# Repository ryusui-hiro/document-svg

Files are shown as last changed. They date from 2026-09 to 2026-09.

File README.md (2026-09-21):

# document-svg

**See every page of a PDF, Word, Excel, PowerPoint, diagram or CAD file as an SVG image — on your own machine, without the app that made it.**

[日本語](README.ja.md) · [简体中文](README.zh-CN.md) ·
[Project site](https://ryusui-hiro.github.io/document-svg/) ·
[Samples](https://ryusui-hiro.github.io/document-svg/samples.html) ·
[Releases](https://github.com/ryusui-hiro/document-svg/releases)






document-svg turns documents, diagrams and technical drawings into ordinary
SVG images, one per page. Any browser can show them, they stay sharp when you
zoom in, and they drop into a web page like any other picture. Alongside the
pages you get a short report that says plainly which parts could not be
reproduced exactly.

It is a converter you build into something else — a website, an internal
tool, a review process or an AI assistant — and it comes as a Node.js
package, a Python package, a Rust library and a command-line tool (`docsvg`).

| PowerPoint | Excel | draw.io | CAD drawing (DXF) |
|---|---|---|---|
| A PowerPoint slide converted to SVG | An Excel sheet converted to SVG | A draw.io diagram converted to SVG | A DXF drawing converted to SVG |

Every image above is an unretouched conversion of a sample file in this repository.

## Why use it

- **Your files stay with you.** Conversion runs on your computer or your own
  server. Nothing is uploaded, there is no account, and nothing is tracked, so
  contracts and design drawings that must not leave the company can still get
  a preview.
- **Anyone can look.** The people reviewing the result don't need Office,
  AutoCAD or a viewer licence — a browser is enough.
- **It tells you what it missed.** No converter reproduces everything. Instead
  of quietly dropping a chart or a font, document-svg lists what it skipped or
  approximated, page by page, so you can decide whether the result is good
  enough to share.
- **Opening a file never runs it.** Macros, scripts, form actions and links to
  outside resources are shown or skipped, never executed. Size and page limits
  stop a huge or broken file from exhausting memory.
- **One tool instead of many.** Office documents, PDFs, diagrams, CAD and 3D
  models, and scientific and business data all go through the same call and
  come out the same way.
- **And the way back.** SVG pages can be packaged back into PowerPoint, Word,
  Excel, draw.io or CAD files.

## What people use it for

- **Seeing document changes in code review.** A GitHub Action converts the
  slides, spreadsheets and PDFs changed in a pull request, instead of leaving
  reviewers with "binary file changed".
- **Previewing uploads in their own app,** without installing Office on the
  server or paying for a viewer SDK.
- **Keeping diagrams in step with the code** by rendering draw.io, Mermaid,
  PlantUML, D2 or Graphviz files every time the documentation is built.
- **Checking drawings and 3D models without CAD** — floor plans, circuit
  boards, machining paths and models — from a web page.
- **Letting an AI assistant read documents** through one dependable step
  instead of screenshots.

Each example is explained in more detail on the [project site](https://ryusui-hiro.github.io/document-svg/use-cases.html).

## Install

Pick the one that matches where you will call it from. You only need one.

| You want to… | Install |
|---|---|
| Convert files from a Node.js or Electron app (Node.js 18 or newer) | `npm install document-svg` |
| Convert files from Python (Python 3.10 or newer) | `python -m pip install document-svg` |
| Use the `docsvg` command, or the Rust library | `cargo install document-svg --locked` / `cargo add document-svg` |

No Rust is needed for the npm and pip packages: they come ready-made for
Windows, macOS and Linux. If you want the command without installing Rust,
download the file for your system from
[Releases](https://github.com/ryusui-hiro/document-svg/releases) and put
`docsvg` on your `PATH`.

### Where to get it and where it goes

| Package | Page | Installed into |
|---|---|---|
| npm `document-svg` | [npmjs.com/package/document-svg](https://www.npmjs.com/package/document-svg) | Your project's `node_modules/document-svg`, plus one ready-made native package for your system, such as `node_modules/document-svg-darwin-arm64` |
| PyPI `document-svg` | [pypi.org/project/document-svg](https://pypi.org/project/document-svg/) | The active environment's `site-packages/document_svg` |
| crates.io `document-svg` | [crates.io/crates/document-svg](https://crates.io/crates/document-svg) | `cargo install` puts `docsvg` in `~/.cargo/bin` (`%USERPROFILE%\.cargo\bin` on Windows); `cargo add` adds the library to your project |
| GitHub Releases | [Releases](https://github.com/ryusui-hiro/document-svg/releases) | Wherever you unpack the archive; put `docsvg` on your `PATH` |

To check what is installed and where: `npm ls document-svg`,
`python -m pip show document-svg`, or `docsvg --version`.
The Rust API reference is on [docs.rs](https://docs.rs/document-svg). An
authenticated npm mirror on GitHub Packages is described in
[docs/PUBLISHING.md](docs/PUBLISHING.md#installing-the-github-packages-mirror).

## Try it

```sh
docsvg slides.pptx --output out/slides
```

The output folder must be new or empty. You get one SVG per page and one
report of the conversion:

```text
out/slides/
├── page-0001.svg
├── page-0002.svg
└── conversion.json
```

Open a page in any browser. The report lists **warnings** — things that were
approximated or left out, such as a substituted font or an unsupported fill.
Finishing without an error is not the same as perfect: if there are warnings,
have a person look at the pages before you share them.

A "page" means what you would expect for each kind of file: a PDF page, a
slide, a printed page of a Word document, a printed page of a worksheet, or one
page of a draw.io diagram.

### From Node.js / TypeScript

```js
const { convert, preview } = require('document-svg')

async function main() {
  // Write SVG files to a folder
  const report = await convert('slides.pptx', 'out/slides')
  console.log(report.pageCount, report.warnings)

  // Or keep the pages in memory, for example to send them to a browser
  const result = await preview('slides.pptx')
  const firstPageSvg = result.pages[0].svg
  console.log('needs review:', result.needsReview)
}

main().catch(console.error)
```

Conversion runs in Node.js (a server or Electron's main process), off the main
thread. In the browser, show each page as an image with the small
`document-svg/preview-ui` helper, which does not load any native code. See the
[Node.js guide](bindings/node/README.md).

### From Python

```python
from document_svg import convert, preview

report = convert("report.docx", "out/report")
print(report["page_count"], report["warnings"])

result = preview("report.docx")          # pages in memory, no files written
first_page_svg = result["pages"][0]["svg"]
```

See the [Python guide](bindings/python/README.md).

### From Rust

```rust
use document_svg::{convert_path, ConvertOptions};

fn main() -> Result<(), document_svg::Error> {
    let report = convert_path("report.pdf", "out/report", &ConvertOptions::default())?;
    println!("{} pages, {} warnings", report.page_count, report.warnings.len());
    Ok(())
}
```

API documentation is on [docs.rs](https://docs.rs/document-svg). Every function and option for all four interfaces, with defaults, is in the [developer reference](docs/API.md) ([on the site](https://ryusui-hiro.github.io/document-svg/reference.html)).

### Only in the browser

A separate WebAssembly build converts PDF, Word, Excel and PowerPoint files
entirely inside the browser, without a server and without uploading the
file. It is not published as a package; you build it yourself from
[`bindings/wasm`](bindings/wasm/README.md). [Try it in your browser](https://ryusui-hiro.github.io/document-svg/viewer/)
before you build it.

## Show the pages in your app

Display each page as an image (for example an `<img>` element). Don't paste
the SVG markup straight into your page's HTML: the included display helpers do
basic checks, but they are not a filter that makes any SVG harmless. Text in
an image cannot be selected or searched.

Text uses the fonts available where the SVG is viewed, so it can look slightly
different on another computer. For PDFs, you can turn embedded text into
outlines when exact appearance matters more than selectable text.

## Turn SVG back into Office or CAD files

```sh
docsvg reverse out/slides --output slides.pptx
docsvg reverse out/report --output report.docx
docsvg reverse out/drawing --output drawing.dxf
```

The file extension you choose decides the format: PowerPoint, Word, Excel,
PDF, draw.io, DXF, G-code, STL and more. What comes back is how the pages
look — paragraphs, cells, formulas and charts are not rebuilt.

draw.io diagrams are the exception: convert with `--embed-drawio-source`, and
`reverse` restores the original, editable diagram.

## Supported formats

| Field | Examples |
|---|---|
| Office and documents | PDF, Word, Excel, PowerPoint (current and older formats), OpenDocument, RTF, e-mail, calendars, e-books, Markdown, HTML |
| Diagrams | draw.io, Visio, Mermaid, PlantUML, D2, Graphviz, BPMN |
| CAD, CAM and 3D | DXF, Gerber, G-code, HP-GL, STL, OBJ, STEP, IGES, glTF, IFC |
| Simulation | Gmsh, VTK, OpenFOAM, Abaqus, Nastran and other meshes |
| Data and maps | CSV, JSON, YAML, charts, LaTeX formulas, GeoJSON, KML, GeoPackage |
| Images | PNG, JPEG, TIFF, WebP, DICOM, SVG |

Some formats are drawn in full; for others, such as DWG or Access databases,
you get a clear summary of what is inside rather than the drawing. Each format
is rated A (drawn from the file's own contents), B (traced from pixels) or C
(structure such as tables inferred from the drawing).

- [Searchable format list](https://ryusui-hiro.github.io/document-svg/formats.html) — look up your file type
- [Technical format matrix](docs/FORMATS.md) — every extension with its fidelity notes
- [Supported features and limitations](docs/SUPPORT.md)

## Use it from AI assistants and GitHub

| Where | How |
|---|---|
| Claude Code | `/plugin marketplace add ryusui-hiro/document-svg`, then `/plugin install document-svg@document-svg` |
| Codex | Run `./scripts/install-codex-plugin.sh` in a checkout, then start a new task |
| GitHub Copilot | Add the setup action below to your Copilot setup steps |
| GitHub CLI | Run `./scripts/install-gh-extension.sh`, then `gh docsvg convert report.pdf --output preview/report` |
| GitHub Actions | `uses: ryusui-hiro/document-svg/.github/actions/setup-docsvg@main` |

The installers use a checksum-verified release build when Rust is not
installed. To preview the documents a pull request changes, add this workflow
to your repository:

```yaml
name: Document preview
on:
  pull_request:
    paths: ['**.pdf', '**.pptx', '**.xlsx', '**.docx']
jobs:
  preview:
    uses: ryusui-hiro/document-svg/.github/workflows/document-preview.yml@main
    permissions:
      contents: read
      pull-requests: write
```

Each changed document is converted into pages you can download from the run,
and a comment lists how many pages and warnings each one has. More in the
[GitHub and agent integration guide](docs/GITHUB_INTEGRATION.md) and the
[guide for AI agents](docs/AI_USAGE_GUIDE.md).

## Safety and limits

- Files are never uploaded, and macros, scripts and external links are never
  run or fetched.
- A PDF that needs a password to open is refused, not cracked. A PDF whose only
  restriction is an owner password (such as "no printing") opens as it would in
  any viewer; those flags are not enforced.
- Input size, archive contents and page count have limits. Don't raise them
  just to push a difficult file through.
- Existing files are never overwritten.
- If strangers can upload files to your service, run conversion in a separate,
  restricted process with memory and time limits.
- Warnings are a signal to review, not a certificate of accuracy or safety.
  Medical images and reports are not anonymized.

Read [Safety and limits](https://ryusui-hiro.github.io/document-svg/safety.html)
and the [security policy](SECURITY.md) before using it on a public service.

### Platform support and troubleshooting

| Platform (x64 and ARM64) | npm package | Python package | Command |
|---|---|---|---|
| Windows | Ready-made | Ready-made | Ready-made |
| macOS | Ready-made | Ready-made | Ready-made |
| Linux (Ubuntu, Debian and other glibc systems) | Ready-made | Ready-made | Ready-made |
| Linux (Alpine and other musl systems) | Ready-made | Built from source | Ready-made |

- If pip starts building from source, there is no ready-made package for your
  Python and system; update pip first. Building needs Rust and a C linker.
- If the npm package installs but won't load, check that optional dependencies
  were installed and that Node.js matches your machine's CPU. Copying
  `node_modules` to another system does not work.
- The SVG pages display in current browsers, resvg, and librsvg 2.46 or newer.

## Drawing cloud architecture diagrams

Separately from conversion, the repository includes a tool that builds
architecture diagrams with the official Azure, AWS and Google Cloud icons. See
the [cloud architecture guide](docs/CLOUD_ARCHITECTURE.md) and the
[business diagram templates](docs/BUSINESS_ARCHITECTURE.md).

## Contributing

```sh
cargo test --workspace --locked
```

See [CONTRIBUTING.md](CONTRIBUTING.md) for the full checks, and
[docs/ARCHITECTURE.md](docs/ARCHITECTURE.md) for how the converter is put
together. Release steps are in [docs/PUBLISHING.md](docs/PUBLISHING.md) and
changes in the [changelog](CHANGELOG.md).

## License

**MIT OR Apache-2.0**, at your option. When you redistribute the software, keep
the copyright and license notices required by the license you choose. See
[LICENSE](LICENSE), [LICENSE-MIT](LICENSE-MIT), [LICENSE-APACHE](LICENSE-APACHE)
and the bundled [third-party notices](THIRD_PARTY_LICENSES.txt).

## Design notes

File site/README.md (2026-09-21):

# document-svg project site

A static, trilingual (English / 日本語 / 中文) site for GitHub Pages: what
document-svg is for, a use-case tour, a machine-readable format support map,
and a gallery of real SVGs converted from this repository's own sample files.
It is not documentation of last resort — it exists so someone (human or AI
agent) evaluating this project can see what it does without cloning it.

Pages are plain HTML generated from two data files, so search engines and
readers without JavaScript get the full content. After editing the data, run:

```bash
python3 scripts/build-site.py
```

`tests/test_site.py` fails when the generated pages are out of date, so CI
catches a forgotten run. Do not edit the generated `.html` files or
`sitemap.xml` by hand.

```text
site/
├── index.html … ai.html    English pages (generated)
├── ja/                     Japanese pages (generated)
├── zh/                     Chinese pages (generated)
├── sitemap.xml             every page with its language alternates (generated)
├── llms.txt                machine-readable project summary for LLMs/agents
├── README.md               this file
└── assets/
    ├── style.css
    ├── app.js               behaviour only: format search, code tabs, sidebar, old-link redirects
    ├── data/
    │   ├── content.json      all page copy, per language (en/ja/zh)
    │   └── formats.json      the format support map: one source of truth
    └── samples/<key>/page-0001.svg   one representative SVG per format
```

The eight pages are: home (why use it, use cases, highlighted samples), use
cases (who, problem, result, how to begin), formats (searchable list),
samples, get started, the developer reference, safety & limits, and AI
agents. The developer reference is also written to `docs/API.md`,
`docs/API.ja.md` and `docs/API.zh-CN.md` from the same data.

Each page carries a canonical URL, `hreflang` links to its other languages,
Open Graph tags with a social preview card (`assets/og.png`, rendered from
`assets/og.svg` with `rsvg-convert assets/og.svg -o assets/og.png` from
`site/`), breadcrumb data, and (on the home page) schema.org
`SoftwareApplication` data. Links to the old single-page anchors (`#formats`, `#install`, …) and
the short-lived `?lang=` URLs are redirected by `app.js`.

## Search engines

`robots.txt` is only read at the host root (`ryusui-hiro.github.io`), which a
project site does not control, so there is none here. To get the site indexed,
add `https://ryusui-hiro.github.io/document-svg/` as a URL-prefix property in
Google Search Console and submit `sitemap.xml`.

## Previewing locally

```bash
python3 -m http.server 4173 --directory site
```

Then open <http://localhost:4173>. The pages also open directly from disk,
but the sample images and relative links behave most like the live site
over HTTP.

## Editing content

- **Format support map**: edit `assets/data/formats.json`. Each entry has
  `ext`, `forward`/`reverse` fidelity tier (`"A"`, `"B"`, `"C"`, a compound
  like `"A / C"`, or `null`), an optional `sample` key (or array of keys) into
  `assets/samples/`, and a `note` object with `en`/`ja`/`zh` strings. This file
  is also fetched directly by anyone (or any agent) who wants the format list
  as data instead of scraping HTML — keep it in sync with the matrix in
  [`docs/FORMATS.md`](../docs/FORMATS.md); they describe the same set of
  formats and should not drift apart.
- **Page copy**: edit `assets/data/content.json`. `strings.<lang>.site` holds
  the navigation and footer; every other key under `strings.<lang>` is one
  page (`home`, `useCases`, `formats`, `samples`, `start`, `safety`, `ai`),
  including its search-result title and description under `meta`.
  `start`, `safety` and `ai` are lists of sections, each of which can carry
  paragraphs, bullets, cards, a code block and links; add a section and it
  appears in the sidebar automatically. All three languages must keep the same
  keys — `tests/test_site.py` checks this. Write for people deciding whether
  to use the project: plain words, no function names, no counts or versions
  that go stale, and no claim that the README, SECURITY.md or docs/ does not
  back up. Then run `python3 scripts/build-site.py`.
- **Sample gallery**: add a folder under `assets/samples/<key>/` containing
  `page-0001.svg`, then reference `<key>` from a `formats.json` entry's
  `sample` field. Samples shown here should be generated by this repository
  (either `scripts/make_samples.py`'s regression fixtures in
  `../samples/svg/`, or a hand-authored file converted directly with
  `docsvg`) — see [`../samples/README.md`](../samples/README.md) for how
  those are produced and regenerated. Do not add third-party files.
  The GeoPackage gallery entries show both the vector and tile pages from
  reproducible `sample.gpkg`, generated by `scripts/make_samples.py`; their
  SVGs are copied from `samples/svg/gpkg/`.
- **llms.txt**: keep this in sync by hand when the entry points, safety rules,
  or documented links change; it intentionally stays short and link-first
  rather than duplicating `docs/AI_USAGE_GUIDE.md`.

## The browser viewer demo

`/viewer/` on the live site is the WebAssembly viewer from
`examples/static-viewer/`. It is not committed: `scripts/stage-pages.sh`
builds `bindings/wasm` and copies the site and the viewer into `_site/`, which
is what the Pages workflow publishes. To try the whole site locally:

```bash
sh scripts/stage-pages.sh
python3 -m http.server 4174 --directory _site
```

## Deployment

`.github/workflows/pages.yml` publishes this directory to GitHub Pages on
every push to `main` that touches `site/**`, and can also be run manually
from the Actions tab (`workflow_dispatch`). It uses
`actions/upload-pages-artifact` and `actions/deploy-pages`. The pages are
pre-generated and committed; the workflow builds only the viewer demo, with
no Jekyll. GitHub Pages must be enabled for the repository once, with the source
set to "GitHub Actions" (Settings → Pages → Build and deployment → Source).

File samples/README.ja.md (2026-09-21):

# サンプル

実際の入力ファイルと、そこから `docsvg` が作ったSVGのページを並べています。インストールする前に、仕上がりを自分の目で確かめられます。
ここにあるファイルはすべてこのリポジトリのスクリプトで作ったもので、自由に使えます。

[English](README.md) · [ギャラリーで見る](https://ryusui-hiro.github.io/document-svg/ja/samples.html)

インストール後に自分で試すには、次のように実行します（出力先は新しいフォルダか空のフォルダにします）。

```bash
docsvg samples/source/sample.pptx --output out/slides
```

出力フォルダには `page-0001.svg`、`page-0002.svg`… と、近似や省略をした箇所を書いた `conversion.json` ができます。

| | 入力 | 出力 |
|---|---|---|
| PDF | [`source/sample.pdf`](source/sample.pdf) | [`svg/pdf/`](svg/pdf/) — 2ページ |
| PPTX | [`source/sample.pptx`](source/sample.pptx) | [`svg/pptx/`](svg/pptx/) — 2ページ |
| XLSX | [`source/sample.xlsx`](source/sample.xlsx) | [`svg/xlsx/`](svg/xlsx/) — 4ページ |
| DOCX | [`source/sample.docx`](source/sample.docx) | [`svg/docx/`](svg/docx/) — 2ページ |
| Microsoft Project XML | [`source/sample.project.xml`](source/sample.project.xml) | [`svg/xml/`](svg/xml/) — 1ページ |
| drawio | [`source/sample.drawio`](source/sample.drawio) | [`svg/drawio/`](svg/drawio/) — 3ページ |
| DXF | [`source/sample.dxf`](source/sample.dxf) | [`svg/dxf/`](svg/dxf/) — 1ページ |
| Gerber | [`source/sample.gbr`](source/sample.gbr) | [`svg/gbr/`](svg/gbr/) — 1ページ |
| HP-GL | [`source/sample.plt`](source/sample.plt) | [`svg/plt/`](svg/plt/) — 1ページ |
| G-code | [`source/sample.nc`](source/sample.nc) | [`svg/nc/`](svg/nc/) — 1ページ |
| Excellon | [`source/sample.drl`](source/sample.drl) | [`svg/drl/`](svg/drl/) — 1ページ |
| STL | [`source/sample.stl`](source/sample.stl) | [`svg/stl/`](svg/stl/) — 1ページ |
| OBJ | [`source/sample.obj`](source/sample.obj) | [`svg/obj/`](svg/obj/) — 1ページ |
| VTK | [`source/sample.vtk`](source/sample.vtk) | [`svg/vtk/`](svg/vtk/) — 1ページ |
| Gmsh MSH | [`source/sample.msh`](source/sample.msh) | [`svg/msh/`](svg/msh/) — 1ページ |
| SU2 CFD mesh | [`source/sample.su2`](source/sample.su2) | [`svg/su2/`](svg/su2/) — 1ページ |
| STEP | [`source/sample.step`](source/sample.step) | [`svg/step/`](svg/step/) — 1ページ |
| IFC4 | [`source/sample.ifc`](source/sample.ifc) | [`svg/ifc/`](svg/ifc/) — 1ページ |
| IFCZIP | [`source/sample.ifczip`](source/sample.ifczip) | [`svg/ifczip/`](svg/ifczip/) — 1ページ |
| Graphviz DOT | [`source/sample.dot`](source/sample.dot) | [`svg/dot/`](svg/dot/) — 1ページ |
| Mermaid | [`source/sample.mmd`](source/sample.mmd) | [`svg/mmd/`](svg/mmd/) — 1ページ |
| LaTeX Math | [`source/sample.tex`](source/sample.tex) | [`svg/tex/`](svg/tex/) — 1ページ |
| Chart JSON | [`source/sample.chart`](source/sample.chart) | [`svg/chart/`](svg/chart/) — 1ページ |
| Markdown Table | [`source/sample.md`](source/sample.md) | [`svg/md/`](svg/md/) — 1ページ |
| QR Code | [`source/sample.qr`](source/sample.qr) | [`svg/qr/`](svg/qr/) — 1ページ |
| Raster Vectorize | [`source/sample.png`](source/sample.png) | [`svg/png/`](svg/png/) — 1ページ |
| ESRI ASCII Grid | [`source/sample-elevation.asc`](source/sample-elevation.asc) | [`svg/asc/`](svg/asc/) — 1ページ |
| dBASE III/III+ table | [`source/sample-parcels.dbf`](source/sample-parcels.dbf) | [`svg/dbf/`](svg/dbf/) — 1ページ |
| TOML configuration | [`source/sample.toml`](source/sample.toml) | [`svg/toml/`](svg/toml/) — 1ページ |
| YAML 1.2 configuration | [`source/sample.yaml`](source/sample.yaml) | [`svg/yaml/`](svg/yaml/) — 2ページ |
| Generic XML configuration | [`source/sample-config.xml`](source/sample-config.xml) | [`svg/generic-xml/`](svg/generic-xml/) — 1ページ |
| Java Properties configuration | [`source/sample.properties`](source/sample.properties) | [`svg/properties/`](svg/properties/) — 1ページ |
| BPMN 2.0 process | [`source/sample.bpmn`](source/sample.bpmn) | [`svg/bpmn/`](svg/bpmn/) — 1ページ |
| DMN 1.5 decision table | [`source/sample.dmn`](source/sample.dmn) | [`svg/dmn/`](svg/dmn/) — 1ページ |
| CMMN 1.1 case plan | [`source/sample.cmmn`](source/sample.cmmn) | [`svg/cmmn/`](svg/cmmn/) — 1ページ |
| ReqIF 1.0.1 requirements | [`source/sample.reqif`](source/sample.reqif) | [`svg/reqif/`](svg/reqif/) — 1ページ |
| XMI 2.1 UML model | [`source/sample.xmi`](source/sample.xmi) | [`svg/xmi/`](svg/xmi/) — 1ページ |
| GeoPackage | [`source/sample.gpkg`](source/sample.gpkg) | [`svg/gpkg/`](svg/gpkg/) — 2ページ |
| GeoJSON Text Sequence | [`source/sample.geojsons`](source/sample.geojsons) | [`svg/geojsons/`](svg/geojsons/) — 1ページ |
| TopoJSON | [`source/sample.topojson`](source/sample.topojson) | [`svg/topojson/`](svg/topojson/) — 1ページ |
| JSON Text Sequence | [`source/sample.jsons`](source/sample.jsons) | [`svg/jsons/`](svg/jsons/) — 1ページ |

`svg/*/page-NNNN.svg` は対応するブラウザで開けます。画像は埋め込み済みなので、
1枚だけ取り出せます。文字の見た目は表示環境のフォントによって変わる場合があります。
同じフォルダの `conversion.json` には、ページ数・所要時間・警告が記録されています。

## それぞれのサンプルが確かめていること

- **PDF** — テキスト、ベジェ曲線の塗り、線のストローク、埋め込みRGB画像、そして
  複数ページ。フォントは Helvetica を `/Widths` なしで指定しており、標準14フォントの
  字幅が正しく適用されるかを見ています。
- **PPTX** — スライドマスター、テーマ色、図形の塗り、箇条書き、16:9のスライドサイズ。
- **XLSX** — 180行のデータ、書式付きの数値、結合セル、`<pageSetup>` による用紙設定。
  1枚の紙に収まらないので、**印刷したときと同じように4ページへ分割**されます。
- **DOCX** — 見出しスタイル、罫線付きの表、明示的な改ページ、ヘッダーとフッター
  （フッターの `PAGE` フィールドはページ番号に解決されます）。
- **Microsoft Project XML** — summary/task bar、progress overlay、milestone、predecessor arrowを表示し、日程は再計算せずStart/FinishをGantt timelineに配置します。
- **drawio** — 3ページ構成。1〜2ページ目は図形と塗り、影、直交・曲線のコネクタと矢尻、エッジのラベル、
  スイムレーンと入れ子の子要素。入力は読みやすいXMLのまま置いていますが、エディタが既定で
  書き出す圧縮された `<diagram>` も同じように変換できます。3ページ目は図形ライブラリから描いた図形の例です（後述）。
- **DXF** — 建築フロアプラン図面。WALLS, DOORS, FURNITURE, TEXT などのレイヤー構造、
  LINE、ARC、CIRCLE、TEXT エンティティ、AutoCAD カラーインデックス (ACI) パレットの描画。
  `docsvg reverse <svg> --output <new.dxf>` による DXF R12 への逆変換往復もサポート。
- **Gerber (RS-274X)** — プリント基板 (PCB) パターンのベクター化。アパーチャ定義 (円形・矩形・楕円)、
  銅箔配線トレース、SMD パッド、スルーホールビア、G36/G37 ポリゴン銅箔ベタ塗り、基板基材プレビュー。
- **HP-GL / HP-GL/2** — プロッター制御言語による設計図面。ペン選択 (SP)、絶対座標プロット (PA, PD, PU)、
  円弧 (AA)、円 (CI)、ペン幅 (PW) と 8 色ペンパレットのベクター描画。
- **G-code** — CNC 加工パス。`docsvg reverse <svg> --output <restored.nc>` で G0/G1/G2 加工パスへ逆変換。
- **Excellon** — PCB ドリル穴データ。`docsvg reverse <svg> --output <restored.drl>` でドリル座標を抽出。
- **STL / OBJ** — ディフューズシェーディング付きの3Dメッシュ・アイソメトリック投影。
  `docsvg reverse <svg> --output <restored.stl>` で2.5D押し出し形状へ逆変換。
- **VTK** — VTK Legacy ASCII のスカラー場。`docsvg reverse <svg> --output <restored.vtk>` で3D PolyData メッシュへ逆変換。
- **Gmsh MSH** — 体積セルのワイヤーフレームと NodeData/ElementData フィールド。
- **SU2 CFD mesh** — zero-based connectivityと4つのnamed boundary markerを持つ2D三角meshです。境界edgeはpreviewでorangeに強調し、marker名は表示しません。
  `docsvg reverse <svg> --output <restored.msh>` で1D境界ワイヤーフレームメッシュへ逆変換。
- **STEP** — CAD Part 21 ASCII 幾何モデル。`docsvg reverse <svg> --output <restored.step>` で曲線集合・多様体サーフェスへ逆変換。
- **IFC4** — 1つのtessellated bodyを共有する2つのbuilding proxyを別々のlocal placementに配置したBIMモデルです。
- **IFCZIP** — 同じIFC4モデルをZIP archive内のroot直下に格納し、展開せずにbounded packageとして読み込みます。
- **Graphviz DOT** — マイクロサービス / クラウドインフラ構成図。DAGトポロジカルソート、階層レイアウト、角丸ノード、ベジェ曲線コネクタ、矢印。
  `docsvg reverse <svg> --output <restored.dot>` で埋め込みDOTの完全復元、未埋め込みSVGからは幾何推定復元。
- **Mermaid** — シーケンス図（OAuth2認証フロー）およびフローチャート。参加者ライフライン、同期・非同期メッセージ矢印、自動ステップ番号。
  `docsvg reverse <svg> --output <restored.mmd>` でMermaid DSLへ逆変換。
- **LaTeX Math** — 確率密度関数・数式表現。分数 (`\frac`)、平方根 (`\sqrt`)、上下添字、ギリシャ文字、総和記号 (`\sum`) の数式ボックスモデル配置。
  `docsvg reverse <svg> --output <restored.tex>` でLaTeX数式コードへ逆変換。
- **Chart (JSON)** — 棒グラフ、折れ線グラフ、円グラフ。軸目盛り、グリッド線、データ系列色分け、凡例。
  `docsvg reverse <svg> --output <restored.csv>` で数値・ラベルをCSV表データへ逆抽出、`--output <chart.png>` でresvg直接ラスタライズ。
- **Markdown Table** — GFM 仕様の表組み（インスタンス仕様・価格表）。ヘッダーセル、アライメント、背景互い違い色、境界線。
  `docsvg reverse <svg> --output <restored.md>` でMarkdown表テキストへ完全復元。
- **QR Code** — ベクター QR マトリックス生成。クリーンな単一パス (`M ... h 12 v 12 ... Z`)。
  `docsvg reverse <svg> --output <QRCode.tsx>` (React TSX)、`--output <QRCode.vue>` (Vue 3 SFC)、`--output <qrcode.datauri>` (Base64 Data URI) へのコード生成。
- **Raster Vectorize** — 手書き風署名・ビットマップ画像 (PNG/JPEG) のエッジ・輝度二値化とランレングス (RLE) ベクターパス化。
- **ESRI ASCII Grid** — NoDataを透明にしたelevation rasterを収録。continuous color ramp、min/max legend、origin/cell-size metadataを確認でき、sample生成scriptから再現できます。
- **dBASE III/III+** — numeric/text/logical/date fieldを含むparcel属性table。Windows-1252 decodeとdeleted rowのskipを確認でき、inputとSVGはsample生成scriptから再現できます。
- **TOML** — nested table、array、array-of-tables、boolean、number、timestampを含むdeployment config。設定値は不活性なdataとして表示し、実行しません。
- **YAML 1.2** — nested mapping/sequence、複数document、alias、custom tagを含むdeployment configuration。aliasはplaceholderのまま、tagは不活性に扱い、includeや設定は実行しません。
- **Generic XML** — namespace、attribute、escaped text、empty elementを含むapplication configuration。DTD/外部resourceを読み込まず、不活性な行として表示します。
- **Java Properties** — ISO-8859-1、Unicode escape、continuation、評価しない`${HOME}` placeholder、duplicate keyのlast valueを確認できます。
- **BPMN 2.0** — start/end event、user/service task、exclusive gateway、分岐ラベル、sequence flowをBPMN DIの座標から描画するorder fulfillment workflow。
- **DMN 1.5** — 2 input、3 rule、hit policy、local requirementを持つloan approval decision table。FEEL式は評価せずtext表示します。
- **CMMN 1.1** — case boundary、plan-item task、CMMNDI waypoint connector、評価しないsentry/lifecycle semanticsを含むclaims case plan。
- **ReqIF 1.0.1** — typed value、階層、XHTMLのtext平坦化、local derive relationを含むvehicle braking requirements exchange。
- **XMI 2.1** — nested package/class、attribute、operation、associationを含むUML model。model ID/typeとreferenceは不活性なtextとして表示します。
- **GeoPackage** — 内側ringを持つ2つのpolygon featureとraster tile layerを含むread-only SQLite database。GeoPackageBinary/WKB、tile-matrix extent、geometry列のみのquery、bounded PNG再エンコード、even-oddによる穴の描画を確認できます。
- **GeoJSON Text Sequence** — RFC 8142のRS delimiterで分割したFeature、LineString、FeatureCollectionを含みます。混在recordと属性省略を処理し、上限付きのmap pageを1枚生成します。
- **TopoJSON** — quantized coordinate、district間で共有して逆向きに参照する境界arc、transform付きPoint、feature property省略を確認できます。
- **JSON Text Sequence** — RFC 7464 Record Separatorで区切ったobject・array・top-level scalarを順序付きの不活性な内容として組版します。
- **SVG Transform** — `docsvg transform <svg> --output <out.svg> --minify --monochrome "#1e293b" --responsive --precision 1` による用途別再仕立て。

往復も試せます。`--embed-drawio-source` を付けて変換したSVGは、
`docsvg reverse <出力ディレクトリ> --output <新しい.drawio>` で元の図面に戻ります
（画像ではなく、編集できる図形として戻ります）。

drawioサンプルの3ページ目はシェイプライブラリの実例です。左の2つは
[`source/sample-stencils.xml`](source/sample-stencils.xml)（このリポジトリで書いた
mxStencil形式のライブラリ）から描いています。3つ目は図面自身が `shape=stencil(...)` で
持っているので、ライブラリの指定は要りません。

```bash
docsvg samples/source/sample.drawio --output out/ --stencils samples/source/sample-stencils.xml
```

drawio公式のライブラリ（AWS・Azure・GCPなど）は同梱しませんが、同じ形式なので
`--stencils` にdrawioの `stencils` ディレクトリを渡せばそのまま描けます。

## 作り直す

サンプルの入力ファイルは、外部から持ち込まずにこのリポジトリのスクリプトで生成しています。
そのためライセンスはリポジトリ本体と同じで、誰でも自由に使えます。

```bash
cargo build --release
python3 scripts/make_samples.py
```

`scripts/make_samples.py` が `source/` の各ファイルを書き直し、`docsvg` に通して
`svg/` を作り直します。レンダラーを変更したあとに実行すると、出力の変化がそのまま
差分として見えます。

> `conversion.json` の `elapsed_ms` は実行ごとに変わります。差分に出ても問題ありません。

`provenance.json`に各入力ファイルのSHA-256を記録しています。公開検査は一致するサンプルだけを許可し、テストでは生成スクリプトから再現できることも確認します。

## Webサイト向けのショーケースサンプル

[GitHub Pages サイト](../site/) では、`source/` 配下にもう一つ別のサンプル群を
手作業で用意して掲載しています。生成スクリプトが作る最小限の回帰テスト用サンプルとは違い、
より実務に近いテーマ性のあるサンプルです。上の生成スクリプトがまだ対応していない形式
（`.adoc`、`.csv`、`.d2`、`.html`、`.puml`、`.ply`）と、既存形式のよりリッチな例
（`sample-architecture.dot`、`sample-math.tex`、`sample-metrics.chart.json`、
`sample-qr.qr`、`sample-sequence.mmd`、`sample-signature.png`、`sample-table.md`）
を含みます。これらは `provenance.json` や `make_samples.py` の対象ではなく、
`docsvg` で直接変換し、その出力を `site/assets/samples/` へコピーしてギャラリーに
使っています。サンプルキーと元ファイルの対応表は
[`../site/assets/data/formats.json`](../site/assets/data/formats.json) を参照してください。

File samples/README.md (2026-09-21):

# Samples

Real input files next to the SVG pages `docsvg` made from them, so you can
judge the results before installing anything. Every file here is generated by
this repository's own scripts and may be reused freely.

[日本語](README.ja.md) · [Browse them as a gallery](https://ryusui-hiro.github.io/document-svg/samples.html)

To try one yourself after installing (the output folder must be new or empty):

```bash
docsvg samples/source/sample.pptx --output out/slides
```

Each output folder holds `page-0001.svg`, `page-0002.svg`, … and a
`conversion.json` report listing anything that was approximated.

| | Input | Output |
|---|---|---|
| PDF | [`source/sample.pdf`](source/sample.pdf) | [`svg/pdf/`](svg/pdf/) — 2 pages |
| PPTX | [`source/sample.pptx`](source/sample.pptx) | [`svg/pptx/`](svg/pptx/) — 2 pages |
| XLSX | [`source/sample.xlsx`](source/sample.xlsx) | [`svg/xlsx/`](svg/xlsx/) — 4 pages |
| DOCX | [`source/sample.docx`](source/sample.docx) | [`svg/docx/`](svg/docx/) — 2 pages |
| Microsoft Project XML | [`source/sample.project.xml`](source/sample.project.xml) | [`svg/xml/`](svg/xml/) — 1 page |
| draw.io | [`source/sample.drawio`](source/sample.drawio) | [`svg/drawio/`](svg/drawio/) — 3 pages |
| DXF | [`source/sample.dxf`](source/sample.dxf) | [`svg/dxf/`](svg/dxf/) — 1 page |
| Gerber | [`source/sample.gbr`](source/sample.gbr) | [`svg/gbr/`](svg/gbr/) — 1 page |
| HP-GL | [`source/sample.plt`](source/sample.plt) | [`svg/plt/`](svg/plt/) — 1 page |
| G-code | [`source/sample.nc`](source/sample.nc) | [`svg/nc/`](svg/nc/) — 1 page |
| Excellon | [`source/sample.drl`](source/sample.drl) | [`svg/drl/`](svg/drl/) — 1 page |
| STL | [`source/sample.stl`](source/sample.stl) | [`svg/stl/`](svg/stl/) — 1 page |
| OBJ | [`source/sample.obj`](source/sample.obj) | [`svg/obj/`](svg/obj/) — 1 page |
| VTK | [`source/sample.vtk`](source/sample.vtk) | [`svg/vtk/`](svg/vtk/) — 1 page |
| Gmsh MSH | [`source/sample.msh`](source/sample.msh) | [`svg/msh/`](svg/msh/) — 1 page |
| SU2 CFD mesh | [`source/sample.su2`](source/sample.su2) | [`svg/su2/`](svg/su2/) — 1 page |
| STEP | [`source/sample.step`](source/sample.step) | [`svg/step/`](svg/step/) — 1 page |
| IFC4 | [`source/sample.ifc`](source/sample.ifc) | [`svg/ifc/`](svg/ifc/) — 1 page |
| IFCZIP | [`source/sample.ifczip`](source/sample.ifczip) | [`svg/ifczip/`](svg/ifczip/) — 1 page |
| Graphviz DOT | [`source/sample.dot`](source/sample.dot) | [`svg/dot/`](svg/dot/) — 1 page |
| Mermaid | [`source/sample.mmd`](source/sample.mmd) | [`svg/mmd/`](svg/mmd/) — 1 page |
| LaTeX math | [`source/sample.tex`](source/sample.tex) | [`svg/tex/`](svg/tex/) — 1 page |
| Chart JSON | [`source/sample.chart`](source/sample.chart) | [`svg/chart/`](svg/chart/) — 1 page |
| Markdown table | [`source/sample.md`](source/sample.md) | [`svg/md/`](svg/md/) — 1 page |
| QR code | [`source/sample.qr`](source/sample.qr) | [`svg/qr/`](svg/qr/) — 1 page |
| Raster vectorize | [`source/sample.png`](source/sample.png) | [`svg/png/`](svg/png/) — 1 page |
| ESRI ASCII Grid | [`source/sample-elevation.asc`](source/sample-elevation.asc) | [`svg/asc/`](svg/asc/) — 1 page |
| dBASE III/III+ table | [`source/sample-parcels.dbf`](source/sample-parcels.dbf) | [`svg/dbf/`](svg/dbf/) — 1 page |
| TOML configuration | [`source/sample.toml`](source/sample.toml) | [`svg/toml/`](svg/toml/) — 1 page |
| YAML 1.2 configuration | [`source/sample.yaml`](source/sample.yaml) | [`svg/yaml/`](svg/yaml/) — 2 pages |
| Generic XML configuration | [`source/sample-config.xml`](source/sample-config.xml) | [`svg/generic-xml/`](svg/generic-xml/) — 1 page |
| Java Properties configuration | [`source/sample.properties`](source/sample.properties) | [`svg/properties/`](svg/properties/) — 1 page |
| BPMN 2.0 process | [`source/sample.bpmn`](source/sample.bpmn) | [`svg/bpmn/`](svg/bpmn/) — 1 page |
| DMN 1.5 decision table | [`source/sample.dmn`](source/sample.dmn) | [`svg/dmn/`](svg/dmn/) — 1 page |
| CMMN 1.1 case plan | [`source/sample.cmmn`](source/sample.cmmn) | [`svg/cmmn/`](svg/cmmn/) — 1 page |
| ReqIF 1.0.1 requirements | [`source/sample.reqif`](source/sample.reqif) | [`svg/reqif/`](svg/reqif/) — 1 page |
| XMI 2.1 UML model | [`source/sample.xmi`](source/sample.xmi) | [`svg/xmi/`](svg/xmi/) — 1 page |
| GeoPackage | [`source/sample.gpkg`](source/sample.gpkg) | [`svg/gpkg/`](svg/gpkg/) — 2 pages |
| GeoJSON Text Sequence | [`source/sample.geojsons`](source/sample.geojsons) | [`svg/geojsons/`](svg/geojsons/) — 1 page |
| TopoJSON | [`source/sample.topojson`](source/sample.topojson) | [`svg/topojson/`](svg/topojson/) — 1 page |
| JSON Text Sequence | [`source/sample.jsons`](source/sample.jsons) | [`svg/jsons/`](svg/jsons/) — 1 page |

Open `svg/*/page-NNNN.svg` in a compatible browser. Images are embedded, so a
single file is enough to view a page on its own. Text rendering depends on the
fonts available in your viewer. `conversion.json` in the same folder records
page count, elapsed time, and warnings for that sample.

## What each sample exercises

- **PDF** — text, filled Bézier curves, stroked lines, an embedded RGB raster
  image, and multiple pages. The font is Helvetica declared without `/Widths`,
  which checks that standard-14 font metrics are applied correctly.
- **PPTX** — slide master, theme colors, shape fills, bullet lists, and a 16:9
  slide size.
- **XLSX** — 180 rows of data, formatted numbers, merged cells, and
  `<pageSetup>` paper settings. It does not fit on one sheet of paper, so it
  **splits into 4 pages, the same way printing it would**.
- **DOCX** — heading styles, a bordered table, an explicit page break, and a
  header/footer (the footer's `PAGE` field resolves to the page number).
- **Microsoft Project XML** — a bounded Gantt preview with summary/task bars,
  progress overlays, milestones, predecessor arrows, and an unscheduled row.
- **draw.io** — 3 pages. The first two: shapes and fills, shadows, orthogonal and curved
  connectors with arrowheads, edge labels, and swimlanes with nested children.
  The third shows shapes drawn from a shape library (see below).
  The input is kept as readable XML, but the same converter equally handles
  the compressed `<diagram>` payload the editor writes by default.
- **DXF** — an architectural floor plan. Layer structure (WALLS, DOORS,
  FURNITURE, TEXT, ...), LINE/ARC/CIRCLE/TEXT entities, and the AutoCAD Color
  Index (ACI) palette. Also demonstrates the DXF R12 reverse round trip via
  `docsvg reverse <svg> --output <new.dxf>`.
- **IFC4** — two building proxies share a tessellated body and use separate local placements, under a minimal project/site/building/storey hierarchy.
- **IFCZIP** — the same IFC4 model in a root-level STEP file inside a ZIP archive, exercising bounded package inspection without extraction.
- **SU2 CFD mesh** — a triangular 2D mesh with zero-based connectivity and four named boundary markers, highlighted as orange edges in the preview.
- **Gerber (RS-274X)** — a printed circuit board (PCB) pattern: aperture
  definitions (circular, rectangular, oval), copper trace routing, SMD pads,
  through-hole vias, G36/G37 polygon copper fill, and a substrate preview.
- **HP-GL / HP-GL/2** — a plotter-language drawing: pen select (SP), absolute
  coordinate plotting (PA/PD/PU), arcs (AA), circles (CI), pen width (PW), and
  an 8-color pen palette.
- **Graphviz DOT** — a microservices / cloud-infrastructure diagram: DAG
  topological sort, hierarchical layout, rounded nodes, Bézier connectors, and
  arrowheads. `docsvg reverse <svg> --output <restored.dot>` fully restores an
  embedded DOT source, or falls back to geometric reconstruction from an SVG
  that has none.
- **Mermaid** — a sequence diagram (an OAuth2 login flow) and a flowchart:
  participant lifelines, sync/async message arrows, and automatic step
  numbering. `docsvg reverse <svg> --output <restored.mmd>` converts back to
  Mermaid DSL.
- **LaTeX math** — a probability-density formula: fractions (`\frac`), square
  roots (`\sqrt`), sub/superscripts, Greek letters, and a summation box model
  (`\sum`). `docsvg reverse <svg> --output <restored.tex>` converts back to
  LaTeX source.
- **Chart (JSON)** — bar, line, and pie charts: axis ticks, gridlines,
  per-series coloring, and a legend. `docsvg reverse <svg> --output
  <restored.csv>` extracts the underlying numbers and labels as CSV;
  `--output <chart.png>` rasterizes directly via `resvg`.
- **Markdown table** — a GFM-style table (an instance specification / pricing
  sheet): header cells, alignment, alternating row backgrounds, and borders.
  `docsvg reverse <svg> --output <restored.md>` fully restores the Markdown
  table text.
- **QR code** — a vector QR matrix as one clean path
  (`M ... h 12 v 12 ... Z`). `docsvg reverse` can also emit
  `<QRCode.tsx>` (React), `<QRCode.vue>` (Vue 3 SFC), or `<qrcode.datauri>`
  (Base64 data URI).
- **Raster vectorize** — a handwriting-style signature / bitmap image
  (PNG/JPEG): edge and luminance thresholding with run-length (RLE) vector
  path tracing.
- **ESRI ASCII Grid** — a small elevation raster with a transparent NoData
  coastline, continuous color ramp, min/max legend, and origin/cell-size
  metadata. It is generated by the reproducible sample script.
- **dBASE III/III+** — a parcel attribute table with numeric, text, logical, and
  date fields. It exercises Windows-1252 decoding and deleted-record filtering;
  the input and SVG are reproducibly generated by the sample script.
- **TOML** — a deployment configuration with nested tables, arrays, an array of
  target tables, booleans, numeric values, and a timestamp. Values are previewed
  as inert data; no setting or string is evaluated.
- **YAML 1.2** — a multi-document deployment configuration with nested mappings, sequences, an alias, and a custom tag. Aliases remain placeholders and tags are inert; no include or configuration is executed.
- **Generic XML** — an application configuration with namespaces, attributes, escaped text, and empty elements. It is rendered as inert rows; DTDs and external resources are not loaded.
- **Java Properties** — ISO-8859-1 text with escaped Unicode, a continued value, an inert `${HOME}` placeholder, and a duplicate key whose final value wins.
- **BPMN 2.0** — an order-fulfillment workflow with a start/end event, user/service tasks, an exclusive gateway, labeled branches, sequence flows, and explicit Diagram Interchange coordinates.
- **DMN 1.5** — a loan-approval decision table with two inputs, three rules, a hit policy, local input requirements, and FEEL expressions shown without evaluation.
- **CMMN 1.1** — a claims case plan with a case boundary, plan-item tasks, CMMNDI waypoint connectors, and inert sentry/lifecycle semantics.
- **ReqIF 1.0.1** — a vehicle-braking requirements exchange with typed values, hierarchy, an XHTML value flattened to text, and a local derive relation.
- **XMI 2.1** — a UML model with nested package/classes, attributes, an operation, and an association. Model IDs/types and references remain inert text.
- **GeoPackage** — a read-only SQLite database with a vector layer containing
  two polygons (one with an interior ring) and a raster tile layer, exercising
  GeoPackageBinary/WKB parsing, tile-matrix extents, geometry-only queries,
  bounded PNG re-encoding, and even-odd hole rendering.
- **GeoJSON Text Sequence** — RFC 8142 RS-delimited Feature, LineString, and
  FeatureCollection records, exercising heterogeneous records and property
  omission while assembling one bounded map page.
- **TopoJSON** — quantized coordinates, a shared district boundary referenced
  in reverse, a transformed Point and omitted feature properties.
- **JSON Text Sequence** — RFC 7464 Record Separator framing around objects,
  an array, and a top-level scalar; records are laid out in order without
  execution.
- **SVG transform** — reshaping an SVG for a specific destination with
  `docsvg transform <svg> --output <out.svg> --minify --monochrome "#1e293b"
  --responsive --precision 1`.

The round trip is testable too: convert with `--embed-drawio-source` and the
resulting SVG restores to the original drawing (editable shapes, not an
image) via `docsvg reverse <output-dir> --output <new>.drawio`.

Page 3 of the draw.io sample is a shape-library example. The first two shapes
come from [`source/sample-stencils.xml`](source/sample-stencils.xml) (an
mxStencil library written for this repository); the third carries its own
`shape=stencil(...)`, so no external library is needed for it.

```bash
docsvg samples/source/sample.drawio --output out/ --stencils samples/source/sample-stencils.xml
```

draw.io's own shape libraries (AWS, Azure, GCP, ...) are not bundled here, but
they use the same format — point `--stencils` at draw.io's `stencils`
directory and they render as-is.

## Regenerating

Sample inputs are not brought in from anywhere else — this repository's own
scripts generate them, so they carry the same license as the repository and
anyone can reuse them freely.

```bash
cargo build --release
python3 scripts/make_samples.py
```

`scripts/make_samples.py` rewrites the files in `source/` and runs them
through `docsvg` to rebuild `svg/`. Run it after changing the renderer to see
the output difference as a plain diff.

> `elapsed_ms` inside `conversion.json` changes on every run. That showing up
> in the diff is expected and not a problem.

`provenance.json` records the SHA-256 of each generated input file. The
publication check only allows samples that match it, and the test suite
confirms every sample is reproducible from the generation script.

## Showcase samples for the website

The [GitHub Pages site](../site/) additionally shows a second, hand-written
set of source files under `source/` — realistic, topical examples rather than
the generator's minimal regression fixtures, covering formats the generator
above does not yet build (`.adoc`, `.csv`, `.d2`, `.html`, `.puml`, `.ply`) and
richer variants of formats it does (`sample-architecture.dot`,
`sample-math.tex`, `sample-metrics.chart.json`, `sample-qr.qr`,
`sample-sequence.mmd`, `sample-signature.png`, `sample-table.md`). These are
not part of `provenance.json` or `make_samples.py` — they are converted
directly with `docsvg` and their SVG output is copied into
`site/assets/samples/` for the gallery. See
[`../site/assets/data/formats.json`](../site/assets/data/formats.json) for the
full mapping from sample key to source file.

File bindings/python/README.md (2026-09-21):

# document-svg for Python

**Turn PDF, Word, Excel, PowerPoint, diagram and CAD files into SVG pages from Python — locally, without Office.**

[Project site](https://ryusui-hiro.github.io/document-svg/) ·
[Formats](https://ryusui-hiro.github.io/document-svg/formats.html) ·
[Samples](https://ryusui-hiro.github.io/document-svg/samples.html) ·
[日本語](https://github.com/ryusui-hiro/document-svg/blob/main/README.ja.md) ·
[简体中文](https://github.com/ryusui-hiro/document-svg/blob/main/README.zh-CN.md)

`document-svg` turns a document, diagram or drawing into ordinary SVG images,
one per page, that any browser can show. It also tells you, page by page, what
it could not reproduce exactly, so you can decide whether the result is good
enough to use.

- **Files stay on your machine.** Nothing is uploaded and there is no account.
- **Nothing inside a file is run.** Macros, scripts and external links are shown or skipped, never executed.
- **No Office, no viewer, no headless browser.** One package handles Office files, PDFs, diagrams, CAD and 3D models, and many data formats.

The same converter is also available [for Node.js on npm](https://www.npmjs.com/package/document-svg)
and [for Rust, with the `docsvg` command, on crates.io](https://crates.io/crates/document-svg).

## Install

Requires Python 3.10 or newer.

```sh
python -m pip install document-svg
```

Install `document-svg`, import `document_svg`. Ready-made packages cover
Windows, macOS and Linux (Ubuntu, Debian and other glibc systems) on x64 and
ARM64, so you don't need Rust. On Alpine and other musl systems, pip builds
from source, which needs Rust and a C linker. This package gives you a Python
API; for the `docsvg` command, see crates.io.

The package goes into your environment's `site-packages/document_svg`.
`python -m pip show document-svg` shows the installed version and location.

## Save SVG pages to a folder

```python
from document_svg import convert

report = convert("report.pdf", "out/report")
print(report["page_count"], report["warnings"])
```

The output folder must be new or empty. It receives `page-0001.svg`,
`page-0002.svg`, … and a `conversion.json` report. Conversion runs without
holding Python's GIL, so other threads keep working.

Useful options:

- `max_pages` — stop after this many pages.
- `jobs` — convert several pages at once.
- `outline_embedded_pdf_text=True` — for PDFs, draw text as shapes so it looks
  exactly like the original on any computer (the text can no longer be
  selected).
- `embed_drawio_source=True` — for draw.io files, keep the diagram inside each
  SVG so it can later be turned back into an editable diagram.

## Get SVG pages in memory

`preview()` returns every page as SVG text without writing files — handy for
a web API or a notebook.

```python
from document_svg import preview

result = preview("slides.pptx", max_pages=20)
first_page_svg = result["pages"][0]["svg"]

if result["needs_review"]:
    print("Some parts were approximated:", result["warnings"])
```

When you show pages in a web page, show them as images (for example an
`<img>` element) rather than inserting the SVG markup into your HTML.

## Read the result before you share it

Every result has `warnings`: things that were approximated or left out, such
as a substituted font or an unsupported fill. Finishing without an error is not
the same as perfect. When there are warnings, have a person look at the pages.

Text uses the fonts available where the SVG is shown, so it can look slightly
different on another computer.

## Turn SVG pages back into files

```python
from document_svg import reverse

reverse("out/slides", "slides.pptx")   # a folder of pages
reverse("drawing.svg", "drawing.dxf")  # or a single SVG
```

The extension decides the format: PowerPoint, Word, Excel, draw.io, DXF,
G-code, Gerber, HP-GL and more. What comes back is how the pages look;
paragraphs, cells and formulas are not rebuilt. A draw.io diagram converted
with `embed_drawio_source=True` comes back editable.

## Tidy up an SVG

```python
from document_svg import transform

smaller = transform(svg, minify=True, remove_metadata=True)
```

`transform()` can also recolour to one colour, make the SVG scale to its
container, and clean up paths and empty groups. It returns `str` for `str`
input and `bytes` for `bytes` input.

## Which files work?

PDF, Word, Excel and PowerPoint (current and older formats), OpenDocument,
e-mail, e-books, draw.io, Visio, Mermaid, PlantUML, DXF, Gerber, G-code, STL,
STEP, IFC, simulation meshes, CSV, JSON, maps, images, DICOM and more. Some
formats are drawn in full; others show a summary of their contents. Look up
your file type in the [searchable format list](https://ryusui-hiro.github.io/document-svg/formats.html).

## Safety

- Treat uploaded files as untrusted. On a public service, run conversion in a
  separate process with memory and time limits.
- Input size, archive contents and page count are limited by default. Don't
  raise the limits just to push a difficult file through.
- A PDF that needs a password to open is refused.
- Medical images and reports are not anonymized: personal information in the
  file can appear in the output.

More in [Safety and limits](https://ryusui-hiro.github.io/document-svg/safety.html)
and the [security policy](https://github.com/ryusui-hiro/document-svg/blob/main/SECURITY.md).

## Reference

Every function, option, default and exception is listed in the [developer reference](https://ryusui-hiro.github.io/document-svg/reference.html#python).

## Building from source

For contributors, from `bindings/python` (Rust required):

```sh
python -m pip wheel --no-deps --wheel-dir dist .
```

## License

MIT OR Apache-2.0. See the
[repository](https://github.com/ryusui-hiro/document-svg#license) for the
license texts and third-party notices.

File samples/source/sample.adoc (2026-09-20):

= Sample System Documentation
Author: Core Engineering
v2.0, 2026-09-12

== Overview

NOTE: This system architecture is verified for memory bounded vectorization.

TIP: Compile with release flags for SIMD-accelerated raster processing.

== System Components

|===
| Component | Type | Status

| Document Core | Rust Engine | Active
| Diagram Renderer | Vector Layout | Active
| CAD Pipeline | Wireframe / Slicer | Active
| Reverse Packager | OOXML / DXF | Active
|===

[source,rust]
----
pub fn process_document(input: &Path) -> Result<Page> {
    let doc = load_file(input)?;
    doc.render_svg()
}
----

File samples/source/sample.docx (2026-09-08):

# document-svg sample

This document is written by scripts/make_samples.py so that the repository can ship a sample without borrowing someone else's file.

# What the converter reads here

Paper size and margins, style inheritance, word-aware paragraph wrapping, tables with borders, and the header and footer below.

# Supported inputs

Format | Entry point | Output
PDF | convert_path | page-NNNN.svg
PPTX | convert_path | one page per slide
XLSX | convert_path | one page per print page
DOCX | convert_path | one page per laid-out page

A page break follows, so the sample spans two pages.

# Second page

Each page of a DOCX becomes one SVG file. The footer carries a PAGE field, which the converter resolves to the page it is drawn on.

document-svg / sample document

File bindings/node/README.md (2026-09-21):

# document-svg for Node.js

**Preview PDF, Word, Excel, PowerPoint, draw.io and CAD files as SVG pages in your Node.js or Electron app — locally, without Office.**

[Project site](https://ryusui-hiro.github.io/document-svg/) ·
[Formats](https://ryusui-hiro.github.io/document-svg/formats.html) ·
[Samples](https://ryusui-hiro.github.io/document-svg/samples.html) ·
Preview guides: [English](https://github.com/ryusui-hiro/document-svg/blob/main/bindings/node/docs/preview.en.md) ·
[日本語](https://github.com/ryusui-hiro/document-svg/blob/main/bindings/node/docs/preview.ja.md) ·
[简体中文](https://github.com/ryusui-hiro/document-svg/blob/main/bindings/node/docs/preview.zh-CN.md)

`document-svg` turns a document, diagram or drawing into ordinary SVG images,
one per page, that you can show in any browser. It also tells you, page by
page, what it could not reproduce exactly, so you can decide whether a preview
is good enough to show.

- **Files stay on your server.** Nothing is uploaded and there is no account.
- **Nothing inside a file is run.** Macros, scripts and external links are shown or skipped, never executed.
- **No Office, no viewer SDK, no headless browser.** One package handles Office files, PDFs, diagrams, CAD and 3D models, and many data formats.

The same converter is also available [for Python on PyPI](https://pypi.org/project/document-svg/)
and [for Rust, with the `docsvg` command, on crates.io](https://crates.io/crates/document-svg).

## Install

Requires Node.js 18 or newer.

```sh
npm install document-svg
```

Type definitions are included. Ready-made native code is installed for
Windows, macOS and Linux on x64 and ARM64, so you don't need Rust. Keep npm's
optional dependencies enabled: that is how the right one for your machine is
chosen.

The package goes into your project's `node_modules/document-svg`, and npm adds
one native package for your system next to it (for example
`node_modules/document-svg-darwin-arm64`). `npm ls document-svg` shows the
installed version.

Conversion runs in Node.js — on a server or in Electron's main process — and
does not block the event loop. Only the small `document-svg/preview-ui` helper
is meant for the browser.

## Get SVG pages for an in-app preview

`preview()` converts a file and gives you every page as SVG text. No output
folder is needed, and temporary files are removed before it returns.

```ts
import { preview } from "document-svg"

const result = await preview("slides.pptx", { maxPages: 100 })

const firstPageSvg = result.pages[0].svg
if (result.needsReview) {
  console.log("Some parts were approximated:", result.warnings)
}
```

Send the SVG to your frontend and show it as an image with
`document-svg/preview-ui`. This helper does not load native code, so it works
in a browser bundle:

```ts
import {
  createSvgPreviewUrl,
  revokeSvgPreviewUrl,
  copySvgToClipboard,
} from "document-svg/preview-ui"

const url = createSvgPreviewUrl(firstPageSvg)
image.src = url                     // an <img> element

// When the image is replaced or the view is closed:
revokeSvgPreviewUrl(url)

// From a button click: copies the image where supported, otherwise its source
await copySvgToClipboard(firstPageSvg)
```

Show pages as images rather than inserting SVG markup into the page. The
helpers do basic checks, but they are not a filter that makes any SVG
harmless. `createSvgPreviewDataUrl()` gives a `data:` URL when a Blob URL cannot
cross a boundary, and `copySvgSourceToClipboard()` always copies the source
text. Copying needs a secure page (HTTPS or localhost) and a user action.

A complete React component with cleanup and a copy button is in
[`examples/SvgPreview.tsx`](https://github.com/ryusui-hiro/document-svg/blob/main/bindings/node/examples/SvgPreview.tsx).

## Save SVG pages to a folder

```js
const { convert } = require("document-svg")

async function main() {
  const report = await convert("report.pdf", "out/report")
  console.log(report.pageCount, report.warnings)
}

main().catch(console.error)
```

The output folder must be new or empty. It receives `page-0001.svg`,
`page-0002.svg`, … and a `conversion.json` report.

Useful options:

- `maxPages` — stop after this many pages.
- `jobs` — convert several pages at once.
- `outlineEmbeddedPdfText` — for PDFs, draw text as shapes so it looks exactly
  like the original on any computer (the text can no longer be selected).
- `embedDrawioSource` — for draw.io files, keep the diagram inside each SVG so
  it can later be turned back into an editable diagram.

## Read the result before you share it

Every result has `warnings`: things that were approximated or left out, such
as a substituted font or an unsupported fill. Finishing without an error is not
the same as perfect. When there are warnings (`needsReview` is true for
`preview()`), have a person look at the pages.

Text uses the fonts available where the SVG is shown, so it can look slightly
different on another computer.

## Turn SVG pages back into files

```js
const { reverse } = require("document-svg")

async function main() {
  await reverse("out/slides", "slides.pptx")   // a folder of pages
  await reverse("drawing.svg", "drawing.dxf")  // or a single SVG
}

main().catch(console.error)
```

The extension decides the format: PowerPoint, Word, Excel, draw.io, DXF,
G-code, Gerber, HP-GL and more. What comes back is how the pages look;
paragraphs, cells and formulas are not rebuilt. A draw.io diagram converted
with `embedDrawioSource` comes back editable.

## Tidy up an SVG

```js
const { transform } = require("document-svg")

const smaller = transform(svg, { minify: true, removeMetadata: true })
```

`transform()` can also recolour to one colour, make the SVG scale to its
container, and clean up paths and empty groups.

## Which files work?

PDF, Word, Excel and PowerPoint (current and older formats), OpenDocument,
e-mail, e-books, draw.io, Visio, Mermaid, PlantUML, DXF, Gerber, G-code, STL,
STEP, IFC, simulation meshes, CSV, JSON, maps, images and more. Some formats
are drawn in full; others show a summary of their contents. Look up your file
type in the [searchable format list](https://ryusui-hiro.github.io/document-svg/formats.html).

## Safety

- Treat uploaded files as untrusted. On a public service, run conversion in a
  separate process with memory and time limits.
- Input size, archive contents and page count are limited by default. Don't
  raise the limits just to push a difficult file through.
- A PDF that needs a password to open is refused.

More in [Safety and limits](https://ryusui-hiro.github.io/document-svg/safety.html)
and the [security policy](https://github.com/ryusui-hiro/document-svg/blob/main/SECURITY.md).

## Troubleshooting

- **The package installs but won't load.** Check that optional dependencies
  were installed and that Node.js matches your machine's CPU. Copying
  `node_modules` to another system does not work.
- **I want to convert in the browser only.** This package needs Node.js. For
  PDF, Word, Excel and PowerPoint there is a separate
  [WebAssembly build](https://github.com/ryusui-hiro/document-svg/tree/main/bindings/wasm)
  you build yourself.

## Reference

Every function, option and default is listed in the [developer reference](https://ryusui-hiro.github.io/document-svg/reference.html).

## Building from source

For contributors: `npm install && npm run build` in `bindings/node` builds the
native code for the current machine (Rust required). Maintainers publish with
the [release procedure](https://github.com/ryusui-hiro/document-svg/blob/main/docs/PUBLISHING.md).

## License

MIT OR Apache-2.0. See the
[repository](https://github.com/ryusui-hiro/document-svg#license) for the
license texts and third-party notices.

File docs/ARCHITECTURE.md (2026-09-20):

# アーキテクチャ

## 変換フロー

```text
PDF ───────────────┐
PPTX ZIP/XML ──────┤
XLSX ZIP/XML ──────┼─> Page IR ─> streaming SVG writer ─> page-NNNN.svg
DOCX ZIP/XML ──────┤                         └────────────> conversion.json
drawio mxGraphModel┤
XPS/OpenXPS ───────┤
TIFF/BigTIFF ──────┤
CBZ page images ───┤
CAD/CAE ───────────┘

SVGファイル／ディレクトリ ─> bounded SVG reader ─> package / format writer
                             ├─> Office (PPTX, DOCX, XLSX)
                             ├─> drawio（1 SVG / diagram、sourceを持つSVGは元の`<diagram>`を復元）
                             ├─> CAD / CAM (IFC, DXF, G-code, Gerber, HP-GL, Excellon, STEP, IGES)
                             ├─> 3D / CAE (STL, OBJ, PLY, 3MF, SU2, Tecplot, EnSight, PLOT3D, VRML, Gmsh, VTK, OpenDRIVE, OpenSCENARIO)
                             ├─> Data / Math (CSV, Markdown, LaTeX)
                             ├─> Web / UI (HTML viewer, React JSX/TSX, Vue 3, Svelte, SVG path)
                             └─> Raster (PNG, WebP)
```

drawioは`mxfile`の`<diagram>`ごとに1ページを生成します。本文は生XMLか、`encodeURIComponent`＋raw deflate＋base64のいずれかで、後者は`max_zip_entry_bytes`を上限に展開します。モデル座標はCSSピクセルなので、page rootの1 groupがピクセル→ポイント変換とcropのoffsetをまとめて持ち、図形geometry、線幅、font sizeを同じ倍率で保ちます。

全入力形式は`Page`、`Node::{Path,Text,Image,Group}`、`Paint`、`Stroke`、`ClipPath`、`MaskDefinition`からなる共通IRへ正規化します。座標はポイント、変換はSVGと同じ6要素アフィン行列です。`TextRun`はrun全体の期待advanceに加え、PDF由来の証明可能なglyph x originも保持できます。SVGライターは入力順と固定精度で直列化し、属性順も決定的です。

## 言語バインディング

```text
Python ─> PyO3 / GIL detach ─┐
                              ├─> convert ─> SVGページ + report
                              ├─> preview ─> メモリ上SVG文字列 + report
                              ├─> transform ─> 最適化/メタデータ削除済みSVG
Node.js ─> napi AsyncTask ───┼─> convert / preview / transform
                              └─> reverse ─> Office / CAD / Web / ラスター形式

Browser Worker ─> wasm-bindgen ─> convert_bytes ─> page callback ─> SVG + text geometry
```

`bindings/python`と`bindings/node`はパーサーやIRを再実装せず、パス、
`ConvertOptions`、`ConversionReport`、言語固有エラーの変換だけを担当します。
PythonはJSON経由で`dict`へ変換し、Node.jsは型付きNode-API objectへ直接変換します。
Node.jsの`preview`は同じ`convert_path`を専用一時ディレクトリに対して実行し、生成SVGを
1ページ64 MiB・全ページ256 MiBの既定上限内でUTF-8文字列として読み込みます。一時
ディレクトリは成功・失敗のどちらでもRAIIで削除されます。
`document-svg/preview-ui`はネイティブbindingから独立したbrowser-safeなJavaScript
subpathです。Blob URLの生成・破棄とClipboard APIのSVG MIME／text fallbackだけを担当し、
文書parserやファイルシステム処理をrendererへ持ち込みません。
`bindings/wasm`はファイル名と`&[u8]`を受け取るin-memory変換経路を使います。対象は
PDF/DOCX/XLSX/PPTXで、PDFはページ単位、OOXMLは必要partだけをseek可能なmemory cursorから
読み、`PageConsumer`がSVGとテキスト位置をWorkerへ逐次返します。静的デモはWorker内で
同期WASMを実行し、document bytesはWebサーバーへ送りません。検索・選択用のテキスト幾何も
boundedな別レイヤーとして送り、元のページSVGは`<img>` Blob URLとして表示します。
ブラウザ版はSQLite/DICOM/legacy Officeをビルド対象から外し、JPEG 2000は安全な警告付き
SVGフォールバックにします。既定で入力64 MiB、拡張part 32 MiB、全SVG 128 MiB、テキスト位置
50,000 span/8 MiBに制限します。上限を超えたテキスト位置はwarningとして返し、ページ画像自体は
継続して表示します。
ネイティブホストに組み込まれるためrelease profileは`panic = "unwind"`とし、
バインディング境界がエラーへ変換できる設定にします。

PDF効果は、要素自身のtransformと混同しないようidentity座標の外側groupへ適用します。soft mask、blend、isolationは外側group、geometry transformは内側nodeです。複数clipは定義同士を参照せず、親clipから順に外側groupを重ねるため、librsvgやブラウザ間で安定して交差します。

## メモリ設計

- 入力全体: `max_input_bytes`で事前制限します。
- OOXML: ZIP中央ディレクトリだけを開き、必要なpartを1件ずつ読みます。展開後の各partは`max_zip_entry_bytes`で制限します。
- TIFF/BigTIFF: 画像directoryごとにdecodeし、decoder buffer、ページ/全体pixel数、PNG data URI、`max_pages`を制限します。planar imageは全planeの出力長を検査します。
- Standalone JPEG 2000: the native-only converter reuses the codestream/JP2 SIZ preflight already used by PDF and DICOM, validates component precision/dimensions/signedness before OpenJPEG allocation, then emits an 8-bit PNG-backed page for grayscale, gray-alpha, RGB or RGBA images.
- CBZ: archive pathを抽出せず、PNG/JPEG memberだけをnatural filename orderで1ページずつ処理します。`max_zip_entry_bytes`と固定上限でentry数、画像名の合計、画像サイズ、ページ/全体pixel数、総data URI bytesを制限します。
- Abaqus INP: flat meshとpart/instance meshをparseし、各instanceのtranslation後にaxis-angle rotationを適用して共通simulation rendererへ渡します。外部include、非Cartesian node system、analysis fields/materialsは読み込まず、対応外要素等はwarning/errorにします。
- Nastran Bulk Data: bounded UTF-8/ASCII parserでGRIDとfree/small/large-field structural cardsを読み、external INCLUDEやsolver dataを解釈せず共通simulation rendererへ渡します。nonzero GRID CPは拒否し、高次要素をcorner meshへ簡略化、3D meshはXY投影します。
- SU2 native mesh: bounded ASCII parserで`NDIME`/`NELEM`/`NPOIN`/`NMARK`のgeometryだけを読み、2D cellまたは3D volume-edge outlineを共通simulation rendererへ渡します。zero-based connectivityを検査し、3DはXY投影、solver boundary conditionsは評価しません。
- Tecplot ASCII: `TITLE`/`VARIABLES`/`ZONE`を上限付きで読み、POINT/BLOCKの線形有限要素zoneとordered I/J gridを共通simulation rendererへ渡します。X/Yと1-based connectivityを検査し、追加の数値変数を不活性scalarとして使います。zone metadataやsolver/macroは評価しません。
- EnSight Gold ASCII: case manifestのgeometry modelをcase root内へcanonicalizeし、`part`/`coordinates`/linear element blockを検証して共通simulation rendererへ渡します。variable file、binary case、外部path、`nsided`/`nfaced`は評価しません。
- PLOT3D formatted ASCII: single/multi-blockの`ni`/`nj`/`nk`とX/Y/Z配列を上限付きで検証し、I-fastestのstructured cellを共有simulation rendererへ渡します。3Dはboundary surfaceだけを描画し、unformatted Fortran、IBLANK、solution `.q`は評価しません。
- VRML97: `Coordinate`のXYZと`IndexedFaceSet`/`IndexedLineSet`の`coordIndex`だけをboundedに抽出し、生成したvalidated meshを陰影付きOBJ rendererへ渡します。TextureCoordinate、transform、appearance、script、route、外部URLは評価しません。
- SYLK/DIF: cell/tuple coordinates and cached values are parsed into the shared paginated table renderer. Formula strings, advisory dimensions, formatting metadata and external content remain inert.
- FASTA/FASTQ: sequence and quality records are bounded before table rendering; FASTQ sequence/quality length is checked, while identifiers are treated as text and no alignment or Phred conversion is performed.
- GFF3/GTF: 9列feature recordsを座標・strand・phase・attributesの検証後に不活性tableへ渡します。directiveと埋め込みFASTAは読み込まず、sequence解析や外部link解決はしません。
- BED/bedGraph: 0-based half-open genomic intervalsを12列まで検証し、block listとfinite signal値を不活性表へ渡します。track/browserやremote genome/trackは解決しません。
- VCF: `#CHROM`の8固定列とFORMAT/sample列を上限付き表へ渡し、POS/QUAL/field長を検証します。reference URL、genotype/phasing、埋め込みFASTAは不活性です。`.vcf`はvCardと内容署名で区別します。
- SAM: 11 mandatory alignment fieldsとoptional TAG:TYPE:VALUEをbounded tableへ渡し、CIGAR/SEQ/QUALとtag重複を検証します。reference genome、projection、genotype/phasing、外部resourceは評価しません。
- WIG/Wiggle: `fixedStep`/`variableStep`を1-based fully-closed interval rowsへboundedに展開し、step/spanとfinite signalを検証します。track/browserと外部trackは評価しません。
- MAF: `a`/`s` alignment blockを座標・strand・size・sequence長検証後に不活性表へ渡し、`i/e/q`とコメントは診断に留めます。reference lookupとcoordinate liftは実行しません。
- Newick: 最初の`;`までの括弧/カンマtopologyをbounded recursive descentで共有`DiagramGraph`へ変換し、quoted/unquoted label、finite branch length、nested bracket commentを検証します。追加tree、taxonomy、sequence lookup、rooting/distance計算は扱いません。
- Stockholm: `# STOCKHOLM 1.x`と`//`区切りのalignment blockを読み、分割sequence rowを連結して共有table rendererへ渡します。`#=GF/GS/GC/GR` annotationは不活性metadataとして扱い、sequence長一致・入力/行/byte上限を検証します。
- CLUSTAL: header後のblockごとのsequence fragmentをname別に連結し、任意のresidue countと`* : . +` consensus lineを不活性として共有table rendererへ渡します。aligned length一致、行長/name/sequence byte上限を検証します。
- NEXUS: `#NEXUS`の`BEGIN TREES`から最初の`TREE/UTREE`文を安全に切り出し、Newick parserと共通`DiagramGraph` rendererを再利用します。TAXA/TRANSLATE/他blockは外部解決せず診断に留めます。
- GenBank: `LOCUS`から`//`までをbounded recordとして読み、固定幅FEATURESを件数化し、ORIGINの配列文字を検証して共通table rendererへ渡します。accession、feature location、外部sequenceは解決しません。
- EMBL-Bank: 2文字tagのID/AC/DE/FT/SQを`//`単位にbounded parseし、FT固定幅featureを件数化、SQ行の累積countと配列文字を検証して共通table rendererへ渡します。DB cross-referenceと外部sequenceは解決しません。
- UniProtKB: `Reviewed;`/`Unreviewed;`を含むID signatureで`.dat`をTecplot/generic textと分離し、ID/AC/DE/GN/OS/FT/SQを`//`単位にbounded parseします。protein metadataとfeature件数を共通tableへ渡し、REST/APIやcross-referenceは呼びません。
- RIS: `TY  -`をrecord開始、`ER  -`を終了とするcanonical tag行を検証し、繰り返し著者/keywordと6-space continuationを共通table rendererへ渡します。DOI/URLや外部citation resourceは解決しません。
- SPICE: title以後のelement cardと`+` continuationを論理行へboundedに結合し、device prefixごとの最小node数、node/value byte上限を検証して不活性tableへ渡します。dot command、include/lib path、model、control sectionは実行・openしません。
- KiCad legacy Eeschema: `$Comp`/`Wire Wire Line`/`Text Label`/`Connection ~`をmilsからpage-fitしたIRへ変換し、symbol libraryやcache.libに依存しない簡略component/wire描画を行います。modern `.kicad_sch`、gEDA、Eagleは別形式として扱います。
- KiCad modern schematic: PCB S-expression arenaを共用し、`lib_id`付きsymbol instance、property、`wire`/`bus`の`xy`、label/text/junctionを抽出してmm座標の簡略IRへ変換します。`lib_symbols`定義、pin connectivity、hierarchy、image/model、ERC/DRCは解析しません。
- LTspice: `Version`/`SHEET`から始まる行指向`.asc`をUTF-8/UTF-16でbounded decodeし、WIRE/FLAG/SYMBOL/SYMATTR/TEXTと基本graphicを簡略IRへ渡します。`.asc`のESRI Grid署名を先に判定し、`.asy`/model/includeとsimulatorは呼びません。
- EAGLE XML: `<eagle>` root署名の`.sch`だけをquick-xmlで解析し、parts/instancesとplain/netのwire・label・textを座標検証後に簡略IRへ渡します。KiCad/gEDA/Eagle以外の`.sch`は誤認せず、外部library/スクリプト/DRCは評価しません。
- LS-DYNA Keyword: bounded UTF-8 parserで`*NODE`とshell/solid/beam element cardsを読み、standard/comma-free rowsを共通simulation rendererへ渡します。long-format、structured decks、外部INCLUDE、solver properties/resultsは解釈せず、high-order geometryをcorner meshへ簡略化します。
- Jupyter `.ipynb`: bounded nbformat-4 JSONをMarkdown/HTML block rendererへ変換します。cell順とhidden metadata、text/HTML/JSON/error/PNG/JPEG outputを扱い、codeは実行しません。interactive/SVG outputsとattachment、外部参照は表示しません。
- Jupyter image output: PNG/JPEG signature/decode validation happens before data-URI embedding, with per-image/aggregate encoded-byte and pixel limits; SVG MIME and remote/attachment images remain unembedded.
- Quarto/R Markdown: bounded Markdown sourceとsimple YAML metadataをHTML block rendererへ渡し、code chunksやinline codeはsource表示のみとします。YAMLのその他設定、filters、cross-references、includes、code executionは行いません。
- Microsoft Project XML: DTDを拒否するbounded `quick-xml` parserでtask date/progress/dependency fieldsだけを抽出し、limits適用後に25-task Gantt pagesをPageConsumerへstreamingします。外部resourceは読まず、calendar/schedule engineは起動しません。
- KiCad PCB: a bounded UTF-8 S-expression arena shares source slices, caps nesting/tokens/text/geometry, and emits common tracks/pads/outlines plus cached zone polygons. External libraries, images and 3D models are never opened.
- OFF: ASCII COFF/NOFF polygon records are validated, converted to bounded OBJ text, and rendered through the existing shaded 3D mesh path. Binary/4D data and optional colors/normals are not imported.
- IFC-SPF/IFCXML/IFCZIP: a bounded ZIP reader selects one root-level `.ifc` model without extracting the package. The Part 21 and bounded buildingSMART IFCXML readers resolve IFC4 tessellated faces and common `IfcExtrudedAreaSolid` profiles (rectangle, 64-segment circle, closed 2D polyline) through product shape representations and local placements. IFCXML internal IDs are indexed in-memory; DTDs and external URI references are never processed. Both readers expand nested `IfcMappedItem`/`IfcRepresentationMap` references with mapping-origin inversion and bounded 3D Cartesian transforms, checking cycles and total expanded mesh size. Convex polygons use fan triangulation; simple concave polygons up to 256 vertices use bounded ear clipping. IFCZIP sidecar resources are ignored.
- dBASE III/III+ `.dbf`: the reader validates bounded fixed-width headers/records, decodes common `.cpg` encodings, skips deleted rows, and renders 100-row/32-column batches. Memo files and unsupported binary field types are not opened.
- TOML: a bounded TOML 1.1 parser renders nested tables, arrays and scalar values as inert key paths. It enforces line, recursion, value, string, path and rendered-text limits; configuration is never evaluated.
- YAML: a bounded event-driven YAML 1.2 parser renders multiple documents and nested values as inert key paths. Aliases are not expanded, custom tags are not applied, complex keys are rejected, and event, depth, document, scalar, path and rendered-text limits are enforced.
- Generic XML: unrecognized XML falls back to a bounded namespace-aware element/attribute/text preview. DTDs are rejected, so external entities are never loaded; recognized Project, draw.io, SVG, HTML and other XML formats keep their specialized converters.
- Java Properties: a bounded ISO-8859-1 line parser decodes Java escapes and continuations, then renders inert key/value rows. Duplicate keys use the last value as `Properties.load` does; variable expansion is not performed.
- BPMN 2.0: the bounded XML tree resolves BPMN model IDs against BPMN Diagram Interchange shapes/edges and their explicit coordinates. It draws common events, activities, gateways and sequence flows without executing process semantics; diagrams without DI geometry are rejected.
- DMN 1.1–1.5: decision tables become bounded inert SVG tables; local requirement references are resolved, but FEEL and hit-policy evaluation never run. External references, DMNDI diagram layout and unsupported decision logic are omitted or warned.
- CMMN 1.1: the bounded XML tree resolves case-plan model IDs to CMMNDI Bounds and waypoints, drawing plan items and connectors while leaving sentries and lifecycle semantics inert.
- ReqIF: the bounded XML tree indexes specification objects, typed values, hierarchy references and local relations into requirement tables. XHTML is flattened, and no external or tool-specific content is processed.
- XMI: model elements are traversed as a bounded containment tree, with qualified xmi:id/xmi:type and attribute references retained as text. External links and model semantics are never resolved or executed.
- CSV/TSV: the parser enforces quote placement, doubled-quote escaping, row/field/cell limits and bounded page count before emitting 100-row/32-column batches. It embeds exact input only for a one-page source of at most 8 MiB; other files keep visual pages without duplicating the source payload.
- ARFF: the bounded Weka dataset parser validates flat `@relation`/`@attribute` headers, dense CSV-like records, and sparse zero-default records before reusing the paginated table renderer. Relation-valued attributes and value evaluation stay inert; line, attribute, record, cell, and value limits are enforced.
- JSON-LD: a bounded JSON tree walker turns `@id`/`@type` nodes, compact predicates, literals, lists, included nodes, and named graphs into inert RDF-style rows. Contexts stay compact and remote `@context`/`@import` references are never resolved; depth, value, statement, term, and rendered-text limits apply.
- OpenAPI/Swagger: JSON uses a bounded tree walk while YAML is validated through the event parser before a conservative indentation scan extracts specification metadata and HTTP operations. `$ref`, externalDocs, servers, callbacks, links, examples, and security schemes remain inert; no reference resolution, network access, or API execution occurs.
- WSDL: a bounded XML tree indexes services, ports, bindings, interfaces/portTypes, operations, messages, imports/includes and embedded schemas into inert rows. Endpoint addresses and external schema/import locations remain unvisited.
- OPML: a bounded XML tree walks the required head/body outline hierarchy and emits inert title, type, depth and feed-outline metadata. Feed URLs, owner addresses and extension values remain unvisited.
- RSS/Atom feeds: a bounded XML tree summarizes channel/feed and item/entry title/date plus link, author, content and enclosure counts. Link targets and payload text remain unvisited.
- Apple Property Lists: XML dictionaries/arrays are flattened into bounded key paths and typed rows; binary `bplist00` trailers, offset tables and object markers are preflighted without dereferencing arbitrary payloads.
- TEI P5: a bounded XML tree extracts `teiHeader` metadata and walks common `text/body` division, heading, paragraph, note, list, figure and table structures. Targets and facsimile resources remain inert.
- ALTO: a bounded XML tree indexes `Layout/Page/TextLine/String` OCR structure and validated `WC` confidence values; source image references and processing metadata remain inert.
- METS: a bounded XML tree summarizes `fileSec`/`fileGrp` files and nested `structMap` divisions, while `fptr`/`mptr`/location references are counted but never dereferenced.
- MARCXML: a bounded XML tree walks record/leader/controlfield/datafield/subfield structure, redacting URL field values and leaving catalog references inert.
- MODS: a bounded XML tree extracts title/name/origin/genre/subject/identifier/location structure; authority and location URIs remain unvisited.
- MARC21 ISO 2709: a bounded binary reader validates leader/directory/field boundaries and emits control/data/subfield rows; `.mrc` stays assigned to microscopy volumes.
- PREMIS: a bounded XML walk counts and summarizes Object, Event, Agent and Rights entities while redacting checksums, URIs and preservation payloads.
- IIIF Presentation: a bounded JSON walk summarizes Manifest/Collection labels, Canvases, painting annotations, ranges and dimensions without dereferencing image services or annotation IDs.
- EAD: a bounded XML walk extracts finding-aid repository/title metadata and nested component levels/titles/dates while leaving digital-object references inert.
- EAC-CPF: a bounded XML walk extracts authority identity names and entity/relation counts while leaving authority URIs, biographies and targets inert.
- Dublin Core XML: a bounded XML walk keeps descriptive DCMI elements as safe value rows while suppressing identifier/relation/rights/description payloads and URLs.
- ISO 19115/19139: a bounded XML walk summarizes identification, dates/topics, hierarchy/language, CRS codes, geographic bounding boxes and quality/distribution counts while suppressing abstract/lineage, contact, identifier and online-resource payloads.
- DICOM Structured Reports: the existing bounded Part 10 parser validates SR SOP classes and walks Content Sequence items recursively, exposing safe value types/concepts/units while keeping referenced objects, UIDs and patient/study attributes inert.
- UBL: a bounded XML walk recognizes namespaced Invoice/Order and related document roots, emits dates/currency and structural counts, and suppresses party, amount, identifier, attachment and URL payloads.
- XBRL: a bounded XML walk indexes instance contexts and units, then emits deterministic top-level fact rows with period/unit/precision metadata while suppressing entity identifiers, taxonomy/linkbase references and URLs.
- FDF: the PDF object parser is fed a normalized bounded FDF signature, then walks `/FDF/Fields` dictionaries recursively with password/value/action limits; form submission, JavaScript and embedded resources remain inert.
- XFDF: a bounded XML walk emits fully-qualified field/value rows, sensitive-field masks and annotation/target counts while keeping PDF references, rich text, actions and URLs inert.
- LandXML: a bounded XML walk summarizes namespaced civil roots, TIN surface counts, alignment segment counts, survey points, parcels and pipe networks while suppressing coordinate and external-reference payloads.
- MathML: a bounded XML walk converts presentation tokens and common layout schemata into deterministic formula text while suppressing annotation-xml, images, scripts and URLs.
- XMP: a bounded RDF/XML walk emits common descriptive properties and packet counts while suppressing identifiers, thumbnails, URLs, private schemas and embedded binary payloads.
- XDP: a bounded XML walk inventories XFA packet and field structure while leaving field values, embedded packets, scripts, events, submit actions and external references inert.
- SpreadsheetML: a bounded XML walk emits Office 2003 XML Spreadsheet worksheet/cell values and formula presence while leaving styles, macros, links and recalculation inert.
- CML: a bounded XML walk summarizes molecule/reaction/spectrum structure and element distributions while suppressing coordinates, dictionaries, URLs and chemistry calculations.
- RDF/XML: a bounded XML walk emits predicate/literal rows and node/IRI counts while suppressing resource URLs, nested XML literals, vocabulary resolution and inference.
- BCFZIP: a bounded ZIP reader validates `bcf.version` and `markup.bcf`, then summarizes project/topic metadata and markup counts. Snapshots, IFC/model payloads, document URLs and collaboration actions are never opened or executed.
- Flat OPC: a bounded XML reader validates the Office XML package namespace and part names, reconstructs XML/base64 parts into an in-memory ZIP, and delegates to the existing DOCX/XLSX/PPTX renderers. The temporary package never touches disk and active/external content remains inert.
- AASX: a bounded OPC relationship walk locates the AAS origin and specification parts, parses only XML/JSON shell metadata, and records supplementary-file/thumbnail counts. CAD, manuals, URLs, signatures and encryption payloads are not opened.
- OpenSCAD: a bounded line scanner strips comments and counts source constructs without invoking the OpenSCAD interpreter. import/use/include paths and surface/file references remain inert.
- AMF: a bounded XML walk converts object-local vertices and volume triangles to an in-memory OBJ stream, then reuses the shaded mesh renderer. Material, texture, lattice, slice and external reference data remain inert.
- PLMXML: a bounded XML walk summarizes product definitions, assembly structures, representations and external-reference counts without resolving IDs, URLs or referenced CAD geometry.
- STEP-XML: a bounded XML walk recognizes ISO 10303-28 roots and summarizes EXPRESS-mapped product, assembly, representation and geometry element counts without schema resolution or external CAD access.
- QIF: a bounded XML walk summarizes product, inspection-plan/result, feature, characteristic, datum and traceability structure while keeping measured values and external inspection files inert.
- B2MML: a bounded XML walk summarizes ISA-95 manufacturing schedules, performance, resources and process segments while keeping operations, values, credentials and external resources inert.
- JDF/JMF: a bounded XML walk summarizes CIP4 job nodes, resources, processes and print-production references while never sending commands or following links.
- S1000D: a bounded XML walk extracts DMC code attributes and common data-module content while leaving DM/ICN references, graphics and publication assembly inert.
- AsyncAPI: JSON uses the same bounded tree walk pattern and YAML is validated before a conservative indentation scan extracts channels, publish/subscribe actions, and operation metadata. AsyncAPI 3.x top-level send/receive operations are supported; references, server URLs, protocol bindings, examples, and security schemes remain inert.
- JSON Schema: a bounded JSON tree walk emits root metadata and nested property/definition paths with type and constraint summaries. YAML is validated by the existing event parser before conservative property extraction; `$ref`, URI values, patterns, examples, and format annotations are never resolved or evaluated.
- ANSYS CDB: the CAE simulation layer reads only fixed-width ASCII `NBLOCK` and `EBLOCK` mesh sections (with basic `N`/`EN` fallback), validates IDs/connectivity and passes `MeshNode`/`MeshCell` data to the shared renderer. APDL commands and include paths stay inert; Z is projected onto XY with a warning.
- HAR: a bounded JSON tree walk extracts request/response metadata and timings while masking secret-like query values and dropping headers, cookies, and bodies. URLs remain inert and no network replay or resource lookup occurs.
- WARC: a bounded record-frame reader validates header delimiters and `Content-Length`, skips payload bytes, and summarizes embedded HTTP status/MIME. Plain and gzip streams share the same size limits; target URIs remain inert and secret-like query values are masked.
- WACZ: the ZIP package layer validates entry counts and reads only `datapackage.json` plus `pages/pages.jsonl`; archive WARC payloads and CDXJ indexes are intentionally not opened. Page metadata uses the same inert URL masking boundary as WARC/HAR.
- Postman Collection: a bounded JSON tree walk recursively flattens folder/request items into an inert request inventory. URL query secrets are masked while auth credentials, variables, scripts, headers, cookies, and bodies are omitted; no collection runner or network client is invoked.
- GraphQL SDL: a bounded line parser tracks definition braces and argument lists, then emits type/interface/input/enum/scalar/union fields and signatures. Descriptions, directives, default values and URLs remain inert text; no GraphQL execution or introspection transport is used.
- Protocol Buffers: a bounded line parser tracks message/enum/service/oneof braces and emits field numbers, types, options and RPC signatures. Imports, options, annotations and defaults remain inert; no `protoc`, external file or RPC call is invoked.
- Kubernetes manifests: JSON uses a bounded object walk for resource identities and `List.items`, while YAML is validated through the event parser before extracting multiple `apiVersion`/`kind`/`metadata` documents. Secret values and spec payloads remain omitted; no kubectl, Helm, cluster request, or external reference is used.
- Docker Compose: JSON uses a bounded object walk for the required `services` map; YAML is validated through the event parser before a conservative indentation scan extracts service image/build and resource-reference counts. Commands, healthchecks, environment/config/secret values, interpolation, include/merge semantics and all Docker runtime operations remain inert.
- GitHub Actions workflows: YAML is validated through the event parser before a bounded indentation scan extracts the workflow name, triggers, job runners, `needs`, steps, action/run counts and strategy presence. Shell commands, expressions, secrets, environments, permissions, reusable workflows and runner/network operations remain inert.
- JUnit-compatible reports: the shared bounded XML tree validates `testsuite`/`testsuites` roots, then suite children are summarized from testcase outcome elements and safe attributes. Failure/error logs, stdout/stderr, properties, attachments and external resources are never rendered or executed.
- SARIF 2.1.0: a bounded JSON walk validates the version and `runs` array, resolves only safe tool/rule identifiers and default levels, and aggregates result severities by tool/rule. Messages, locations, URIs, snippets, fingerprints, fixes and invocation data remain omitted; no upload or code-scanning API is called.
- Terraform JSON plans: a bounded JSON walk validates major format version 1 and extracts only `resource_changes` addresses, types, action sets and action reasons, plus aggregate drift/output/variable counts. `before`/`after`/`sensitive_values`, state, configuration and provider data stay omitted; no Terraform command or provider/network operation is invoked.
- CycloneDX BOMs: bounded JSON validation checks `bomFormat`/`specVersion`, while the shared XML tree checks the CycloneDX BOM namespace. Component type/name/version/scope rows are emitted with aggregate dependency/vulnerability/service counts; serials, refs, hashes, licenses, PURLs, properties, vulnerability details and external references remain inert.
- SPDX 2.x JSON/tag:value: bounded JSON validation checks the `spdxVersion`/`SPDXID` signature; the tag:value scanner bounds lines and extracts only package/file identity fields. Both paths emit relationship, annotation, snippet and external-document counts while checksums, licenses, suppliers, PURLs, download locations, comments and URIs remain omitted.
- JaCoCo/Cobertura coverage XML: the shared bounded XML tree accepts `report` or `coverage` roots, extracts package-level class counts and safe `counter` or rate attributes, and emits covered/missed summaries. Source files, session data, logs, attachments and quality gates remain inert.
- LCOV: a bounded line parser handles tracefile sections and counter records, reduces `SF` paths to basenames, and emits file-level line/function/branch summaries. `DA`/`BRDA` execution records and function names remain omitted; no source or runtime data is opened.
- ASAM OpenDRIVE: a bounded XML tree reads local road `planView` geometry, tessellates line/constant-curvature arc reference lines, normalizes metre coordinates into a planar map, and leaves lanes, profiles, signals, objects, links and simulation behavior inert.
- ASAM OpenCRG: a bounded line scanner reads only clear-text section headers and line counts; road-surface ASCII/binary payloads and file references are not decoded or followed.
- ASAM OpenSCENARIO: a bounded XML tree indexes FileHeader, ScenarioObject entities, Storyboard hierarchy, parameter declarations, catalog references and RoadNetwork presence into inert tables. Catalog paths, controllers, expressions, triggers and simulator semantics are never resolved or executed.
- ASAM OpenLABEL: a bounded JSON walk validates the `openlabel` envelope, counts annotation collection maps and nested object/frame data, and emits collection rows. Sensor payloads, coordinates, values, ontology URLs and resources remain inert.
- CityGML: a bounded XML tree counts thematic city objects, LoD tags, Envelope/CRS and XLinks into inert tables; geometry, textures, attributes and external resources stay omitted.
- CityJSON: a bounded JSON walk validates CityObjects, shared vertices, transform arrays and geometry boundary indices, then emits type/geometry/LoD counts without expanding coordinates or semantic payloads.
- STIX JSON: a bounded JSON walk validates bundle/object envelopes, counts object types, labels and reference arrays, and emits inert type/id/timestamp rows. Indicator patterns, descriptions, hashes, URLs, marking content and custom properties stay omitted; no TAXII/API/network operation runs.
- TAXII JSON: a bounded envelope/resource walk distinguishes object envelopes, manifests, collections, discovery, status and error resources and emits counts. STIX payloads, URLs, authorization metadata and endpoints remain inert; no HTTP/TAXII client is invoked.
- OpenFOAM fields: a standalone bounded lexer validates the ASCII `FoamFile` header, reads scalar/vector uniform or nonuniform internal fields into streaming min/max statistics, and counts boundary patch dictionaries. It does not traverse cases, evaluate dimensions or boundary conditions, or launch a solver.
- JSON Patch: a bounded JSON walk validates RFC 6902 operation requirements, emits ordered op/path/from/value-type rows, and aggregates operation kinds. Values, target documents and pointer evaluation stay inert; no patch mutation occurs.
- JSON Merge Patch: an explicitly routed bounded JSON walk traverses object members into escaped paths and emits set/delete/merge actions with value types and depth. Values and RFC 7396 application semantics remain inert; arrays and scalar roots are summarized as replacement values.
- CloudEvents JSON: a bounded JSON walk accepts one event object or a batch array, validates the four required 1.0 string attributes, and emits type/id/source-host/time/subject/data-size rows. Source query values are masked; payloads, dataschema and extension values are omitted, with no URI resolution, broker handling or network access.
- FHIR JSON: a bounded JSON walk validates a `resourceType` root, treats `Bundle.entry[].resource` objects as a bounded resource inventory, and emits resource type/id/status/profile and structural counts. Narrative, clinical values, identifiers, coded displays, extension values and references are omitted, with no terminology, URL or clinical-operation resolution.
- Avro JSON: a bounded schema walk accepts record/protocol/union roots, emits field paths and type shapes for named, collection and primitive schemas, and summarizes protocol messages. Defaults, documentation, aliases, logical values, imports, field data and RPC/code-generation behavior remain inert.
- OTLP JSON: a bounded signal walk accepts protobuf-JSON `resourceSpans`, `resourceMetrics`, `resourceLogs` and `resourceProfiles` arrays, then emits resource/scope counts and service names. Attribute values, bodies, IDs, exemplars, links and endpoints remain inert; telemetry is never exported or interpreted.
- OCEL 2.0 JSON: a bounded object-centric log walk validates the `eventTypes`, `events`, `objectTypes` and `objects` collections, counts typed attributes and event/object relationships, and emits inert event/object rows. Attribute values and qualifiers stay omitted; process discovery and external resolution never run.
- JSON:API: a bounded document walk validates primary `data` and optional `included` resource objects, counts attribute and relationship members, and rejects the mutually exclusive `data`/`errors` combination. Link URLs, attribute values, meta/error payloads and API operations remain inert.
- GraphML: a bounded quick-xml reader validates the GraphML root, node/edge IDs, `edgedefault`, labels, and basic yFiles shape hints before passing a `DiagramGraph` to the shared layered renderer. DTDs and external resources are rejected; compound nodes, hyperedges, custom keys, and source coordinates are not reconstructed.
- XGMML: a bounded quick-xml reader validates Cytoscape graph/node/edge IDs and labels, reads the graph `directed` flag, and records `att`/graphics presence as explicit warnings before using the shared layered renderer. Attribute columns, coordinates, nested subgraphs, and external resources remain inert.
- Graph Modeling Language: a bounded bracket tokenizer parses `graph [ ... ]` containers, comments, quoted labels, node/edge records, and the optional `directed` flag. The `.gml` route is selected only for the text grammar, so geographic GML XML remains on its map converter; unknown attributes and graphics coordinates are reported but not interpreted.
- ESRI ASCII Grid: the reader streams bounded row-major cell tokens twice (range scan, then PNG encode), caps input/line/dimension/cell/encoded-image sizes, and emits a continuous PNG-backed raster with transparent NoData cells and a legend. CRS reprojection and thematic color-table breaks are not applied.
- E57: the reader bounds physical input, E57 1.0 header/offsets, XML bytes/events/nodes/depth, cloud count, attributes, decoded points and rendered points. CRC-protected pages are checked as XML and point vectors are read. Each cloud's pose is applied and spherical points are converted to Cartesian coordinates; scan images, CRS reprojection and non-coordinate attributes are omitted.
- NetCDF CDF-1/CDF-2: the big-endian classic parser validates dimensions, attribute lists, variable types, offsets, vsize padding, fixed arrays, and interleaved unlimited-record slabs before emitting variable/value tables. CDF-5 and NetCDF-4/HDF5 are rejected rather than misread; fill values are labelled and no scientific transforms are applied.
- XYZ ASCII: a bounded header parser maps common X/Y/Z, intensity, RGB and normal aliases; otherwise homogeneous row field counts select the supported profile. Unknown header columns are skipped, malformed partial color/normal groups are rejected, and quoted CSV fields are unsupported. The reader caps total file bytes, line bytes, line/point count, numeric fields and generated PLY bytes; coordinates are used as stored because the format supplies no guaranteed unit, CRS or pose metadata.
- PPTXのchart/table/SmartArt/OLE補助parserは、namespace prefixに依存しないbyte-level local-element preflightを先に行い、該当要素がない大多数のslideではXML parserを起動しません。
- PDF: `lopdf`がPDFオブジェクト表を保持しますが、ページcontentの展開はページ単位かつ同じ上限で行います。
- 埋め込みfont program: `Arc<[u8]>`でpage/Form/soft-maskのdecoder scope間に共有し、font bytesを複製しません。
- Page IR: `jobs=1`ではrender直後にSVGへconsumeして破棄します。並列PDFも入力順を保つ`jobs`件単位batchだけを保持し、文書全ページのIRは保持しません。
- 出力: `BufWriter`へ直接書き、巨大なSVG文字列を二重保持しません。
- drawio: 図面本文の展開は`max_zip_entry_bytes`で制限します。shape libraryは1ファイル64 MiB、1 shape 200,000命令を上限とし、そのページが実際に使うshapeだけをXMLから抽出して保持します。必要なshapeが全て揃った時点で残りのlibrary fileは読みません（AWS図1枚＋42 MBの全library指定で常駐15 MiB以下）。座標と長さは原点から±1,000,000 pxに収め、ページもその範囲でcropします。
- SVG逆変換: SVG合計を`max_input_bytes`、ページ数を`max_pages`で制限し、OOXMLを一時ZIPへ書いてからrenameします。
- 並列化: `jobs=1`が省メモリ既定です。PDFだけ指定worker数でページを並列化し、同時常駐Page IR上限も`jobs`件です。速度と常駐IR数は明示的なトレードオフです。

`conversion.json`の`largest_page_ir_bytes`は、ページIRをJSON化したときのサイズを用いる比較可能な近似値です。OS RSSの最大値ではありません。

## 安全性

- drawioのstencilは呼び出し元が指定したファイル／ディレクトリだけを読み、図面やstencilの中身からパスを組み立てることはありません。埋め込みSVG画像はSVG逆変換と同じ検査（script、foreignObject、外部参照、ENTITY宣言の拒否）を通してからでなければ出力に入れません。URL参照の画像は取得しません。
- コアとPythonバインディングは`unsafe_code = "forbid"`、Node.jsバインディングはnapi-rsマクロが生成するFFI glueだけを許可する`unsafe_code = "deny"`です。手書きプロジェクトコードに`unsafe`はありません。
- ユーザーパスワードを要求するPDFは処理しません。ユーザーパスワードが空の暗号化PDFは読み込み時に復号され、通常どおり変換します。lopdfはオブジェクト単位の復号失敗を握りつぶすため、内容を消費しながら1 nodeも描かなかったページは警告として報告します。
- ZIP entry展開量、PDF content展開量、XMLイベント、ページ、描画セルに上限があります。
- PDF画像は宣言dimensionの`width × height × 4`を展開上限と照合してからbufferを確保し、圧縮されたdimension bombを拒否します。
- JPEG soft maskはJPEG metadataのdimension/pixel formatを先に検査し、既存entry上限内でgrayscale alphaへdecodeします。external CCITTはinline画像と共通のbounded hayro decoderを使用します。
- 外部relationshipの画像は取得しません。
- PPTXのvideo/audio本体とOLE payloadは実行・decodeせず、既存poster/previewだけを静的SVGへ保持します。preview欠落時は軽量placeholderと警告を出します。
- 一時出力からのatomic renameで、壊れた完成ページを残しません。
- SVG逆変換は既存OOXMLを上書きせず、active content・外部参照を拒否し、SVG本体とbounded PNG fallbackを同時に格納します。元文書の意味構造を復元したと誤認しないよう常にfidelity警告を返します。
- 未対応PDF演算子、ブレンド、soft mask、shadingなどは`warnings`へ残します。
- knockoutや複雑なpaint serverなど、SVGとPDFの合成モデルが異なる場合は同値性を証明できる条件だけ警告を外します。non-isolated groupはSVGの非isolated group、noncontained radialはbounded field tessellationで表現します。
- mesh shadingはshadingごと最大3,000 micro-triangleへ適応分割し、pattern、soft mask、Type3等のnested interpreterも共有するpage全体50,000 triangle budgetを適用します。`Decode`が座標4値＋1 component pairだけなら、そのrangeを不足color componentへ反復します。component pair自体が欠落・奇数の場合は従来どおり警告してskipします。
- inline imageのBI/IDはPDF literal string、hex string、commentを読み飛ばすsyntax-aware scanで検出し、画像data内のEIだけはdecode検証付きdelimiter scanを使います。
- XLSXの過大な使用範囲は、空セルを無制限に描かず明示エラーにします。
- XLSX formula fallbackは式長1MiB、依存深さ64、演算100,000、range 100,000セルを上限にします。条件集計rangeは数値・文字列・空白の位置対応を維持し、失敗時は警告してcached値契約へ戻します。
- cross-sheet／defined-name式は、未cached式に`!`または実際のdefinedNameが現れるsheetだけresolverを起動します。外部sheet全体を保持せず、必要座標をgroup化してZIP partから選択抽出します。conditional expressionはruleごとに一度評価し、全cell/tileで結果を共有します。
- XLSXのdirect string/inline text/formula captureは所有権をCellへmoveし、capture buffer・raw value・display valueの重複保持を避けます。raw valueは数値・booleanなど評価に必要な型だけ保持します。

### drawioモジュールの構成

`src/drawio/`は仕事ごとに分かれています。`mod.rs`が`mxfile`の展開・モデル解析・Scene（親子座標）・
ページ組み立てを持ち、`geometry.rs`が矩形とpath文字列と変換、`shapes.rs`がshape名の解決と幾何、
`edge.rs`が経路・矢尻・エッジラベル、`label.rs`がHTMLラベルと折り返し、`bpmn.rs`がBPMNの3層、
`stencil.rs`がshape libraryの読み込みと解釈を担当します。

### drawioのshape解決

1. `shape=stencil(...)`（図面が自前で持つmxStencil）
2. 呼び出し元が渡したstencil library（`stencil_paths`／`--stencils`）の完全一致
3. 本modのnative shape（基本図形、フローチャート、BPMN、UML、floorplan、AWS 3Dの箱など）
4. label付きplaceholder矩形＋shape名を含む警告

2が3より優先します。libraryはエディタが実際に描く定義そのものなので、同名のnative近似より忠実だからです。mxStencilは`path`（move/line/quad/curve/arc/close）、`rect`／`roundrect`／`ellipse`、`fill`／`stroke`／`fillstroke`、`save`／`restore`、色・線幅・破線・alpha・cap/join/miterを解釈し、`aspect="fixed"`は等倍センタリング、`strokewidth="inherit"`はcell側の線幅を継承します。ベンダーアイコンは同梱せず、利用者が用意したファイルだけを読み、ネットワークは使いません。

drawioがJavaScriptで実装するshapeは、幾何が確定しているものをnative実装として移植しています（BPMNのoutline/background/symbol、floorplanのwall系、UMLのcomponent/folder、AWS 3Dの箱と地上コネクタなど）。AWS 3Dのサービス図形は箱と陰影だけを描き、上に載るグリフが無いことを専用の警告で明示します。

## 精度方針

1. 画像化より、編集可能なSVG primitiveを優先します。
2. 意味を黙って失うより、警告または明示エラーを優先します。
3. PDF文字はToUnicodeとフォント幅を使い、文字列と配置の両方を維持します。
4. Office入力はテーマ、style、relationshipを解決し、名前空間prefixには依存しません。
5. SVGへ`data-source-id`、`data-content-kind`、`data-semantic-role`を付与します。

Visio VSDXはOPC packageとして読み、internal relationshipからdocument、ページ順、各page XMLを解決します。旧VDXは単一XML内のPageを順に抽出し、同じShapeSheet rendererへ渡します。ShapeSheetのlocal Cartesian座標はshapeのLocPinを引き、FlipX/FlipY、反時計回り回転、Pin位置の順に変換し、pageからSVGへ渡す境界でY軸を一度だけ反転します。1次元shapeの端点、直接のMoveTo/LineTo geometry、基本的な名前付きfallback形状、直接style、textに対応します。master継承、nested group、connector曲線routing、foreign dataは明示的に省略し、external relationshipを取得したりmacroを実行したりしません。

`.eml`はRFC 5322/MIME parserでboundedに読み、headerとdecoded text bodyを共有HTML typesetterへ渡します。HTML alternativeもテキストとして扱い、attachment/inline imageは省略します。HTML bodyをブラウザとして実行したり、外部画像・linkを取得したりしません。

`.mbox`はRFC 4155のfull `From_` separatorを検査してメッセージ範囲を分割し、各messageを同じMIME text rendererへstreamします。separator判定を限定して曖昧な本文行を境界と誤認しにくくし、メール件数・行数・入力byteで制限します。

`.mht`/`.mhtml`はRFC 2557 MIME containerからHTML bodyを取り出し、既存HTML parserへ渡します。Content-IDで参照されたPNG/JPEGだけをサイズ・pixel上限内で埋め込み、Content-Location/remote resourceは取得しません。safe HTML subsetにないscript/styleは省略します。

`.ics`はRFC 5545 content lineをbyte単位でunfoldしてからUTF-8として読むので、foldがmultibyte character内部に入った記録も復元できます。VEVENT/VTODOなどを独立ページへ変換し、recurrenceやVTIMEZONEは勝手に評価せず、元のルール・TZIDを表示して警告します。

`.vcs`はVCALENDAR VERSION 1.0のVEVENT/VTODOを同じbounded calendar parser/typesetterへ渡します。互換性を明示するため、ページは`vcalendar` source formatとし、未対応alarm/propertyをwarningで知らせます。

`.vcf`はRFC 6350 vCard 4.0とRFC 2426 vCard 3.0のUTF-8 content lineをunfoldし、escape済みtextと複数contactを共通typesetterへ渡します。写真や鍵などのmediaは展開せず、URLなどの外部resourceも取得しません。

`.msg`はCFBをbounded readerで開いてOutlookの代表的なMAPI root property streamだけを読み、attachment storageやbinary payloadは展開しません。Subject、送受信者、HTML/plain-text bodyを共通typesetterへ渡し、`PidTagInternetCodepage`/`PidTagMessageCodepage`に従ってANSI形式をdecodeします。HTMLはsafe subsetで処理し、script/styleは省略、画像・linkは取得しません。

`.ppt`は`CurrentUserAtom`から最新`UserEditAtom`を読み、過去のedit chainをたどってpersist directoryを古い順に合成します。最新の`DocumentContainer`とpresentation slide listの順序からlive `SlideContainer`だけを解決し、OfficeArt `ClientTextbox`の直接文字とoutline referenceをA4 text flowへ渡します。PPTXの図形レンダラーとは独立したtext-only fallbackで、画像、master/layout、geometry、style、animationや埋め込みpayloadは描画しません。暗号化tokenとencrypt-session referenceを拒否し、外部resourceやmacroは開きません。

## 拡張ポイント

- 新しい入力形式は`PageConsumer`へページを渡すconverterとして追加します。
- SVG以外の出力は共通IRから別writerを実装できます。
- PPTXとXLSXのchartは共通`ChartData` parser／rendererを利用し、Office cached seriesをbar・line・pie・doughnut・area・XY scatter previewへ変換します。cacheの`pt idx`を保持して欠損値の位置を保ち、scatterは数値x/yを軸上へ配置、負値はzero axisをまたいで表示します。areaはbaselineまたはstacked regionを塗り、doughnutのhole sizeと、存在するseries/category legendをbounded SVG nodesで描画します。bubble、他の未知chart type、複合chartはplaceholderを出し、Office chart style/axis/data labelの再現は対象外です。
- PPTX native tableはgraphicFrameのgridをpoint座標へscaleし、cell pathとclip付きtextへ正規化します。gridSpan/rowSpan continuationは重複描画せず、空白区切りwordを保つscript-aware wrapをshape textと共有します。
- Table row/column metricが0でもgraphicFrame extentが有効なら、全zeroは均等配分、部分zeroは正metric平均へ置換してからframe寸法へscaleします。frameとgrid双方が無効な場合だけreview警告を残します。
- DrawingML custom geometryはguide式からpathへ正規化します。未対応preset／guide演算とWord互換組版は既存IRを拡張して追加できます。
- DrawingML preset adjustmentは`prstGeom/avLst/gd`から取得します。wedgeRectCalloutはECMA presetのdx/dy、side-selection、16点path式を評価し、tipがshape bbox外でも座標を保持します。shape direct paintと`style/fillRef/lnRef`のcolor transformは混在させません。
- 高頻度presetはbounding boxへ落とさずnative pathを生成します。right/left braceはadj1のshoulderとadj2のcenter、arcは60000分の1度のstart/end angle、bentConnector2/3はbounded bend guide、canはadjによる楕円高を評価します。manual-input/extract/decision flowchartは回転・group affine適用前のlocal geometryとして正規化します。
- 第2 preset群はmoonのinner arc、cubeのdepth、snip/cornerのarm、waveのamplitudeをadjustmentから評価します。donutは向きが逆のinner subpathでnonzero holeを保持し、left/right/bracketPairはopen path、bent/uturn/curved/left-right arrow、delay/connector/collate/process flowchart、homePlate、action button、mathPlusもnative compound pathへ正規化します。
- 残るwedgeRoundRect/wedgeEllipse/border callout、curved up/down/circular/up-down arrow、irregular sealもnative path化します。round calloutはtip方向に応じた辺へwedgeを挿入し、adj3 radiusをbounded評価します。
- DrawingML direct `outerShdw`と`glow`はshape/picture/text/table textのSourceMetaへ保持し、SVG writerがSourceAlpha blur、offset、flood、composite、SourceGraphic mergeからなるfilterを生成します。両effectがあるnodeはshadow、glow、元graphicを1 filterで順序合成します。blur/glow radiusは512pt、shadow distanceは4,096ptで上限化し、filter regionもpage寸法から有限化します。互換保存用`a14:hiddenEffects`はfilter化しません。
- PPTX themeはpresentation既定だけに固定せず、各slideのlayout→master relationshipからtheme partを解決し、part名ごとに一度だけstream parseしてcacheします。`effectRef`はidx 0を無effect、idx 1以上を`effectStyleLst`の1-based参照として解決します。shape-local `effectLst`が存在する場合は、empty listも含めてtheme effectを上書きします。
- Placeholder geometryはidx完全一致を優先し、title/ctrTitle/subTitle/footer/date/slide-numberだけtype aliasへfallbackします。layout/masterにもgeometryがない可視footer/date/slide-numberはpage下端の有限既定boxへ配置します。zero-sizeかつ空paragraphのhiddenFill/hiddenLine互換artifactは可視nodeも警告も生成せず、可視textを持つ未知body placeholderだけreview警告を維持します。
- PPTX `srcRect`はsource画像をdecode/crop/re-encodeせず、残存source比率からimageのx/y/width/heightを逆算し、元frame geometryを回転・group affine付きclipとして適用します。負cropは画像外を透明marginとして保持します。crop値は±1,000%、可視幅・高さは0.01%以上、生成座標は絶対値1e9以下に制限し、不正時は警告付きfull-imageへ戻します。cropとshadow/glowが併存する場合はclip済みimageをgroup化してからeffectを適用します。
- DrawingML `pattFill`はbitmap化せず、前景/背景color transformとalphaを解決して`TilingPatternDefinition`へ正規化します。density、horizontal/vertical hatch、up/down diagonal、open diamondを1.5〜12ptの有限tileと2〜3個のeditable pathだけで表し、shape回転とgroup affineは参照path側で保持します。未知presetは警告して背景色へ戻します。
- PPTX image color effectは入力画像をdecode/re-encodeせず、XML順の`ImageColorEffect`列としてSourceMetaへ保持します。duotoneはluminance matrix＋channel linear map、grayscaleはsRGB luminance matrix、brightness/contrastはbounded component transfer、`clrChange`はdifference・1/255 exact-match mask・replacement mergeへ変換します。cropがある場合はclip済みsourceをgroup化して色効果を適用し、その結果alphaからshadow/glowを生成します。
- XLSXのprint area/manual break/print titleはbodyと反復titleを局所座標groupへ分け、不要な中間セルを複製せず1 sheetから複数Page IRを生成します。
- 明示print area/pageSetupがない巨大XLSXは16,384pt／2,000 grid-cellを上限にauto tileします。row/column prefix座標はsheetごとに一度だけ構築して全tileで共有し、各Page IRはconsume後に破棄します。
- XLSX Drawingはcell markerの位置・寸法とshape-local `a:xfrm`を別々に保持します。from/toが逆転または同一点ならlocal off/extへfallbackし、auto-fit text boxの0寸法はfont/run内容からbounded自然寸法を算出します。hidden互換shapeは描画前に除外します。
- DOCXのsection rangeは用紙設定とheader/footer relationship setを保持し、first/even/default storyをpage生成時に選びます。段落途中のpage breakはrun markerで分割し、break後のfieldを新page番号でmaterializeします。
- DOCX styleはdocDefaultsから最大32段の`basedOn` chainを基底順にmergeし、paragraph direct property、run direct propertyで上書きします。run fontはascii/hAnsiをLatin先頭family、eastAsiaをfallback familyとして保持します。
- DOCX/PPTXのword-aware wrapは空白区切りtokenを行末で分断せず、token自体がavailable widthを超える場合だけscript-aware文字幅で分割します。
- DOCX OMMLはdocument streamを追加DOM化せず、fraction numerator/denominatorへ`(num)/(den)` marker、radicalへ`√(expr)` marker、sub/supへbaseline-shift runを挿入します。matrix、n-ary、limit等の未知構造だけreview警告を残します。
- CAD (DXF): 外部GPL/Cライブラリを一切使わず、Pure Rustかつ安全なストリーミングASCII DXFパーサーを自作実装しています。Windows-1252/ANSIフォールバック付きデコードにより、実世界の角度記号（°）や欧州特殊文字を含む図面も安全にパースします。AutoCAD Color Index (ACI 1〜255) および TrueColor、レイヤー（非表示/フリーズ）、線種（LTYPE: 点線/破線）、ブロック定義と再帰参照（INSERT: 深度上限16）、軽量ポリライン（LWPOLYLINE: バルジ円弧計算）、円弧・楕円・スプライン・文字（TEXT/MTEXT: 制御文字整形）に対応し、図面のバウンディングボックスから用紙へのアスペクト比維持フィットスケーリングとY軸反転正規化を行ってPage IRへマッピングします。
- CAD (Gerber RS-274X): プリント基板（PCB）製造CAMデータに対応。アパーチャ定義（円形、矩形、長円/楕円、多角形）、フラッシュ（D03）、補間（D01/D02）、およびG36/G37ポリゴン輪郭塗りつぶしをパースし、基板外形と銅箔配線（Copper Layer）のPage IRへ変換します。
- CAD (HP-GL / HP-GL/2): プロッター言語に対応。ペン選択（SP）、絶対/相対座標プロット（PA, PR, PD, PU）、円弧（AA）、円（CI）、ペン幅設定（PW）を8色ペンパレットでベクター描画します。
- CAD逆変換（SVG -> DXF）: SVGのベクター図形（`<path>`, `<line>`, `<circle>`, `<rect>`）およびテキスト・レイヤーグループ構造から、AutoCAD Release 12（AC1009）標準のASCII DXFエンティティ（LINE, CIRCLE, ARC, TEXT）を再構築します。
- CADのメモリ・セキュリティ設計: DXFパースは最大行数（5,000,000行）、最大エンティティ数（500,000件）、ポリライン頂点数（100,000頂点）の安全上限を設け、ブロック展開の循環参照はスタック深度（最大16）で防御します。外部ライブラリ依存ゼロ（`unsafe_code = "forbid"`）を維持し、GPL/LGPLなどのコピーレフト感染を完全に排除しています。

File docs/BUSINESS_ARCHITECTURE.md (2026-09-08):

# 業務向けアーキテクチャ図

公式アイコンと、参照資料に基づく構成例を使い、提案・設計レビュー・説明資料へ配置できる
SVGを生成します。変換コアとは独立した `authoring/architecture.py` が描画と幾何検証を担い、
従来の `authoring/cloud_icons.py` から呼び出せます。AIがサービス構成と配置をJSONで作り、
レンダラーが接続を直角に配線します。サービスの自動選定やクラウド構築は行いません。

## すぐ使う

リポジトリルートで実行します。Python 3.10以降、既存のアイコンカタログが必要です。

```bash
# カタログがない場合のみ取得
python3 authoring/cloud_icons.py fetch

# 3社のSVG・2400px PNG・JSON・検証結果・確認画面をまとめて作成
python3 authoring/cloud_icons.py build-examples --output output/business-architecture

# テンプレートを選んで変更する
python3 authoring/cloud_icons.py templates
python3 authoring/cloud_icons.py template azure-private-web --output output/my-architecture.json

# JSON編集後に検証し、SVGとレポートを生成
python3 authoring/cloud_icons.py validate output/my-architecture.json
python3 authoring/cloud_icons.py render output/my-architecture.json \
  --output output/my-architecture.svg --report output/my-architecture.report.json
```

`build-examples` のPNG生成には `rsvg-convert` を利用します。`--png-width 3200` などで
1200〜4800pxの出力幅を選べます。SVGのみの `render` は外部描画CLIを要求しません。
既存の出力ファイル・bundleディレクトリは上書きしません。

生成する `index.html` はローカルで開けます。Azure / AWS / Google Cloudのタブと
「直角（標準） / 小さな角丸」の切り替えがあり、選択した図柄に対応するSVG・PNG・JSON・
レポートをダウンロードできます。図と必要な素材は自己完結し、外部サービスへ構成内容を送信しません。

## 参照資料とテンプレート

確認日: 2026-09-06。配布元の図の構成・境界・通信の考え方を参照し、独自のレイアウトで
再構成しています。参照図の画像を完成物へ貼り付ける方式ではありません。

| テンプレート | 内容 | 参照した公式資料 |
|---|---|---|
| `azure-private-web` | WAF付きApplication Gateway → Private Endpoint → App Service。送信はVNet統合経由でSQL・Key Vaultへ | [App Service baseline](https://learn.microsoft.com/en-us/azure/architecture/web-apps/app-service/architectures/baseline-zone-redundant) |
| `aws-multi-az-web` | CloudFront・WAF、2AZの単一ALB・EC2、RDS primary / standby、DNSと監視 | [Web application architecture](https://d1.awsstatic.com/architecture-diagrams/ArchitectureDiagrams/web-application-architecture-on-aws-ra.pdf)、[VPC private subnets](https://docs.aws.amazon.com/vpc/latest/userguide/vpc-example-private-subnets-nat.html)、[RDS Multi-AZ](https://docs.aws.amazon.com/AmazonRDS/latest/UserGuide/Concepts.MultiAZSingleStandby.html) |
| `gcp-serverless-web` | Global HTTPS LB・Cloud Armor → Serverless NEG → Cloud Run、Direct VPC egress → private IPのCloud SQL HA | [Global serverless LB](https://docs.cloud.google.com/load-balancing/docs/https/setup-global-ext-https-serverless)、[Cloud Run → Cloud SQL](https://docs.cloud.google.com/sql/docs/postgres/connect-run)、[Cloud SQL HA](https://docs.cloud.google.com/sql/docs/postgres/high-availability)、[Cloud Run ingress](https://docs.cloud.google.com/run/docs/securing/ingress) |

AzureのApp Serviceをサブネット内のVMとして描かず、Private Endpointと送信のVNet統合を
別々に表します。AWSの2つのALB endpointは**同じALBのAZ別配置**です。DB standbyには
通常の読取通信を送りません。GCPはグローバルVPCとリージョン内サブネットを区別し、Cloud Runの
実行環境とVPC送信接続を分けます。Cloud SQLはサービス側ネットワークに置いています。

Azure例はベースラインを簡略化し、DNS・NSG等の一部を説明欄へ移しています。AWS例では
NAT等の送信経路を省略しています。いずれも図内に省略範囲と設定時の確認事項を記載しています。
使用するSKU、リージョン対応、可用性、バックアップ、IAM、認証、経路、容量は実案件でレビューします。

GCPのLB・NEG・Cloud Armor・監視には、現行の公式**カテゴリ共通アイコン**を使用します。
製品名を明記し、レポートにもカテゴリ確認の警告を残します。これらを製品固有アイコンと主張しません。

## 図の構造: schema_version 2

`authoring/templates/*.json` が完全な編集例です。既存のv1形式と互換に共存します。

| 要素 | 主なフィールドと制約 |
|---|---|
| document | `schema_version: 2`、`provider: azure / aws / gcp / neutral`、`title`、`groups`、`nodes`、`edges` は必須。`subtitle`、`revision`、`notes`、`sources`、`edge_style` は任意 |
| canvas | `width` 1200〜3200、`height` 800〜2400。既定1760×1120。上部タイトル、右側説明欄、下部凡例の領域を予約 |
| group | `id`, `label`, `kind`, `x`, `y`, `width`, `height`。任意の `parent` で入れ子。最大40件 |
| group kind | `cloud / region / vpc / subnet / zone / service / logical`。色・実線/破線・背景で境界を区別 |
| node | `id`, `label`, `x`, `y`。公式 `icon` か汎用 `symbol` のいずれか。`group`, `detail`, `badge`, `width`, `height` は任意。最大64件 |
| node size | 既定208×112。幅160〜360、高さ100〜190。ラベルは最大3行、detailは1行。配置間隔は16px以上 |
| symbol | `user / external / interface`。利用者や一般的な接続点であり、クラウド製品アイコンの代用品ではない |
| edge | `from`, `to`, `kind` 必須。`id`, `label`, `from_port`, `to_port`, `from_offset`, `to_offset`, `via` 任意。最大96件 |
| port | `n / e / s / w`。offsetは辺中央からの比率 −0.35〜0.35。辺に対して垂直に出入りする |
| via | 必要な場合だけ `[[x,y], ...]` を指定。最大12点。障害物上や180度の折り返しはエラー |
| notes | `title`, `body` の配列。最大5件。説明欄に収まらない文章はエラー |
| sources | `title`, `url` の配列。最大5件、URLはHTTPS。SVG metadataとレポートに保持し、確認画面から参照可能 |

groupの座標もnodeの座標も、**ページ全体の絶対座標**です。親を指定しても座標を加算しません。
描画領域は `x=40..(canvas.width−370)`、`y=160..(canvas.height−150)`。
親group内では左右12px、上42px、下12pxを予約します。nodeを親内に収め、関係のないgroupへ
重ねないでください。サービス配置を自動計算する機能ではないため、既存テンプレートを編集すると扱いやすくなります。

### 通信種別

| kind | 表示 | 意味 |
|---|---|---|
| `request` | 青・実線 | 利用者リクエストやサービス呼出し |
| `private` | 青緑・実線 | プライベート接続 |
| `replication` | 紫・破線 | 複製・同期 |
| `telemetry` | 灰・点線 | 監視・ログ |
| `control` | 黄土・破線 | DNS、ポリシー、設定など |

色だけに依存せず、線種・矢印・ラベル・凡例で意味を示します。描画上の線の種類は実際の
プロトコルを保証するものではなく、JSON作成者が参照資料に基づいて指定します。
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

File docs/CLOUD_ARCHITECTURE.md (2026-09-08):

# 公式クラウドアイコンによる構成図作成

`authoring/cloud_icons.py` は、生成AIが公式アイコンを検索・参照してSVG構成図を作るための
独立ツールです。Python 3.10以降の標準ライブラリだけで動作し、Rustの変換コア、各parser、
Node/Python bindingには依存しません。生成AIへのAPI呼び出しは実装しておらず、Codex等の
呼び出し元が図の構造をJSONとして作成します。現在はリポジトリのcheckoutから利用します。

業務向けの構成図には **[業務向けアーキテクチャ図ガイド](BUSINESS_ARCHITECTURE.md)** の
`schema_version: 2` と3社のテンプレートを使ってください。入れ子の境界、障害物を避ける
直角配線、通信種別、角丸切り替え、説明欄、出典、幾何検証を追加しています。
以下の `schema_version: 1` は引き続き簡易グリッド図として利用できます。

## 取得済みの素材

2026-09-05に公式配布ページから取得・確認しました。
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

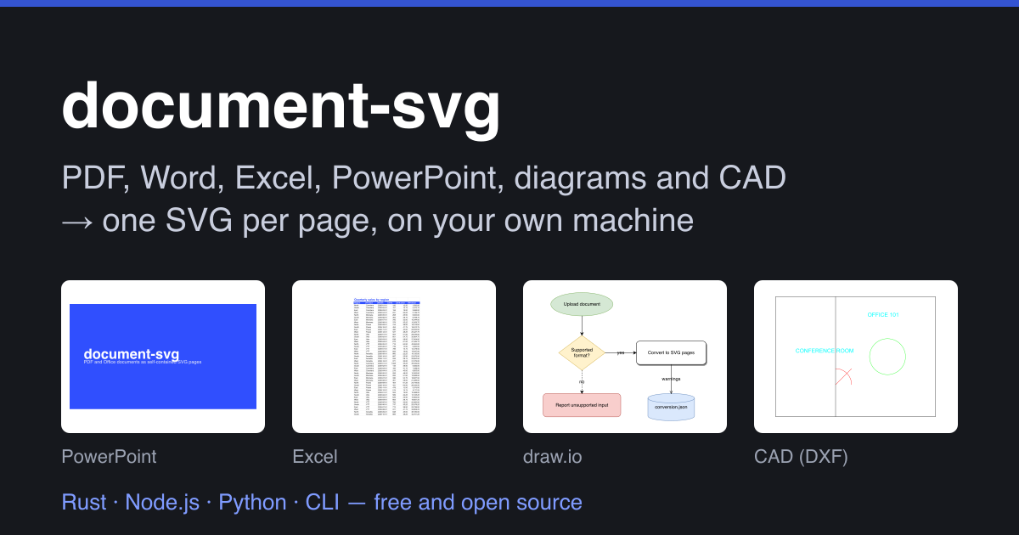
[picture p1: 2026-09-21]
site/assets/og.png

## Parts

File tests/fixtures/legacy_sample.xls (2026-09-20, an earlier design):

Name | Amount
Alpha | 12.5
Beta | 42
Gamma | 99.75

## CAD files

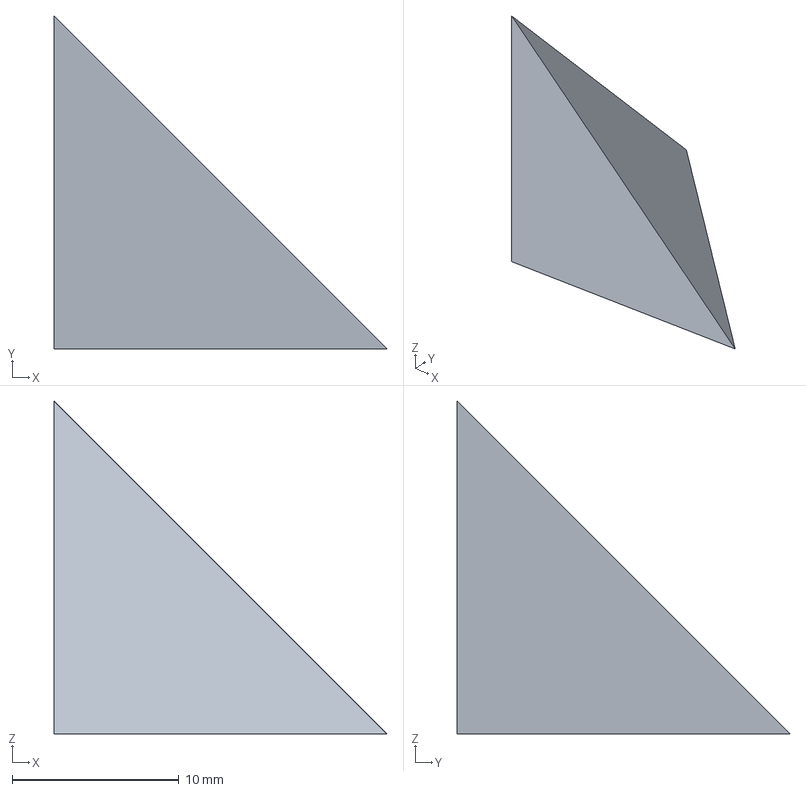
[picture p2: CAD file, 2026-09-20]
tests/fixtures/sample.amf
20.0 x 20.0 x 20.0 mm

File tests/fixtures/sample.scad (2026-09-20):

// Safe OpenSCAD structure fixture
$fn = 32;
module rounded_box(size=[20,10,5]) {
  difference() {
    cube(size, center=true);
    translate([0,0,2]) sphere(r=3);
  }
}
function safe_radius(value) = value / 2;
use <private-library.scad>;
include <private-config.scad>;
import("private-model.stl");
translate([0,0,5]) rotate([0,0,15]) rounded_box();

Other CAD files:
samples/source/sample.step
tests/fixtures/sample_r12_ocs.dwg
tests/fixtures/sample_r12_attr_dim.dwg
tests/fixtures/sample_r12_insert.dwg
tests/fixtures/sample_r12.dwg
tests/fixtures/sample_r12_ltype_text_mesh.dwg
tests/fixtures/sample_r12_shape_viewport.dwg
tests/fixtures/binary_line.dxf
samples/source/sample.dxf
samples/source/sample.obj
samples/source/sample.ply
samples/source/sample.stl
tests/fixtures/sample.3dm
tests/fixtures/sample.dwg

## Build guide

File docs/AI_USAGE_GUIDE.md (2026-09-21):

# SVG変換・モジュール利用ガイド

この文書は、人間と生成AIのどちらでも「どのAPIを選び、何を入力し、何が出力され、
結果をどう判定するか」を迷わず実装できるように、`document-svg`の利用契約を明示した
ものです。

## 30秒で分かる変換の仕組み

```text
入力ファイル
  ├─ .pdf  ── PDF parser
  ├─ .pptx ─┐
  ├─ .xlsx ─┼─ OOXML ZIP/XML parser
  └─ .docx ─┘
          ↓
共通 Page IR（Path / Text / Image / Group）
          ↓
SVG writer
          ↓
page-0001.svg、page-0002.svg、...、conversion.json

SVGファイルまたはSVGディレクトリ
          ↓
SVG image partとしてOOXMLへ格納 ／ mxfileへ格納
          ↓
PPTX（1 slide/ SVG）、legacy PowerPoint Binary `.ppt`（text-only A4 preview）、DOCX（1 page/SVG）、XLSX（1 sheet/SVG）、
drawio（1 diagram/SVG。sourceを持つSVGは元の図面を復元）
```

重要な事実は次のとおりです。

- 変換元の形式は通常はファイル拡張子で判定し、拡張子なし/汎用形式は内容も検査します。PDF・Office Open XML Transitional/Strict・Microsoft Project XML Gantt schedule・OpenDocument・HTML・
  EPUB・FictionBook 2 FB2/FB2.ZIP・CBZ・EML/Apple Mail EMLX/Outlook MSG email・MBOX archive・MHTML archive・DICOM/DICOMDIR medical images (including JPEG 2000 Part 1 compression)・iCalendar ICS/vCalendar VCS・vCard contact files・XPS/OpenXPS・Visio VSDX/VSDM/VSTX/VSTM/VDX・multi-page TIFF・SubRip/WebVTT/TTML subtitles・XLIFF localization catalogs・Jupyter notebook・Quarto/R Markdown・Markdown・AsciiDoc（`imagesdir` 内の検証済み `image::target[attrs]` PNG/JPEG ブロックを含む）・reStructuredText・Org-mode・gettext PO/POT translation catalogs・BibTeX bibliography・draw.io・BPMN 2.0・CMMN 1.1・DMN 1.5・ReqIF・XMI・Mermaid・PlantUML・D2・DOT・Excalidraw・
  Legacy Excel XLS/XLSB・Abaqus INP・LS-DYNA K/KEY・MEDIT MESH/MESHB・OFF・IFC/IFCXML/IFCZIP・Nastran BDF/NAS・SU2 CFD mesh `.su2`・OpenFOAM `.foam`・UNV/UFF・PCL PCD/LAS/LAZ point clouds・DXF・Gerber・HP-GL・G-code・Excellon・STL/OBJ/PLY・STEP・IGES・3MF・EMF/WMF・
  Gmsh MSH・VTK・ASCII XYZ/PCL PCD/Leica PTS/PTX/ASTM E57/LAS/LAZ point clouds・ESRI ASCII Grid・dBASE III/III+ DBF・ARFF dataset（`.arff`）・JSON-LD 1.1（`.jsonld` / `.json-ld`）・NetCDF classic（`.nc` / `.nc3` / `.cdf`）・GraphML（`.graphml`）・GEXF（`.gexf`）・XGMML（`.xgmml`）・Graph Modeling Language（`.gml`）・CSV/TSV・TOML/YAML/Java Properties configuration・generic XML・GeoPackage・TopoJSON・GeoJSON Text Sequences・GeoJSON/GeoRSS/GML/GPX/KML/KMZ/ESRI Shapefile/WKT・CSV・chart JSON・LaTeX（数式と安全な完全文書preview、ローカル`\\includegraphics`を含む）・QR・standalone JPEG 2000（`.jp2` / `.j2k` / `.j2c` / `.jpc` / `.jpx`）・ラスター画像など幅広い拡張子に
  対応しています。全リストと形式ごとの忠実度ティア（A/B/C）は
  [`../site/assets/data/formats.json`](../site/assets/data/formats.json)
  （プロジェクトサイトの「対応形式マップ」の元データ）と、ルートの
  [`FORMATS.md`](FORMATS.md) の対応形式表を参照してください。
- 文書全体を1個のSVGにするのではなく、ページ、スライド、またはシートの出力ページ
  ごとにSVGを1個生成します。
- 通常の利用者は`convert_path`だけを呼びます。PDF/Officeのparserを選ぶ処理は
  `convert_path`が行います。
- `conversion.json`は付属情報ではなく、警告を含む変換結果の一部です。
- SVGの座標と寸法はポイント単位です。ページ左上が原点で、右が+x、下が+yです。

## APIの選び方

Azure・AWS・GCPの公式アイコンを用いる新規アーキテクチャ図は、
[`CLOUD_ARCHITECTURE.md`](CLOUD_ARCHITECTURE.md) の独立した `authoring/cloud_icons.py` を使ってください。
AIがカタログを検索して実在するIDを選び、図のJSONを作り、決定的レンダラーでSVGを生成します。
この経路はPDF/OOXMLの変換parserやRust crateへネットワーク・AI依存を追加しません。
業務資料向けの図では [`BUSINESS_ARCHITECTURE.md`](BUSINESS_ARCHITECTURE.md) を読み、
`templates` → `template` → 編集 → `validate` → `render` の順でv2形式を利用します。

次の規則で選んでください。

1. ファイルをそのまま変換するだけなら、CLIまたは使用言語の高レベル`convert`を使う。
2. Rustアプリから変換するなら、crate rootの`convert_path`を使う。
3. 自作の図形、文字、画像からSVGを組み立てるなら、`ir::Page`を作り、
   `svg::write_page`へ渡す。
4. `pdf`、`ooxml`、`convert`モジュールは内部実装なので、外部crateから直接呼ばない。
5. PDF/PPTXなどを一度`Page`として受け取って独自加工する公開APIは、現時点ではない。
   必要なら内部converterと`PageConsumer`を公開・設計し直す必要がある。
6. SVGをOfficeやdrawioへ戻すだけなら、CLIの`reverse`または`svg_to_document`
   （旧名`svg_to_openxml`も使用可）を使う。この処理は見た目をベクター画像として保持する
   もので、Officeの意味構造を復元しない。
7. drawio出力だけは例外で、図面のsourceを持つSVG（drawioの「Include a copy of my
   diagram」付きexport、または`--embed-drawio-source`で変換した本ツールのSVG）は編集可能な
   図形として復元する。何ページ復元したかはreportのwarningに出るので、推測せずそれを読む。

## CLIで変換する

リポジトリのルートでビルドし、入力ファイルと専用の出力ディレクトリを指定します。

```bash
cargo build --release
target/release/docsvg input.pdf --output output/pdf
```

PDFを4ページずつ並列処理する例です。

```bash
target/release/docsvg input.pdf --output output/pdf --jobs 4
```

`--jobs`によるページ並列化が有効なのはPDFです。Office文書はページ単位で逐次処理
されます。既定の`--jobs 1`は常駐メモリを抑える設定です。

コマンドが成功しても警告があり得るため、後述の`conversion.json`も確認してください。
出力先は変換ごとに空の専用ディレクトリを使うことを推奨します。converterは既存の
無関係なファイルや、以前の変換で生成された余分な`page-*.svg`を削除しません。

SVGからOpen XMLへ戻す例:

```bash
target/release/docsvg reverse output/pdf --output repacked.pptx
```

出力拡張子は`.pptx`、`.docx`、`.xlsx`に対応します。既存出力は上書きしません。
返される警告どおり、段落、セル、数式、グラフ等は復元されません。

## Rustから変換する

`Cargo.toml`からこのリポジトリをpath dependencyとして参照する例です。

```toml
[dependencies]
document-svg = { path = "../document-svg" }
```

通常は既定値から必要な項目だけ変更します。

```rust
use document_svg::{ConvertOptions, Error, convert_path};

fn main() -> Result<(), Error> {
    let options = ConvertOptions {
        jobs: 4,
        max_pages: 500,
        ..ConvertOptions::default()
    };

    let report = convert_path("input.pdf", "output/pdf", &options)?;

    println!("{}ページを変換", report.page_count);
    if !report.warnings.is_empty()
        || report.pages.iter().any(|page| !page.warnings.is_empty())
    {
        eprintln!("警告あり: conversion.jsonと各ページのwarningsを要確認");
    }
    Ok(())
}
```

`convert_path`は出力ディレクトリを必要なら作成し、各SVGと`conversion.json`を
書き込み、同じ内容を`ConversionReport`として返します。エラー時には`Error`を返す
ため、`unwrap()`で無視せず、呼び出し元のエラー処理へ伝播させてください。

### `ConvertOptions`の意味

| フィールド | 既定値 | 意味 |
|---|---:|---|
| `max_input_bytes` | 512 MiB | 入力ファイル全体の最大サイズ |
| `max_zip_entry_bytes` | 128 MiB | ZIP形式の展開済みpart/画像、またはPDFページstreamの上限。ZIP-based document packageのcentral directoryは100,000 entriesまで |
| `max_pages` | 10,000 | 出力できる最大ページ数 |
| `max_xml_events` | 5,000,000 | XML解析イベント数の安全上限 |
| `include_metadata` | `true` | SVG内へ由来情報と警告metadataを含めるか |
| `precision` | 5 | SVG数値の小数精度 |
| `jobs` | 1 | PDFページworker数。0は無効 |
| `outline_embedded_pdf_text` | `false` | PDF埋め込みfontをpath化して見た目を優先。文字編集性を失い、権利確認warningが出る |

これらは品質調整だけでなく、信頼できない入力による過大なメモリ・CPU使用を抑える
安全上限です。生成AIは「変換を成功させるため」という理由だけで無制限に増やしては
いけません。

## Pythonから変換する

wheelを作成してインストールした後、`convert`を呼びます。

```python
from document_svg import convert

report = convert(
    "input.pptx",
    "output/pptx",
    jobs=1,
    max_pages=500,
)

needs_review = bool(report["warnings"]) or any(
    page["warnings"] for page in report["pages"]
)
print(report["page_count"], needs_review)
```

Pythonではレポートのキーとオプション名が`snake_case`です。変換中はGILを解放します。
詳細なビルド方法は[`../bindings/python/README.md`](../bindings/python/README.md)を
参照してください。

## Node.jsから変換する

```javascript
const { convert } = require("document-svg")

async function run() {
  const report = await convert("input.docx", "output/docx", {
    jobs: 1,
    maxPages: 500,
  })

  const needsReview =
    report.warnings.length > 0 ||
    report.pages.some((page) => page.warnings.length > 0)

  console.log(report.pageCount, needsReview)
}

run().catch((error) => {
  console.error(error)
  process.exitCode = 1
})
```

Node.jsではフィールドが`camelCase`です。`convert`は`Promise`を返し、変換はlibuvの
worker上で行われます。ブラウザ用APIではなく、ネイティブNode.js用APIです。

### TypeScriptで画面プレビューする

ファイルを保存する通常の`convert()`とは別に、`preview()`は各ページの完全なSVG文字列を
返します。PDFだけでなく、PPTX、XLSX、DOCX、drawioにも同じAPIを使用できます。

```typescript
import { preview } from "document-svg"

const report = await preview("input.xlsx", {
  maxPages: 100,
  maxSvgBytes: 64 * 1024 * 1024,
  maxTotalSvgBytes: 256 * 1024 * 1024,
})

for (const page of report.pages) {
  console.log(page.number, page.widthPoints, page.heightPoints)
  // page.svgが完全なSVG XML文字列
}
console.log("review required:", report.needsReview)
```

Rust側では専用の一時ディレクトリへ変換してSVGを読み込み、`Promise`の完了前に一時
ファイルを削除します。既定のメモリ上限は1ページ64 MiB、全ページ合計256 MiBです。
`maxSvgBytes`と`maxTotalSvgBytes`でより小さい上限を設定できます。

Reactなどへ渡すときは、browser-safeな`document-svg/preview-ui`を使用できます。この
subpathはネイティブRust bindingを読み込まないため、renderer bundleへ含められます。

```typescript
import {
  copySvgSourceToClipboard,
  copySvgToClipboard,
  createSvgPreviewUrl,
  revokeSvgPreviewUrl,
} from "document-svg/preview-ui"

const svg = report.pages[0].svg
const url = createSvgPreviewUrl(svg)
// JSX: <img src={url} alt="Office document preview" />
// component破棄時: revokeSvgPreviewUrl(url)

// buttonのonClick等から呼ぶ
const copiedMimeType = await copySvgToClipboard(svg)

// 常にXMLソースとしてコピーする場合
await copySvgSourceToClipboard(svg)
```

`copySvgToClipboard()`は`image/svg+xml`のClipboard書き込みにブラウザが明示対応していれば
SVG MIMEとしてコピーし、未対応なら完全なXMLを`text/plain`でコピーします。返り値は
実際にコピーしたMIME typeです。Clipboard APIはsecure contextとユーザー操作を要求する
ため、ページ読み込み時に自動実行せず、必ずコピーボタン等から呼びます。
Blob URLの解放とアクセシブルな結果表示まで含むReact component例は
[`../bindings/node/examples/SvgPreview.tsx`](../bindings/node/examples/SvgPreview.tsx)です。

`preview()`自体が動く場所はNode.js、Electronのmain process、またはサーバーです。
ブラウザUIはIPCまたはHTTP API経由でSVG文字列を受け取ります。現在のAPIはブラウザ内で
直接ネイティブRustを実行するWASM APIではありません。

## Rustモジュールの役割

| モジュール／公開項目 | 公開 | 役割 | 通常利用者が使うか |
|---|:---:|---|:---:|
| crate rootの`convert_path` | はい | 入力判定からSVG・report出力までを一括実行 | はい |
| crate rootの`ConvertOptions` | はい | 安全上限、metadata、精度、並列数の設定 | はい |
| crate rootの`ConversionReport` / `PageReport` | はい | 変換結果と警告の確認 | はい |
| crate rootの`Error` / `Result` | はい | 失敗理由の伝播・分類 | はい |
| `ir` | はい | 出力形式に依存しないページ、図形、文字、画像のモデル | 独自描画時 |
| `svg` | はい | `Page` IRをSVG XMLへ直列化 | 独自描画時 |
| `convert` | いいえ | 形式選択、ページsink、manifest作成 | 直接使わない |
| `pdf` | いいえ | PDFを共通IRへ変換 | 直接使わない |
| `ooxml::pptx/xlsx/docx` | いいえ | Office ZIP/XMLを共通IRへ変換 | 直接使わない |
| `ooxml::package/xml/chart` | いいえ | relationship、XML、chartの内部共通処理 | 直接使わない |

Rustの`mod`が存在することと、外部利用者がそのモジュールを呼べることは別です。
`lib.rs`で`pub mod`または`pub use`されている項目だけが公開APIです。

## `ir`と`svg`で独自SVGを生成する

低レベル利用では、`Page`へ`Node`を描画順に追加し、`write_page`へ渡します。
実行可能な完全例は[`../examples/custom_ir.rs`](../examples/custom_ir.rs)です。

```bash
cargo run --example custom_ir -- output/custom.svg
```

主なIR型は次のとおりです。

- `Page`: 1枚のSVGページ。幅、高さ、node、clip、mask、pattern、警告を保持する。
- `Node::Path`: SVG path相当。図形や線を表す。
- `Node::Text`: 編集可能な文字列と複数の`TextRun`を表す。
- `Node::Image`: 通常はdata URLを`href`に保持する画像を表す。
- `Node::Group`: 複数nodeへ共通の変換、透明度、clipを適用する。
- `Paint`: なし、単色、線形・放射gradient、pattern参照を表す。
- `Stroke`: 線色、太さ、端、結合、dashを表す。
- `SourceMeta`: 元要素ID、意味役割、代替テキストなどの由来情報を表す。
- `ClipPath` / `MaskDefinition` / `TilingPatternDefinition`: SVGの`defs`に相当する。

`Page.nodes`の順序が描画順です。後から追加したnodeほど手前に描かれます。

### 座標変換

`Matrix`はSVGと同じ`[a, b, c, d, e, f]`で、点`(x, y)`を次のように変換します。

```text
x' = a*x + c*y + e
y' = b*x + d*y + f
```

変換なしには`ir::IDENTITY`を使います。複数の行列を合成するときは`ir::compose`、
点だけを変換するときは`ir::transform_point`を使います。

`svg::write_page`は任意の`std::io::Write`へ書けるため、`File`、`BufWriter`、
`Vec<u8>`などを渡せます。大量出力では`BufWriter`を推奨します。

## 出力と成功判定

代表的な出力は次の構成です。

```text
output/pdf/
├── page-0001.svg
├── page-0002.svg
└── conversion.json
```

成功判定を「関数がエラーを返さなかった」だけにしないでください。推奨判定は次です。

```text
関数がErrorを返した             → failed
文書またはページにwarningがある → needs_review
warningがない                   → converted
```

`ConversionReport.warnings`は文書全体、`PageReport.warnings`はページ固有の警告です。
未対応機能を安全に近似・省略した場合があるため、警告ありの結果を「完全再現」とは
扱わないでください。`svg`は出力ディレクトリからの相対ファイル名です。

## 生成AIが実装するときの契約

生成AIへの依頼やagent実装では、次の情報を明示すると安定します。

```text
目的: PDF/Office/CAD/CAM/3D/図表/データなど60以上の形式をページ単位のSVGへ変換する
推奨入口: document_svg::convert_path（言語bindingではconvert）
入力判定: 拡張子
出力: page-NNNN.svg + conversion.json
品質判定: document warningとpage warningの両方を見る
禁止: 内部pdf/ooxml parserの直接呼び出し、警告の黙殺、安全上限の無制限化
運用: 変換ごとに専用の空ディレクトリを使う
```

実装手順は次の順序に固定できます。

1. 入力拡張子が対応形式か確認する。
2. 入力ごとに専用出力ディレクトリを決める。
3. 既定の安全上限を基準に`ConvertOptions`を作る。
4. 高レベル変換APIを1回呼ぶ。
5. エラーなら処理を失敗として返す。
6. 文書警告と全ページ警告を集約する。
7. 警告があれば`needs_review`、なければ`converted`とする。
8. 利用者へSVG一覧と`conversion.json`の場所を返す。

## よくある誤解

- 「PPTXをSVGへ変換」は、通常、スライドごとにSVGを出すという意味です。
- `include_metadata = false`は図形を消す設定ではありません。SVG内の由来metadataを
  省略する設定です。
- `precision`を上げても、入力に存在しない情報や未対応機能は復元できません。
- `jobs`を増やせば必ず速くなるわけではなく、PDF処理のメモリ使用量も増えます。
- `conversion.json`だけを読んでもSVG本体ではありません。逆にSVGだけを見ても警告を
  見落とします。両方を一組として扱ってください。
- このネイティブ配布はブラウザWASMではありません。ブラウザから直接ファイルを
  変換するには、Node.js等のサーバー側APIを用意する必要があります。

内部設計や新しい入力形式・writerの追加方法は
[`ARCHITECTURE.md`](ARCHITECTURE.md)、形式ごとの対応範囲は
[`SUPPORT.md`](SUPPORT.md)を参照してください。

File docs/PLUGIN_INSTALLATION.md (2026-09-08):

# Codex / Claude Code installation

Both integrations are included in the same repository and use the local `docsvg` CLI. They require Rust/Cargo plus the corresponding host CLI. PNG previews also require Python 3 and `rsvg-convert`.

Run from a trusted repository checkout:

| Host | Install | Activate |
|---|---|---|
| Codex | `./scripts/install-codex-plugin.sh` | Start a new task |
| Claude Code | `./scripts/install-claude-plugin.sh` | Restart Claude Code |

Example prompts:

```text
Use document-svg to preview report.docx as SVG pages and report conversion warnings.
document-svgを使ってslides.pptxをSVGプレビューにして、警告も確認して。
使用document-svg将report.pdf转换为逐页SVG预览，并检查转换警告。
```

Codex supports `$document-svg`; Claude Code supports `/document-svg:document-svg`.

The installers build the CLI locally. Registering only the marketplace does not install the native converter. A copied plugin can use an installed `docsvg` on PATH or an explicit `DOCUMENT_SVG_REPO` checkout. Installation is a user action; opening the repository does not trigger it.

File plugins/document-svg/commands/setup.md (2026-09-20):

---
description: Check whether the docsvg CLI is available and show how to install it.
allowed-tools: Bash(${CLAUDE_PLUGIN_ROOT}/skills/document-svg/scripts/ensure-docsvg.sh:*)
---

Check the docsvg installation:

```bash
${CLAUDE_PLUGIN_ROOT}/skills/document-svg/scripts/ensure-docsvg.sh
```

If it prints a path, docsvg is ready; report the path and stop.

If it exits with code 69, docsvg is missing. Show the user the listed options
and ask which one they want:

- `ensure-docsvg.sh --install` downloads the release build for their platform
  from the project's GitHub releases and verifies it against the release
  `SHA256SUMS`. No Rust toolchain is needed.
- `cargo install document-svg --locked` builds it from crates.io.
- A manual download from <https://github.com/ryusui-hiro/document-svg/releases>.

Run an installation only after the user picks one. Do not install anything just
because this command was invoked.

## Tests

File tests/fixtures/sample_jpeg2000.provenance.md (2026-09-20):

# Synthetic DICOM JPEG 2000 fixture

The `.pgm`, `.j2k`, `.jp2`, and `.dcm` files share a 4×4 grayscale image with
sample values `0, 32, 64, 96, ... 160, 255`. FFmpeg's JPEG 2000 encoder creates
the raw Part 1 reversible 5/3 codestream (`-pred dwt53 -format j2k`) and the
boxed JP2 container (`-pred dwt53 -format jp2`). The DICOM Part 10 variant wraps
the raw codestream as one encapsulated frame using transfer syntax UID
`1.2.840.10008.1.2.4.90` and Secondary Capture SOP Class UID.

The DICOM fixture contains no patient or study identifiers. The companion
`sample_jpeg2000_rgb.ppm`/`.jp2` files are a synthetic 4×4 primary-color RGB
image. `sample_jpeg2000_gray16.pgm`/`.jp2` are a synthetic 4×4 grayscale image
with 16-bit samples spanning 0–65535. `sample_jpeg2000_rgba.pam`/`.j2k`/`.jp2`
are a synthetic 4×4 RGB image with alpha values 255, 128, 0, and 64. These raw
and boxed encodings use FFmpeg's reversible 5/3 transform. The fixtures exercise JPEG
2000 decoding, raw/boxed stream support, RGB channel order, 16-bit
normalization, straight-alpha preservation, and bounded SIZ-header validation;
they do not test clinical interpretation or de-identification.

`sample_jpeg2000_rgba_preblended.jp2` is generated by `scripts/generate-jpx-preblended-fixture.py` with FFmpeg 8.0.1 from the RGBA PAM source. The RGB samples are preblended with blue matte `[0, 0, 1]` using `c' = m + alpha * (c - m)`; its SHA256 is `1a6970ecee77536181473ce6b5c343db9e9e0084a5ccbbd9948af7caea241a15`.

`sample_jpx_alpha.pdf` wraps the boxed RGBA JP2 with `/SMaskInData 1`; `sample_jpx_smask_in_data_2.pdf` wraps the preblended JP2 with `/SMaskInData 2` and the matching `/Matte`; `sample_jpx_soft_mask.pdf` wraps RGB JP2 plus an external 2x2 grayscale `/SMask`. These exercise intrinsic alpha modes and separate masks using self-authored synthetic images; no personal or clinical content is present. PDF wrapper hashes are recorded in `pdf_images.provenance.json`.

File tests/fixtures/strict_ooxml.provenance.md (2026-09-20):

# ISO/IEC 29500 Strict OOXML fixtures

`sample_strict.docx`, `sample_strict.xlsx`, and `sample_strict.pptx` are
Strict-namespace variants of the small synthetic packages in
`samples/source/sample.docx`, `sample.xlsx`, and `sample.pptx`. They are
generated by `scripts/generate-strict-ooxml-fixtures.py`, which maps the Office Open XML
Transitional namespaces and relationship type URIs to the ISO Strict PURL
namespaces. Package paths and content types remain unchanged.

The fixtures contain synthetic sample content and no user documents or
personal data. The conversion tests verify that the Word, SpreadsheetML, and
PresentationML parsers follow Strict namespaces and relationship targets.

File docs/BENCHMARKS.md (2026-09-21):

# ベンチマーク

2026-08-22、Apple M5（arm64）、macOS 26.5.1、Rust 1.93.0、`cargo build --release`で測定しました。時間は`conversion.json`の変換処理時間、RSSはmacOS `/usr/bin/time -l`のmaximum resident set sizeです。

## drawio 変換

2026-09-10、`scripts/benchmark-conversion.py`が生成する合成図面（400図形＋399本の直交コネクタ、
64 shapeのstencil library付き）を`--stencils`指定で変換した測定です。同スクリプトは2つのバイナリの
出力がバイト一致することも検証します。

| 経路 | 中央値時間 | 最大RSS |
|---|---:|---:|
| drawio → SVG（stencil解決込み） | 12.0 ms | 7.5 MiB |

実ファイルでの参考値として、drawio公式リポジトリの613テンプレートをdrawioの全stencil
（204ファイル・42 MB）指定で変換した場合、1ファイルあたり中央値10 ms未満、常駐15 MiB以下です。
必要なshapeが揃った時点で残りのlibrary fileを読まないため、library総量は常駐に比例しません。

## drawio 忠実度（drawio自身のSVG書き出しとの比較）

2026-09-10、`scripts/compare-drawio-export.py`で、drawio公式リポジトリのSVG書き出し
（「Include a copy of my diagram」付き）から元の図面を取り出して変換し、同一グリッドで
描画して画素比較しました。drawioはラベルを`foreignObject`で描くため単体レンダラでは
描画されず、比較はテキストを除いた幾何のみです。位置は互いが描いた内容で揃えています。

| 図面 | 比較領域 | 平均差 | `>32`の画素率 |
|---|---:|---:|---:|
| connect-shapes（2件） | 1081x598 | 0.44 | 0.60% |
| infographic | 1012x3206 | 0.15 | 0.14% |
| infographic2 | 776x1700 | 0.42 | 0.37% |
| flowchart | 281x391 | 4.35 | 3.32% |
| svgfile | 612x1017 | 9.10 | 7.29% |

flowchartの残差は、drawioが`viewBox="-0.5 -0.5 …"`で半画素ずらして1px線を画素中心へ
合わせる規約によるもので、幾何自体は一致しています。svgfileはdrawio内蔵clip artを
URL参照で持つページを含み、そのぶんが差になります（外部取得は行いません）。

## ローカル検証用 SVG/OpenXML interoperability regression

2026-08-26、ローカル検証用 backendのSVG fidelity fixtureと実PPTXを使い、librsvg参照画像と
LibreOffice 26.2.2.2経由のOpenXML描画、または元PPTXのLibreOffice描画と生成SVGを
同一寸法RGBで比較しました。`>16`はRGBいずれかのchannel差が16を超えた画素率です。

| 経路・fixture | 修正前 | 修正後 |
|---|---:|---:|
| SVG→PPTX `symbol/use`、`>16` | 24.831% | 1.699% |
| SVG→PPTX multi-layer gradient mask、`>16` | 39.401% | 0.717% |
| ローカル検証用 hybrid PPTX→SVG luminance mask、`>16` | 41.913% | 7.863% |
| ローカル検証用 EMF実slide PPTX→SVG、RGB MAE | 30.701 | 11.207 |
| 同EMF実slide、`>16` | 14.999% | 7.611% |

改善は、`mc:AlternateContent`のChoice/Fallback単一選択、SVG＋PNG compatibility fallback、
EMF/WMFのbounded SVG変換、互換保存用`hiddenFill`／`hiddenLine`の除外、table border色と
cell fill色の分離によるものです。逆変換PPTXはローカル検証用 `validate_pptx_package`にも合格しました。

## PDF fidelity regression

2026-08-26、非公開のPDF QA fixtureを再配布せず参照し、Poppler 144dpiと
生成SVGのlibrsvg描画を同一RGB寸法で比較しました。

| fixture / 実page | 修正前MAE | 修正後MAE | `>16` 修正前→修正後 |
|---|---:|---:|---:|
| multi-subpath stroke (`ExtGState /LW=14`) | 7.818 | 0.476 | 5.428% → 1.208% |
| 000623 page 8相当（`q/Q`＋glyph position） | 23.077 | 13.679 | 15.675% → 12.135% |
| handeji page 22相当（text state＋symbol＋glyph position） | 24.452 | 20.038 | 18.340% → 16.430% |

`ExtGState`のline style全体、`q/Q`でのtext parameter保存、Page-local `UserUnit`、
日本語font fallback stack、既知Wingdings symbolのmonochrome Unicode正規化を追加しました。
さらに、代替fontのadvanceへ依存せず、PDFのglyphごとのx originをpositioned SVG tspanへ
保持することで、run境界の重なりと累積文字幅誤差を抑えました。

明示的な`--outline-embedded-pdf-text`では、同じpage 8相当がMAE 6.312・`>16`
8.876%、page 22相当がMAE 12.058・`>16` 13.132%まで改善しました。1-page SVGは
それぞれ959,458 bytes、1,049,959 bytesで、editable modeより大きくなります。
font outlineの利用・再配布条件は入力fontごとに利用者確認が必要なため、このmodeは既定offで
conversion warningを残します。

| 形式 | 入力 | 出力 | jobs | 変換時間 | 最大RSS | 最大Page IR近似 |
|---|---:|---:|---:|---:|---:|---:|
| PDF | 121,437 bytes | 4 pages | 2 | 36 ms | 24.7 MiB | 1,971,461 bytes |
| PPTX | 27,634 bytes | 4 slides | 1 | 4 ms | 3.4 MiB | 77,349 bytes |
| XLSX | 79,605 bytes | 3 sheets | 1 | 25 ms | 6.3 MiB | 855,092 bytes |
| DOCX | 37,566 bytes | 1 page | 1 | 1 ms | 3.4 MiB | 14,672 bytes |

入力はローカルQA用で配布物には含めません。PDFはIndexed／ICC画像、SMask、約2,000〜2,700 node/pageを含みます。4入力とも警告0でした。XLSXはローカル検証用参照側の実workbookで、cached valueがないformulaもbounded evaluatorで補完しています。DOCXは日本語FAQ文書です。

## PPTX corpus / native table

2026-08-23、ローカル検証用参照側の20 MiB以下のPPTX 228件をrelease版で監査しました。slideを持つ171件・1,012 slidesは全件変換成功・警告0でした。57件はslideを1枚も持たない`template-shell.pptx`で、入力契約どおり`input contains no renderable pages`として拒否しました。

| corpus | renderable files | slides | warning 0 | warningあり | 内部変換時間合計 |
|---|---:|---:|---:|---:|---:|
| ローカル検証用 PPTX | 171 | 1,012 | 171 | 0 | 801 ms |

同じcorpusで補助parserを無条件起動した時点の992 msに対し、local-element preflight後は801 msで、約19.3%短縮しました。

調整値付き`wedgeRectCallout`を含む4:3実slideでは、bounding box近似からECMA guide/path式へ変更し、1200×900描画のcallout領域MAEを0.12587445から0.09866572、全画面MAEを0.27048417から0.26490474へ改善しました。対象3実PPTXの警告はすべて0です。

42 cellのnative tableを含む29,310-byte実PPTXは、1 slideを3 ms、最大RSS 3.3 MiB、最大Page IR近似74,573 bytes、警告0で変換しました。原本PPTXとSVGを1600×900へ描画したnormalized RGB MAEは次のとおりです。

| 状態 | 全画面MAE | table領域MAE |
|---|---:|---:|
| table未実装（titleのみ） | 0.11845390 | 0.17973711 |
| native table＋word-aware wrap | 0.02944266 | 0.03842762 |

実slide/layout/masterの`outerShdw`を`a14:hiddenEffects`と分離して監査すると、可視effectは7 PPTX・34要素でした。direct shape/picture、shape text、table textから27個のbounded SVG filterを10ページへ生成し、7資料すべて変換成功、対象10ページはlibrsvg `--unlimited`で描画成功しました。内部変換時間合計は591 ms、最大Page IRは24,019,956 bytesです。

2,338,275-byte・8ページのtable text shadow資料は20 ms、最大RSS 8,339,456 bytes、最大Page IR 594,079 bytes、警告0で変換しました。release版2回の全8 SVGはバイト一致し、7個のshadow filterを再現しました。互換保存用hidden shadowだけを14個持つ別の10ページ資料はfilter 0で、変更前SVGとバイト一致しています。

同corpusの可視`glow`は7 PPTX・19要素で、すべてconnector shapeの5/8pt radius、scheme color、alpha指定、うち13要素は`satMod`付きでした。19要素を19個のbounded SVG filterとして7ページへ生成し、全7資料変換成功、対象全ページがlibrsvg `--unlimited`で描画成功しました。内部変換時間合計は235 ms、最大Page IRは6,928,586 bytesです。

1,984,132-byte・2ページ・glow 13個の代表資料は57 ms、最大RSS 39,059,456 bytes、最大Page IR 6,928,586 bytes、警告0でした。release版2回の全SVGはバイト一致し、glow追加後もshadow-onlyの8ページ資料は変更前SVGとバイト一致しました。LibreOfficeは元PPTXのglowを安定して再現しないため、合格判定にはOOXML effect件数、filter構造、SVG描画、決定性を使用しています。

非zero theme `effectRef`は16 PPTX・234参照でした。slide→layout→master→themeを解決すると、148参照が実際にshadow/glowを持つtheme styleへ到達し、148個のtheme由来filterを生成しました。残る参照は参照先effect styleがempty、またはshape-local `effectLst`で明示上書きされています。16資料はすべて変換成功し、effectを含む19ページはすべてlibrsvg `--unlimited`で描画成功しました。内部変換時間合計は1,156 ms、最大Page IRは24,019,956 bytesです。

4,348,562-byte・10ページ・theme shadow 6個の代表資料は43 ms、最大RSS 15,269,888 bytes、最大Page IR 3,131,476 bytes、警告0でした。release版2回の全10 SVGはバイト一致しました。2 slideが別master/themeを使い、idx 0、idx 1/2、direct empty overrideを含む専用fixtureでもtheme別shadow/glow解決を検証しています。

PPTX `srcRect`は175資料・844要素で使われ、うち146資料・608要素がnonzero cropでした。全要素中215個はgroup内、142個は回転picture、42属性値は負cropです。nonzero crop 146資料・1,349ページは全件変換成功し、593個のcrop clipを出力しました。内部変換時間合計は4,503 ms、最大Page IRは28,323,725 bytesです。

1,327,543-byte・6ページの実資料page 2を1560×1080で比較すると、全画面normalized RGB MAEは0.21788353から0.19344309へ改善しました。2つの主要crop領域は0.45911464→0.36319640、0.24888556→0.01676657です。crop対応後は24〜27 ms、3 crop clipで全6 SVGが2回のrelease変換でバイト一致し、対象page 2/6をlibrsvgで描画できました。

4,348,562-byte・10ページ・crop 11個の警告0資料は55 ms、最大RSS 14,958,592 bytes、最大Page IR 3,133,030 bytesでした。この資料もrelease版2回の全SVGがバイト一致しています。

PPTX `pattFill`は16資料・55要素で、`narHorz/narVert`各11、`pct5` 8、`wdUpDiag` 8、`openDmnd` 7、`pct90` 6、`wdDnDiag` 3、`dkUpDiag` 1でした。16要素はgroup内、4要素は回転shapeです。全16資料・149ページが変換成功し、55個すべてをcompact vector SVG patternとして18ページへ出力しました。対象18ページはすべてlibrsvg `--unlimited`で描画成功し、内部変換時間合計は488 ms、最大Page IRは5,034,052 bytesです。

2,010,200-byte・11ページ・pattern 6個の警告0資料は33 ms、最大RSS 9,240,576 bytes、最大Page IR 1,063,028 bytesでした。release版2回の全11 SVGはバイト一致し、横・縦hatchの線密度はLibreOffice描画へ合わせて2.0/1.5pt周期、0.4/0.3pt線へ調整しています。

PPTX image color effectは15資料・45要素で、duotone 23、exact `clrChange` 19、grayscale 2、brightness 1でした。全15資料・141ページが変換成功し、45 source effectを45個のordered SVG filter stageへ変換しました。effectを含む19ページはすべてlibrsvg `--unlimited`で描画成功し、内部変換時間合計は362 ms、最大Page IRは4,657,610 bytesです。

4,511,916-byte・17ページ・duotone 8個の実資料では、1600×1200全画面MAEがpage 3で0.10908561→0.09340865、page 4で0.13061325→0.12133024へ改善しました。

495,895-byte・7ページ・exact color-change 2個の警告0資料は9 ms、最大RSS 6,651,904 bytes、最大Page IR 410,238 bytesでした。page 3 MAEは0.04728162→0.04684454へ改善し、release版2回の全7 SVGはバイト一致しました。

20 MiB以下の重複除去PPTX 215件で警告を分類すると、rightBrace 213、arc 78、bentConnector3 40、leftBrace 38、flowChartManualInput 37、can 32、flowChartExtract 28、flowChartDecision 18、bentConnector2 13が上位でした。adjustment対応native path追加後も215/215件が変換成功し、警告資料は143→84、distinct warningは822→325へ減少しました。合計497警告を除去し、内部変換時間合計は4,575 ms、最大Page IRは70,927,302 bytesです。

1,327,543-byte・6ページのarc/can実資料は警告14→3となり、残る3件は未対応donut/rightBracketとinvalid tableだけです。

2,254,542-byte・8ページ・rightBrace 4個の代表資料は29 ms、最大RSS 11,780,096 bytes、最大Page IR 1,769,476 bytes、警告0でした。release版2回の全8 SVGはバイト一致し、対象page 6をlibrsvgで描画できました。

第2 preset群としてmoon、bent/bent-up/uturn/curved-left/left-right arrow、delay/connector/collate/process flowchart、cube、left/right/bracketPair、donut、snip2SameRect、homePlate、corner、wave、actionButtonForwardNext、mathPlusを追加しました。215件は引き続き215/215変換成功し、警告資料は84→62、distinct warningは325→185へ減少しました。第1弾前からの累計は143→62、822→185で、637警告を除去しています。内部変換時間合計は4,616 ms、最大Page IRは70,927,302 bytesです。

996,669-byte・8ページのmoon/collate資料は警告16→8となり、preset geometry警告は0です。残る8件はtransformを持たないplaceholder shapeです。

1,178,906-byte・8ページ・第2 preset 20個の代表資料は40 ms、最大RSS 37,126,144 bytes、最大Page IR 4,465,225 bytes、警告0でした。release版2回の全8 SVGはバイト一致し、全8ページをlibrsvgで描画できました。

残るtransform警告をXML監査すると、zero-size Line/Rectangleの空paragraph＋hiddenFill/hiddenLine互換artifactと、実fieldを持つfooter/slide-number placeholderが混在していました。空artifactだけを無警告除外し、placeholderをidx→unique type fallback→bounded既定位置の順で回復した結果、215件・1,910ページは全件成功のまま、警告資料は62→21、distinct warningは185→36へ減少しました。preset改善前からの累計は143→21、822→36で786警告を除去しています。内部変換時間合計は4,698 ms、最大Page IRは70,927,302 bytesです。

996,669-byte・8ページのmoon/collate＋zero-size互換shape資料は警告16→0となりました。

footer/slide-numberを含む実資料は12ページ・23 ms・最大RSS 8,617,984 bytes・最大Page IR 703,764 bytes・警告0で、全12ページをlibrsvg描画できました。release版2回の全SVGはバイト一致しました。

残るtable警告13件はすべてframe幅・高さとcolumn幅が有効で、row `h=0`だけが欠落したOffice auto-row tableでした。zero metricをframe extentから復元し、wedgeRoundRect/wedgeEllipse/border callout、rare arrow/sealを追加した結果、215件・1,910ページは215/215成功のまま、警告資料は21→3、distinct warningは36→4となりました。残る4件はすべてOLEを静的previewとして保持したことを知らせる意図的通知です。preset改善前からの累計は143→3、822→4で818警告を除去しました。内部変換時間合計は4,663 ms、最大Page IRは70,927,302 bytesです。

1,327,543-byte・6ページのtable/callout資料は警告14→0となり、20 ms、最大RSS 16,416,768 bytes、最大Page IR 2,466,422 bytesでした。release版2回の全6 SVGはバイト一致し、全6ページをlibrsvg描画できました。

## XLSX corpus / bounded auto tile

2026-08-23、ローカル検証用参照側の20 MiB以下のXLSX 184件をSHA-256で重複除去し、139 unique workbookをrelease版で監査しました。変更前は138件成功・1件canvas上限失敗・警告10件・599 SVG pages・最大Page IR 65,102,928 bytesでした。auto tile、formula resolver、Drawing fallback後は139件すべて成功・警告0、860 SVG pages、最大Page IR 17,872,542 bytesです。内部変換時間合計は10.085秒でした。

| 状態 | 成功/unique | 警告workbook | SVG pages | 最大Page IR |
|---|---:|---:|---:|---:|
| 変更前 | 138/139 | 10 | 599 | 65,102,928 bytes |
| bounded auto tile／formula／Drawing fallback後 | 139/139 | 0 | 860 | 17,872,542 bytes |

159,835-byteの密集workbookは4 pages・最大Page IR 56,121,280 bytes・最大RSS 156.9 MiBから、14 pages・6,769,476 bytes・37.5 MiBへ改善しました。総SVG内容は保持したままページ単位streamingの常駐量を抑えています。

従来canvas高220,503ptで失敗した1,904,989-byte／13-sheet workbookは、53 pages・1.399 s・最大Page IR 7,920,142 bytes・最大RSS 124.8 MiB・警告0で完走しました。

955,150-byteの実workbookでは、37個の未cached式、cross-sheet参照、単一cell definedName、exact VLOOKUP、文字列IF、conditional expression、hidden互換drawingを順に解決し、警告8件から0件へ改善しました。最終releaseは6 pages・47 ms・最大Page IR 611,872 bytes・最大RSS 33.3 MiBです。

## DOCX corpus / LibreOffice comparison

2026-08-23、ローカル実DOCX 307件をSHA-256で重複除去し、54 unique documentをrelease版で監査しました。全54件・93 SVG pagesが変換成功・警告0で、最大Page IRは1,711,222 bytesです。

5,953,676-byteの科学文書は、word-aware wrap、script font fallback、style chain、super/subscript対応前の24 SVG pagesから25 pagesへ変化し、LibreOfficeの28 pagesへ近づきました。先頭ページを1414×2000へ描画したnormalized RGB MAEは0.09218703から0.07480915へ改善しました。最終releaseでは25 pages・49 ms・最大Page IR 1,711,222 bytes・最大RSS 31.8 MiB・警告0です。

警告対象だった2件の数式文書では、OMML fraction 43、super/subscript run 284、radical 6をsemantic linear SVGへ変換しました。このうち同科学文書の数式ページでは、1414×2000描画MAEを0.08664780から0.07063865へ改善しました。

| 実文書 | 変更前Rust | 変更後Rust | LibreOffice |
|---|---:|---:|---:|
| low-energy diamond MEMS | 24 | 25 | 28 |
| diamond MOSFET | 5 | 5 | 4 |
| Young's modulus | 3 | 3 | 2 |
| silicon nanostructure | 1 | 1 | 1 |
| silicon metasurface | 2 | 2 | 2 |

測定コマンド例:

```bash
cargo build --release
/usr/bin/time -l target/release/docsvg input.pdf --output .tmp/bench/pdf --jobs 2
```

`jobs`を増やすとPDFページのスループットは上がりますが、同時に保持するPage IRと画像bufferも増えます。常駐メモリ優先なら既定の`jobs=1`を使用してください。

111ページ・embedded Type1 outlineを含むPDFで、全ページIRを保持しないbounded streamingを確認しました。

| jobs | 変換時間 | 最大RSS | 同時Page IR上限 | warning |
|---:|---:|---:|---:|---:|
| 1 | 3.972 s | 21.2 MiB | 1 | 0 |
| 4 | 1.737 s | 30.8 MiB | 4 | 0 |

並列時も`jobs`件ずつ入力順にconsumeするため、111ページ分のPage IRを一括保持しません。

## PDF feature fidelity

非公開のPDF QA fixtureをPDF原画とSVGへそれぞれ144dpiで描画し、同一RGB寸法の平均絶対誤差を測定しました。

| feature | normalized RGB MAE | warning |
|---|---:|---|
| direct Multiply blend | 0.00000000 | 0 |
| nested clip intersection | 0.00034807 | 0 |
| isolated group＋axial gradient | 0.00035639 | 0 |
| axial gradient | 0.00051176 | 0 |
| image＋vector luminosity mask、Interpolate=false | 0.00102436 | 0 |
| radial gradient（contained） | 0.00133301 | 0 |
| path＋vector luminosity mask | 0.00142816 | 0 |
| embedded Type1 fill＋stroke text | 0.00019430 | 0 |
| Type3 CharProc glyph text | 0.00041496 | 0 |
| Type1 rendering mode 7 glyph-union clip | 0.00016022 | 0 |
| CCITT Group4 inline image | 0.00115741 | 0 |
| CCITT Group3 1D inline image | 0.00115741 | 0 |
| CCITT Group3 2D inline image | 0.00348428 | 0 |
| LZW inline image | 0.00454265 | 0 |
| damaged-row CCITT Group3 2D（EOL再同期） | 0.00019290 | 0 |
| Function shading Type 1 / Function Type 4 | 0.00486632（塗り内部0.00148511） | 0 |
| noncontained radial（extended） | 0.00273752 | 0 |
| noncontained radial（unextended） | 0.00447967 | 0 |
| noncontained radial in soft mask | 0.00060045 | 0 |
| Type 4 Gouraud mesh（adaptive max 64 / 3,000 triangle budget） | 0.00663824 | 0 |
| Type 5 lattice mesh（adaptive max 64 / 3,000 triangle budget） | 0.00742310 | 0 |
| Type 6 Coons patch mesh（3,000 triangle budget） | 0.00732474 | 0 |
| Type 7 tensor patch mesh（3,000 triangle budget） | 0.00729982 | 0 |
| Separation/DeviceN/Lab/ICC path＋image | 0.00257190 | 0 |
| Shading Pattern fill/stroke/text/BBox | 0.00049804〜0.00391155 | 0 |
| Tiling Pattern colored/uncolored＋affine CTM | 0.01537951〜0.02345359 | 0 |
| soft-mask Function `/TR`（x²） | 0.00000000 | 0 |
| PPTX custom geometry＋solid alpha | 0.00025219 | 0 |
| PPTX SmartArt cached drawing（theme transform＋shape image） | 0.03515396 | 0 |

MAEはページ境界やrasterizerのcoverage差も含む全画面値です。Function shadingは境界を除いた塗り内部値も併記しました。

重複を除いた小型PDF 186件・394ページのrelease回帰では184件を8.135秒で変換しました。183件は警告0、1件は`/Shading`がMask辞書を指す意図的な不正resourceを警告しました。残る2件の失敗は参照側に意図的に残されたinvalid trailer PDFです。

## Large real-PDF corpus / mesh memory

2026-08-23、2–20 MiBの実PDFからページ数を層化して30件・1,660 pagesを抽出しました。初回は24件成功、JPEG SMask・external CCITT・inline-image token誤検出で6件失敗しました。JPEG SMask decoder、external CCITT DecodeParms、syntax-aware BI/ID scan追加後は30件すべて変換成功しました。

19,362,031-byte／33-page実PDFでは、同一pageの複数mesh shadingが1,261,568 triangleを生成していました。per-shading 3,000 triangle budget後は最大Page IR 836,631,120→53,659,918 bytes、変換時間5.696→1.367秒、最大RSS 258.9 MiBへ改善しましたが、DeviceRGB meshが座標range＋共有`[0,1]`だけの6-value `/Decode`を使うため警告1件でskipされていました。

共有component rangeをRGBへ展開するだけでは最大Page IR 164,325,554 bytes・最大RSS 526,712,832 bytesへ増えたため採用せず、nested pattern/maskを含むpage全体50,000 triangle budgetを追加しました。最終releaseは1.519秒、最大Page IR 51,766,293 bytes、page 26 SVG 35,551,145 bytes、最大RSS 261,275,648 bytes、警告0です。960×540 page 26 MAEはbudget前後とも0.23553602で、Type4–7単独fixtureの144dpi MAE 0.00664–0.00742も維持します。release版2回の全33 SVGはバイト一致しました。

5,692,146-byte／276-page TI datasheetはexternal CCITT stencilを含みます。最終releaseでは1.089秒、最大Page IR 3,153,912 bytes、最大RSS 119.4 MiB、警告0で完走し、該当249ページもlibrsvgで描画確認しました。

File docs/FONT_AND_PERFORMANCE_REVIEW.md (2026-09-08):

# Font parser migration and conversion efficiency

2026-09-08 follow-up to the initial alpha source release.

## Changes

- Replaced `ttf-parser` with `skrifa 0.44.0`, the maintained alternative identified by RustSec advisory RUSTSEC-2026-0192. The renderer already uses this version, so the migration removes one dependency without introducing another version of the font stack.
- Kept PDF-specified advances, unhinted font-unit outlines, character-code cmap fallback and raw Type1/CFF fallback. Malformed outline errors now propagate to the existing warning/fallback path instead of being ignored.
- Added synthetic-font regressions for TrueType contours, quadratic curves, composites, spaces, missing glyphs, malformed glyphs, OpenType CFF and `.notdef` handling. Added a public PDF conversion test for embedded TrueType outlining and deterministic output. No third-party font files are included.
- Reused the font database within each reverse conversion instead of rescanning system fonts per page. Each new conversion still loads its own database; there is no global stale-font cache.
- Kept the existing serialized IR-size metric while counting bytes without retaining a page-sized JSON allocation.
- Borrowed text/attributes when XML escaping is unnecessary, avoiding repeated copies of embedded image data. Escaping and control-character behavior remain unchanged.
- Excluded native shared-library build products (`.so`, `.pyd`, `.dylib`) from Git and flagged them in publication checks if explicitly staged.

## Measured comparison

Baseline: commit `e9500a2`, release-mode CLI. Local macOS arm64 measurement; one warm-up followed by three interleaved runs per binary. Values below are medians. Fixtures are generated by `scripts/benchmark-conversion.py`.

| Workload | Before | After |
|---|---:|---:|
| 100 small SVG pages containing text → PPTX, elapsed | 0.9785 s | 0.1037 s |
| DOCX containing a synthetic 2048×2048 PNG → SVG, elapsed | 0.1197 s | 0.0707 s |
| Same DOCX, peak resident memory | 136.19 MiB | 50.61 MiB |

The benchmark verified byte-identical PPTX packages and SVG output across all runs. The reported IR size remained exactly 22,374,739 bytes. These are targeted synthetic workloads, not general speed guarantees for every document.

```sh
python3 scripts/benchmark-conversion.py --before /path/to/baseline/docsvg --after target/release/docsvg
```

The script needs Python 3.10+, macOS or Linux, and `/usr/bin/time`. It creates its own fixtures and removes its temporary directory afterward. Font-outline command sequences can differ between parsers while representing the same contour; the byte-equality benchmark applies to the two workloads above, not to every outlined PDF.

## Verification

The migrated lockfile contains no `ttf-parser`, and the RustSec audit reports no vulnerabilities or maintenance warnings. Workspace tests, formatting and Clippy cover the implementation; the language bindings are rebuilt against the new core. The initial-release audit remains historical evidence for v0.1.0 rather than the current dependency state.

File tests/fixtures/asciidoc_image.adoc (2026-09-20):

= Image appendix

:imagesdir: assets

This paragraph comes before the figure.

Red and blue test image

Remote image

This paragraph comes after the figure.

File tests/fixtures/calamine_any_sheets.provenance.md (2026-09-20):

`calamine_any_sheets.xlsb` is copied from the Calamine 0.36.1 test suite:
https://github.com/tafia/calamine/blob/master/tests/any_sheets.xlsb

The upstream Calamine project is MIT-licensed. This small workbook is used only for read-only XLSB conversion regression tests.
SHA-256: ad645571475f1e30875610fc51ad7726d8b7af296850135bc593e15ead0e28c6

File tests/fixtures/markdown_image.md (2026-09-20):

# Markdown image preview

Text before the standalone image.

red-blue Markdown image

Text before an inline image red-blue inline image with trailing text.

red-blue reference image

[chart-image]: <assets/red%2Dblue.png>

remote image

escaped image

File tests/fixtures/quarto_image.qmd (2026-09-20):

---
title: Quarto image preview
author: Analysis Team
---

# Findings

The report includes a local figure and a reference-style figure.

Local Quarto image

Reference Quarto image

[figure]: <assets/red%2Dblue.png>

Remote image

```{r}
plot(c(1, 2, 3))
```

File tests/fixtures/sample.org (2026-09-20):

#+TITLE: Org-mode Architecture Notes
#+AUTHOR: Document Team
#+OPTIONS: toc:nil

* TODO Overview
Org mode is a plain-text outline with *bold*, /emphasis/, =verbatim=, and
[[https://example.invalid][external links]] that are shown as text only.

* Components :preview:
1. Parser
2. Typesetter
- Safe local assets

** Implementation
| Module | Status |
|--------+--------|
| Parser | Ready |
| SVG | Ready |

#+CAPTION: Local Org image caption
#+ATTR_ORG: :width 96


#+BEGIN_SRC emacs-lisp
(delete-file "/tmp/must-not-run")
#+END_SRC

#+BEGIN_EXPORT html
<script>must-not-render()</script>
#+END_EXPORT

#+INCLUDE: "/etc/passwd"
#+CALL: dangerous-block()

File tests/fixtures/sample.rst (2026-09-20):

Document Conversion Notes
=========================

Overview
--------

reStructuredText headings use adornment lines. This paragraph includes **strong**
text, *emphasis*, ``inline code``, a :ref:`named target`, and a `visible link <https://example.invalid>`_.

Features
~~~~~~~~

* Multiple section levels
* Numbered steps

#. Read the page
#. Render the SVG

Literal example::

    print("markup is not evaluated")

.. note:: Safe preview

   Directives that could read files or insert raw output stay inactive.

Simple table
------------

==============  ===========
Component       Status
==============  ===========
Parser          Ready
Renderer        Ready
==============  ===========

Grid table
----------

+-----------+----------------+
| Format    | Preview        |
+===========+================+
| reST      | Sectioned text |
+-----------+----------------+

Local figure
------------

RST red and blue image

   Figure caption is retained below the image.

remote image

.. include:: must-not-be-read.txt

.. raw:: html

   <script>must-not-run()</script>

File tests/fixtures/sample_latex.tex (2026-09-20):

\documentclass{article}
\usepackage{graphicx}
\graphicspath{{assets/}}
\title{LaTeX Document Preview}
\author{Conversion Team}
\date{2026-09-15}

\begin{document}
\maketitle

\section{Overview}
This is a complete LaTeX document with inline math $x^2 + y^2$ and safe source previewing.

\begin{itemize}
\item Deterministic document structure
\item No TeX execution
\end{itemize}

\begin{figure}

\caption{Local red and blue figure}
\end{figure}

\begin{tabular}{ll}
Name & Value \\
Preview & Ready \\
\end{tabular}

\input{not-loaded.tex}
\end{document}

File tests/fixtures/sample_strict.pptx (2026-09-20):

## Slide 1

document-svg
PDF and Office documents as self-contained SVG pages

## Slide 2

One page in, one SVG out

• Every page becomes page-NNNN.svg
• Fonts, shapes and images stay in the file
• A conversion.json records warnings and timing
• Nothing is fetched at render time

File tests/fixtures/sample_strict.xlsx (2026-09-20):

Quarterly sales by region
Region | Product | Month | Units | Unit price | Revenue
North | Carretera | 2026-01-01 | 120 | 12.50 | 1500.00
South | Carretera | 2026-02-01 | 157 | 15.75 | 2472.75
East | Carretera | 2026-03-01 | 194 | 19.00 | 3686.00
West | Carretera | 2026-04-01 | 231 | 22.25 | 5139.75
North | Montana | 2026-05-01 | 268 | 25.50 | 6834.00
South | Montana | 2026-06-01 | 305 | 28.75 | 8768.75
East | Montana | 2026-07-01 | 342 | 32.00 | 10944.00
West | Montana | 2026-08-01 | 379 | 35.25 | 13359.75
North | Paseo | 2026-09-01 | 416 | 38.50 | 16016.00
South | Paseo | 2026-10-01 | 453 | 41.75 | 18912.75
East | Paseo | 2026-11-01 | 490 | 45.00 | 22050.00
West | Paseo | 2026-12-01 | 527 | 48.25 | 25427.75
North | Velo | 2026-01-01 | 564 | 51.50 | 29046.00
South | Velo | 2026-02-01 | 601 | 54.75 | 32904.75
East | Velo | 2026-03-01 | 638 | 58.00 | 37004.00
West | Velo | 2026-04-01 | 675 | 61.25 | 41343.75
North | VTT | 2026-05-01 | 712 | 64.50 | 45924.00
South | VTT | 2026-06-01 | 749 | 12.50 | 9362.50
East | VTT | 2026-07-01 | 786 | 15.75 | 12379.50
West | VTT | 2026-08-01 | 823 | 19.00 | 15637.00
North | Amarilla | 2026-09-01 | 860 | 22.25 | 19135.00
South | Amarilla | 2026-10-01 | 897 | 25.50 | 22873.50
East | Amarilla | 2026-11-01 | 934 | 28.75 | 26852.50
West | Amarilla | 2026-12-01 | 971 | 32.00 | 31072.00
North | Carretera | 2026-01-01 | 1008 | 35.25 | 35532.00
South | Carretera | 2026-02-01 | 145 | 38.50 | 5582.50
East | Carretera | 2026-03-01 | 182 | 41.75 | 7598.50
West | Carretera | 2026-04-01 | 219 | 45.00 | 9855.00
North | Montana | 2026-05-01 | 256 | 48.25 | 12352.00
South | Montana | 2026-06-01 | 293 | 51.50 | 15089.50
East | Montana | 2026-07-01 | 330 | 54.75 | 18067.50
West | Montana | 2026-08-01 | 367 | 58.00 | 21286.00
North | Paseo | 2026-09-01 | 404 | 61.25 | 24745.00
South | Paseo | 2026-10-01 | 441 | 64.50 | 28444.50
East | Paseo | 2026-11-01 | 478 | 12.50 | 5975.00
West | Paseo | 2026-12-01 | 515 | 15.75 | 8111.25
North | Velo | 2026-01-01 | 552 | 19.00 | 10488.00
South | Velo | 2026-02-01 | 589 | 22.25 | 13105.25
East | Velo | 2026-03-01 | 626 | 25.50 | 15963.00
West | Velo | 2026-04-01 | 663 | 28.75 | 19061.25
North | VTT | 2026-05-01 | 700 | 32.00 | 22400.00
South | VTT | 2026-06-01 | 737 | 35.25 | 25979.25
East | VTT | 2026-07-01 | 774 | 38.50 | 29799.00
West | VTT | 2026-08-01 | 811 | 41.75 | 33859.25
North | Amarilla | 2026-09-01 | 848 | 45.00 | 38160.00
South | Amarilla | 2026-10-01 | 885 | 48.25 | 42701.25
East | Amarilla | 2026-11-01 | 922 | 51.50 | 47483.00
West | Amarilla | 2026-12-01 | 959 | 54.75 | 52505.25
North | Carretera | 2026-01-01 | 996 | 58.00 | 57768.00
South | Carretera | 2026-02-01 | 133 | 61.25 | 8146.25
East | Carretera | 2026-03-01 | 170 | 64.50 | 10965.00
West | Carretera | 2026-04-01 | 207 | 12.50 | 2587.50
North | Montana | 2026-05-01 | 244 | 15.75 | 3843.00
South | Montana | 2026-06-01 | 281 | 19.00 | 5339.00
East | Montana | 2026-07-01 | 318 | 22.25 | 7075.50
West | Montana | 2026-08-01 | 355 | 25.50 | 9052.50
North | Paseo | 2026-09-01 | 392 | 28.75 | 11270.00
South | Paseo | 2026-10-01 | 429 | 32.00 | 13728.00
East | Paseo | 2026-11-01 | 466 | 35.25 | 16426.50
West | Paseo | 2026-12-01 | 503 | 38.50 | 19365.50
North | Velo | 2026-01-01 | 540 | 41.75 | 22545.00
South | Velo | 2026-02-01 | 577 | 45.00 | 25965.00
East | Velo | 2026-03-01 | 614 | 48.25 | 29625.50
West | Velo | 2026-04-01 | 651 | 51.50 | 33526.50
North | VTT | 2026-05-01 | 688 | 54.75 | 37668.00
South | VTT | 2026-06-01 | 725 | 58.00 | 42050.00
East | VTT | 2026-07-01 | 762 | 61.25 | 46672.50
West | VTT | 2026-08-01 | 799 | 64.50 | 51535.50
North | Amarilla | 2026-09-01 | 836 | 12.50 | 10450.00
South | Amarilla | 2026-10-01 | 873 | 15.75 | 13749.75
East | Amarilla | 2026-11-01 | 910 | 19.00 | 17290.00
West | Amarilla | 2026-12-01 | 947 | 22.25 | 21070.75
North | Carretera | 2026-01-01 | 984 | 25.50 | 25092.00
South | Carretera | 2026-02-01 | 121 | 28.75 | 3478.75
East | Carretera | 2026-03-01 | 158 | 32.00 | 5056.00
West | Carretera | 2026-04-01 | 195 | 35.25 | 6873.75
North | Montana | 2026-05-01 | 232 | 38.50 | 8932.00
South | Montana | 2026-06-01 | 269 | 41.75 | 11230.75
East | Montana | 2026-07-01 | 306 | 45.00 | 13770.00
West | Montana | 2026-08-01 | 343 | 48.25 | 16549.75
North | Paseo | 2026-09-01 | 380 | 51.50 | 19570.00
South | Paseo | 2026-10-01 | 417 | 54.75 | 22830.75
East | Paseo | 2026-11-01 | 454 | 58.00 | 26332.00
West | Paseo | 2026-12-01 | 491 | 61.25 | 30073.75
North | Velo | 2026-01-01 | 528 | 64.50 | 34056.00
South | Velo | 2026-02-01 | 565 | 12.50 | 7062.50
East | Velo | 2026-03-01 | 602 | 15.75 | 9481.50
West | Velo | 2026-04-01 | 639 | 19.00 | 12141.00
North | VTT | 2026-05-01 | 676 | 22.25 | 15041.00
South | VTT | 2026-06-01 | 713 | 25.50 | 18181.50
East | VTT | 2026-07-01 | 750 | 28.75 | 21562.50
West | VTT | 2026-08-01 | 787 | 32.00 | 25184.00
North | Amarilla | 2026-09-01 | 824 | 35.25 | 29046.00
South | Amarilla | 2026-10-01 | 861 | 38.50 | 33148.50
East | Amarilla | 2026-11-01 | 898 | 41.75 | 37491.50
West | Amarilla | 2026-12-01 | 935 | 45.00 | 42075.00
North | Carretera | 2026-01-01 | 972 | 48.25 | 46899.00
South | Carretera | 2026-02-01 | 1009 | 51.50 | 51963.50
East | Carretera | 2026-03-01 | 146 | 54.75 | 7993.50
West | Carretera | 2026-04-01 | 183 | 58.00 | 10614.00
North | Montana | 2026-05-01 | 220 | 61.25 | 13475.00
South | Montana | 2026-06-01 | 257 | 64.50 | 16576.50
East | Montana | 2026-07-01 | 294 | 12.50 | 3675.00
West | Montana | 2026-08-01 | 331 | 15.75 | 5213.25
North | Paseo | 2026-09-01 | 368 | 19.00 | 6992.00
South | Paseo | 2026-10-01 | 405 | 22.25 | 9011.25
East | Paseo | 2026-11-01 | 442 | 25.50 | 11271.00
West | Paseo | 2026-12-01 | 479 | 28.75 | 13771.25
North | Velo | 2026-01-01 | 516 | 32.00 | 16512.00
South | Velo | 2026-02-01 | 553 | 35.25 | 19493.25
East | Velo | 2026-03-01 | 590 | 38.50 | 22715.00
West | Velo | 2026-04-01 | 627 | 41.75 | 26177.25
North | VTT | 2026-05-01 | 664 | 45.00 | 29880.00
South | VTT | 2026-06-01 | 701 | 48.25 | 33823.25
East | VTT | 2026-07-01 | 738 | 51.50 | 38007.00
West | VTT | 2026-08-01 | 775 | 54.75 | 42431.25
North | Amarilla | 2026-09-01 | 812 | 58.00 | 47096.00
South | Amarilla | 2026-10-01 | 849 | 61.25 | 52001.25
East | Amarilla | 2026-11-01 | 886 | 64.50 | 57147.00
West | Amarilla | 2026-12-01 | 923 | 12.50 | 11537.50
North | Carretera | 2026-01-01 | 960 | 15.75 | 15120.00
South | Carretera | 2026-02-01 | 997 | 19.00 | 18943.00
East | Carretera | 2026-03-01 | 134 | 22.25 | 2981.50
West | Carretera | 2026-04-01 | 171 | 25.50 | 4360.50
North | Montana | 2026-05-01 | 208 | 28.75 | 5980.00
South | Montana | 2026-06-01 | 245 | 32.00 | 7840.00
East | Montana | 2026-07-01 | 282 | 35.25 | 9940.50
West | Montana | 2026-08-01 | 319 | 38.50 | 12281.50
North | Paseo | 2026-09-01 | 356 | 41.75 | 14863.00
South | Paseo | 2026-10-01 | 393 | 45.00 | 17685.00
East | Paseo | 2026-11-01 | 430 | 48.25 | 20747.50
West | Paseo | 2026-12-01 | 467 | 51.50 | 24050.50
North | Velo | 2026-01-01 | 504 | 54.75 | 27594.00
South | Velo | 2026-02-01 | 541 | 58.00 | 31378.00
East | Velo | 2026-03-01 | 578 | 61.25 | 35402.50
West | Velo | 2026-04-01 | 615 | 64.50 | 39667.50
North | VTT | 2026-05-01 | 652 | 12.50 | 8150.00
South | VTT | 2026-06-01 | 689 | 15.75 | 10851.75
East | VTT | 2026-07-01 | 726 | 19.00 | 13794.00
West | VTT | 2026-08-01 | 763 | 22.25 | 16976.75
North | Amarilla | 2026-09-01 | 800 | 25.50 | 20400.00
South | Amarilla | 2026-10-01 | 837 | 28.75 | 24063.75
East | Amarilla | 2026-11-01 | 874 | 32.00 | 27968.00
West | Amarilla | 2026-12-01 | 911 | 35.25 | 32112.75
North | Carretera | 2026-01-01 | 948 | 38.50 | 36498.00
South | Carretera | 2026-02-01 | 985 | 41.75 | 41123.75
East | Carretera | 2026-03-01 | 122 | 45.00 | 5490.00
West | Carretera | 2026-04-01 | 159 | 48.25 | 7671.75
North | Montana | 2026-05-01 | 196 | 51.50 | 10094.00
South | Montana | 2026-06-01 | 233 | 54.75 | 12756.75
East | Montana | 2026-07-01 | 270 | 58.00 | 15660.00
West | Montana | 2026-08-01 | 307 | 61.25 | 18803.75
North | Paseo | 2026-09-01 | 344 | 64.50 | 22188.00
South | Paseo | 2026-10-01 | 381 | 12.50 | 4762.50
East | Paseo | 2026-11-01 | 418 | 15.75 | 6583.50
West | Paseo | 2026-12-01 | 455 | 19.00 | 8645.00
North | Velo | 2026-01-01 | 492 | 22.25 | 10947.00
South | Velo | 2026-02-01 | 529 | 25.50 | 13489.50
East | Velo | 2026-03-01 | 566 | 28.75 | 16272.50
West | Velo | 2026-04-01 | 603 | 32.00 | 19296.00
North | VTT | 2026-05-01 | 640 | 35.25 | 22560.00
South | VTT | 2026-06-01 | 677 | 38.50 | 26064.50
East | VTT | 2026-07-01 | 714 | 41.75 | 29809.50
West | VTT | 2026-08-01 | 751 | 45.00 | 33795.00
North | Amarilla | 2026-09-01 | 788 | 48.25 | 38021.00
South | Amarilla | 2026-10-01 | 825 | 51.50 | 42487.50
East | Amarilla | 2026-11-01 | 862 | 54.75 | 47194.50
West | Amarilla | 2026-12-01 | 899 | 58.00 | 52142.00
North | Carretera | 2026-01-01 | 936 | 61.25 | 57330.00
South | Carretera | 2026-02-01 | 973 | 64.50 | 62758.50
East | Carretera | 2026-03-01 | 1010 | 12.50 | 12625.00
West | Carretera | 2026-04-01 | 147 | 15.75 | 2315.25
North | Montana | 2026-05-01 | 184 | 19.00 | 3496.00
South | Montana | 2026-06-01 | 221 | 22.25 | 4917.25
East | Montana | 2026-07-01 | 258 | 25.50 | 6579.00
West | Montana | 2026-08-01 | 295 | 28.75 | 8481.25
North | Paseo | 2026-09-01 | 332 | 32.00 | 10624.00
South | Paseo | 2026-10-01 | 369 | 35.25 | 13007.25
East | Paseo | 2026-11-01 | 406 | 38.50 | 15631.00
West | Paseo | 2026-12-01 | 443 | 41.75 | 18495.25

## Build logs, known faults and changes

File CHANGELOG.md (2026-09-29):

# Changelog

## Unreleased
- Draw STEP `TRIMMED_CURVE` and `COMPOSITE_CURVE` geometry: a trimmed line, circle, ellipse or B-spline is cut at its `CARTESIAN_POINT` or `PARAMETER_VALUE` trims (a `.F.` sense agreement gives the complementary arc) and composite curves draw each segment's curve; basis curves drawn this way are no longer drawn a second time as full standalone curves. Previously trimmed and composite curves, common in 2D STEP drawings, were skipped entirely.
- Read more IGES entities: conic arcs (104), parametric spline curves (112), points (116), general-note text (212, with Hollerith strings that may contain the delimiters) and transformation matrices (124, applied through each entity's directory-entry pointer, including chained parents). Only lines, circular arcs, copious data and rational B-splines were drawn before, always in their definition space.
- Read the LTYPE table of Autodesk DWG R11/R12 (`AC1009`) drawings, so lines, arcs, circles and polylines with an entity-level or BYLAYER dashed, dotted, center or phantom linetype are drawn with that linetype's real dash pattern instead of as continuous lines.
- Draw classic `POLYLINE`/`VERTEX` groups correctly in both DXF and DWG R11/R12 when they are not plain polylines: spline-fit polylines now show only their fit vertices (the frame control points used to be drawn as an extra zig-zag on top of the curve), M×N polygon meshes are drawn as their row and column polylines, and polyface meshes as the visible edges of their face records, instead of one polyline threaded through every vertex.
- Honour `TEXT` justification in DXF and DWG R11/R12: center, right, middle, aligned and fit text is anchored at its alignment point with the matching SVG text anchor, and bottom/middle/top vertical justification shifts the baseline, instead of every string being drawn left/baseline from that point. Aligned and fit text is centered between its two points.
- Draw real geometry from Autodesk DWG Release 11/12 (`AC1009`) drawings instead of only a version-header preview. LINE, POINT, CIRCLE, ARC, SOLID, TRACE, TEXT, ATTDEF/ATTRIB (as text, skipping ones flagged invisible), the classic POLYLINE/VERTEX/SEQEND group, 3DFACE and VIEWPORT (its border rectangle) are decoded from the binary `entities` section, colored and layer-visibility-filtered (frozen/off) via the LAYER table, and rendered through the same pipeline as the DXF reader (`src/cad/dwg.rs`). INSERT and DIMENSION block references are expanded too — the BLOCK table resolves each one's numeric block index to a name, matched against a block definition decoded from the separate `block_entities` section; INSERT is drawn with its own translation/scale/rotation (including nested INSERTs), and DIMENSION at the identity transform, since AutoCAD always caches a fully world-placed dimension picture as an anonymous block rather than storing dimension geometry to compute. Both reuse the DXF reader's existing recursion-depth and cycle protection. SHAPE entities, which reference a glyph in an external `.SHX` shape file that isn't embedded in the drawing, are counted and named in their own warning instead of being folded silently into the generic "unrecognized entity" bucket. LINE, POINT, CIRCLE, ARC, SOLID and POLYLINE/VERTEX now apply their own elevation and, via AutoCAD's Arbitrary Axis Algorithm, an arbitrary extrusion (Object Coordinate System) before flattening to the X/Y plan view — previously OCS was ignored entirely, which silently misplaced any entity drawn on a non-default UCS/extrusion. A CIRCLE in a genuinely tilted OCS is drawn as the ellipse it foreshortens into (an exact closed-form 2x2 SVD, not an approximation); a tilted ARC gets the same position correction but stays a circular arc, since this crate's ellipse rendering only draws full ellipses. Every entity's own declared byte length bounds how far it is read or skipped, so a single malformed or unrecognized record can never misalign the rest of the file; every other DWG version, and any `AC1009` file that doesn't validate, still falls back to the previous header-only preview. Written clean-room from the format's public, freely available structural documentation (no DWG-reading code, including LibreDWG, was consulted or copied) — see `src/cad/dwg.rs` for sources.
- Draw NURBS/rational B-spline curves in STEP and IGES CAD drawings instead of leaving them out. STEP now reads the `B_SPLINE_CURVE` + `B_SPLINE_CURVE_WITH_KNOTS` (optionally `RATIONAL_B_SPLINE_CURVE`) complex entity that CAD systems export for every free-form edge, and IGES reads entity 126 (Rational B-Spline Curve); both are evaluated with a new bounded Cox-de Boor curve evaluator (`src/cad/nurbs.rs`) shared by the two readers and tessellated into the isometric wireframe. STEP also gains `ELLIPSE` edges alongside the existing `CIRCLE` support. Previously these edges were silently omitted, so real-world exports from mainstream CAD systems (which rarely use only lines and circular arcs) often rendered as empty or near-empty drawings.

## 2.0.2 - 2026-09-21
- Add a developer reference in English, Japanese and Chinese — every function, option, default, result and error for the command line, Node.js, Python, Rust and the browser viewer, plus how to show pages in a web page — on the project site and as `docs/API.md`, generated from one source.
- Publish a live in-browser viewer demo on the project site (`/viewer/`), built from the WebAssembly package when the site deploys.
- Rewrite the Node.js preview guides (English, Japanese, Chinese) as a step-by-step walkthrough: convert on the server or in Electron's main process, show pages as images, tell people about warnings, add a copy button, and handle uploads and limits safely. Every example was run against the published package.

## 2.0.1 - 2026-09-21
- The READMEs now list where each package is published and where it is installed (npm `node_modules`, pip `site-packages`, `~/.cargo/bin`), and how to check it. The sample guide opens with what the samples are for and how to try one.
- Rewrite the English and Japanese READMEs, and add a Chinese README, for people deciding whether to use the project: what it does, why, how to try it, and its limits, in plain words. The full technical format matrix moves to `docs/FORMATS.md` and `docs/FORMATS.ja.md`.
- Rewrite the npm and PyPI package READMEs around installing, previewing, reading warnings and safety, and describe the packages in the terms people search for. The package home pages now point to the project site.
- Fix the reusable document preview workflow for other repositories: a caller's pull request no longer tries to build docsvg in the caller's repository or look for the actions there. Only this repository's own pull requests build the proposed docsvg.
- The pull request preview now converts documents whose names contain non-ASCII characters (they were silently skipped), passes names starting with `-` safely, and shows file names, formats and warnings literally in the comment so they cannot add links, images or mentions.
- Update the security policy: private vulnerability reporting is enabled, and packages are published only by manually started workflows with short-lived OIDC credentials. The publication check also recognises npm, PyPI, Slack, Google and AI provider keys.

## 2.0.0 - 2026-09-20
- Add a bounded ISO 19115/19139 geographic metadata preview for `.iso19115`, `.iso19115.xml`, `.iso19139`, `.gmd.xml` and content-sniffed XML. Identification title/date/topic, hierarchy/language, CRS codes, geographic bounding boxes and quality/distribution counts render while abstract/lineage text, contact payloads, identifiers and online-resource URLs remain inert; no network retrieval or CRS transformation runs.
- Add a bounded Siemens JT (`.jt`) header preview. The fixed Version and byte-order fields are inspected while TOC/LSG segments, tessellation, Parasolid geometry, PMI and external resources remain inert.
- Add bounded IPC-2581 PCB exchange previews for `.ipc2581`, `.ipc-2581`, and `.cvg`. Content/BOM/ECAD/AVL and board-manufacturing structure counts render while coordinates, toolpaths, inspection payloads, external references and operations remain inert.
- Add bounded Nastran Output2 (`.op2`) binary preflight. Record framing and common table labels are checked within a prefix scan while model geometry, result vectors, external paths and solver operations remain inert.
- Accept Autodesk DWFx (`.dwfx`) through the bounded XPS/OpenXPS fixed-page reader. DWFx is XPS-compatible; internal page relationships and safe vector/image content are rendered while classic DWF payloads and external resources remain inert.
- Add bounded Dassault 3DXML package previews for `.3dxml`. The local Manifest→Root relationship and ProductStructure counts are validated while binary 3DRep tessellation, textures, external files, and viewer automation remain inert.
- Add bounded Microsoft Access ACE/Jet header previews for `.accdb`, `.accde`, `.accdr`, `.mdb`, `.mde`, `.mda`, `.mdt`, `.accdt`, and `.ade`. Engine markers and first-page metadata are checked without opening tables, attachments, VBA/data macros, encryption, or linked databases.
- Add a bounded Rhino/OpenNURBS 3DM header preview for `.3dm`. The stable start marker and bounded header bytes are checked while NURBS/mesh chunks, plug-in data, textures, and external resources remain inert.
- Add a bounded Autodesk DWG header preview for `.dwg`. AC10xx version codes and file size are validated from the fixed header while compressed sections, entities, macros, embedded objects, and external references remain inert.
- Add bounded ZIP-backed Apple iWork Pages/Numbers/Keynote package previews for `.pages`, `.numbers`, and `.key`. Known Index/Metadata/QuickLook markers are rendered without decoding IWA protobuf, formulas, media, scripts, or external links; `.key` is disambiguated from LS-DYNA by ZIP signature.
- Add bounded HDF5 scientific-container, CGNS/HDF5 CFD, and Exodus II previews for `.h5`, `.hdf5`, `.hdf`, `.h5part`, `.cgns`, `.e`, `.exo`, `.ex2`, `.ex2m`, and `.exii`. Signature/user-block offsets and superblock metadata are checked with tiny random reads; datasets, links, filters, external files, and solver operations remain inert.
- Add bounded legacy Visio Compound File Binary previews for `.vsd`, `.vss`, `.vst`, and `.vsw`. The converter validates the CFB container and `VisioDocument` stream, renders stream/storage metadata, and keeps ShapeSheet geometry, macros, OLE payloads, and external links inert.
- Extend OpenDocument Text/Spreadsheet/Presentation/Drawing routing to legacy OpenOffice 1.x SXW/STW/SXG, SXC/STC and SXI/STI/SXD/STD packages, validating their `application/vnd.sun.xml.*` mimetypes through the existing bounded ODF engines.
- Add bounded SAML 2.0 metadata and XACML 3.0 policy previews for identity and access-control documents. Endpoint URLs, certificates, policy values, authorization evaluation and network calls remain inert.
- Add bounded W3C XSL-FO formatting-object previews for `.fo`, `.xslfo` and related XML. Page-sequence, flow, block/table/media structure is shown without running an FO formatter or loading external media.
- Add bounded AbiWord AWML, NeuroML 2 and BioPAX Level 3 previews for Office-compatible, neuroscience and pathway documents. Text, identifiers, parameters, equations, OWL imports, external resources and inference remain inert under XML limits.
- Add bounded EnergyPlus IDF/EPW, RINEX 2–4 GNSS and ACIS SAT ASCII previews for building-energy, surveying and CAD workflows. Object/weather/GNSS/entity values remain inert, with conservative sniffing, limits, fixtures, visual checks and binding coverage.
- Add bounded HL7 CDA, ISO 20022, SBML, CellML and OCEL 2.0 XML previews for clinical documents, financial messages, scientific models and object-centric event logs. Sensitive values, equations, identifiers, URLs and external operations remain inert; fixtures, visual checks and binding coverage are included.
- Add bounded XPDL, ONIX for Books and OAI-PMH XML previews for workflow exchange, publishing metadata and digital-archive responses. IDs, private values, URLs, scripts, HTTP harvesting and external resources remain inert under XML limits, with fixtures, visual checks and binding coverage.
- Add bounded TMX 1.4b, TBX/MARTIF, gbXML, FHIR XML and Adobe IDML previews. Translation/terminology text, clinical values, building geometry/schedules, InDesign IDs/payloads and external resources remain inert; XML and ZIP limits, fixtures, visual checks and Node/Python binding coverage are included.
- Add XJDF 2.x job-ticket previews via `.xjdf` using the bounded CIP4 JDF structure reader. Product/resource metadata renders without running device commands, workflow operations or URL/file links.
- Add a bounded CIP4 JDF/JMF job-ticket preview for `.jdf`, `.jdf.xml`, `.jmf` and content-sniffed XML. Nodes, resources, processes, products, devices, media, layouts, run lists, audits and file/URL links render while device commands, workflow execution, credentials, URLs and linked files remain inert.
- Add a bounded B2MML/ISA-95 manufacturing XML preview for `.b2mml`, `.b2mml.xml` and content-sniffed XML. Schedule/performance/request/response, product/material/equipment/personnel/process/capability/maintenance/transaction and external-reference counts render while operations, values, credentials, URLs and external resources remain inert.
- Add a bounded QIF inspection-data preview for `.qif`, `.qif.xml` and content-sniffed XML. Product, inspection plan/result, feature, characteristic, datum, traceability and external-file-reference counts render while measured values, tolerances, IDs, URLs and external CAD/inspection payloads remain inert.
- Add a bounded ISO 10303-28 STEP-XML/AP242 metadata preview for `.stepxml`, `.stpx`, `.step.xml` and content-sniffed XML. Product, assembly, representation, geometry, property and external-reference counts render while EXPRESS evaluation, schema fetches, IDs, URLs and referenced CAD geometry remain inert.
- Add a bounded Siemens PLMXML product-structure preview for `.plmxml`, `.plm.xml` and content-sniffed XML. ProductDef/Part/Structure/Instance/Representation/ConstructionGeometry/Attribute metadata and external-reference counts render while XT/Parasolid geometry, IDs, URLs and external files remain inert.
- Add ISO/ASTM 52915 AMF 1.2 mesh previews for `.amf` and content-sniffed XML. Object-local vertices and volume triangles reuse the shaded OBJ renderer while units, materials, textures, color, lattice, slices and external references remain inert under XML and mesh limits.
- Add an inert OpenSCAD source preview for `.scad` and content-sniffed CAD scripts. Module/function declarations, primitives, transforms, booleans, assignments and import/use/include references render as bounded metadata; no geometry, expression, loop, library or external file is executed.
- Add bounded AASX support for `.aasx` packages and content-sniffed OPC archives. Root/origin relationships locate AAS XML/JSON specification parts; shell, submodel, concept, element and supplementary-file counts render while CAD/manual payloads, identifiers, values, URLs, signatures and encryption material remain inert under ZIP/XML/JSON limits.
- Add bounded Flat OPC support for `.flatopc`, `.fopc`, `.flatopc.xml` and content-sniffed single-XML Office packages. Validated XML/base64 parts are reconstructed in memory and rendered through the existing DOCX/XLSX/PPTX engines; macros, external relationships, URLs and filesystem extraction remain inert under input, part, expanded-byte and XML-event limits.
- Add a bounded buildingSMART BIM Collaboration Format (BCFZIP/BCF-XML) preview for `.bcfzip` archives and content-sniffed packages. Project/topic metadata, topic title/status/priority and comment/viewpoint/document-reference/component counts render as inert rows; snapshots, IFC/model payloads, document URLs, GUID payloads and collaboration actions remain omitted, with archive/XML limits and no external dereference.
- Add a bounded RDF/XML graph preview for `.rdf`/`.rdf.xml` and content-sniffed RDF. Predicate/literal rows plus subject, blank-node and IRI counts render while subject/resource URLs, nested XML literals and vocabularies remain omitted; no URI dereference, inference, schema fetch or SPARQL runs.
- Add a bounded Chemical Markup Language (CML) XML preview for `.cml`/`.cml.xml` and content-sniffed XML. Molecule names, atom/bond counts, element distributions, reactions, spectra and properties render as inert rows; coordinates, dictionaries, URLs, property payloads and chemical calculations remain omitted.
- Add bounded Microsoft Excel 2003 XML SpreadsheetML previews for `.spreadsheetml`/`.xmlss`/`.excel.xml` and content-sniffed XML. Worksheet/Table/Row/Cell/Data values render with formula-presence markers; styles, macros, named ranges, external links, drawings and formula recalculation remain inert.
- Add a bounded Adobe XDP/XFA XML Data Package preview for `.xdp`/`.xdp.xml` and content-sniffed XML. Packet, template/dataset/config/PDF counts, XFA field names and script/event/submit/reference counts render as inert rows; field values, embedded packets, URLs and private payloads remain omitted, and XFA logic/layout/recalculation never runs.
- Add a bounded Adobe XMP/ISO 16684-1 metadata preview for `.xmp`/`.xmp.xml` and content-sniffed packets. Descriptive title/creator/subject/date/producer/tool/format properties and packet counts render as inert rows; identifiers, rights/description payloads, thumbnails, URLs, private schemas and binary data remain omitted, with no schema or external-resource access.
- Add a bounded MathML 3 presentation preview for `.mathml`/`.mathml.xml`/`.mml` and content-sniffed XML. Formula text and token/fraction/script/root/fence/table counts render as inert rows; annotations, embedded XML/images, URLs and scripts stay omitted, with no symbolic algebra or active content.
- Add a bounded LandXML 1.2 civil/survey exchange preview for `.landxml`/`.landxml.xml` and content-sniffed XML. Surface names/TIN point-face counts, alignment segment counts, survey points, parcels and pipe networks render as inert rows; coordinates, boundary/design payloads, external schema URLs and references stay omitted, with no terrain calculation or stationing.
- Add a bounded ISO 19444/Adobe XML Forms Data Format (XFDF) preview for `.xfdf`/`.xfdf.xml` and content-sniffed XML. Field/value hierarchy, sensitive-field masking, rich-text and annotation counts, and PDF target counts render as inert rows; actions, JavaScript, PDF references, appearance payloads and URLs remain omitted, with no form submission or PDF rendering.
- Add a bounded Adobe Forms Data Format (FDF) preview for `.fdf` and content-sniffed inputs. Field hierarchy, types, safe values, password masking, choice options, and action/attachment counts render as inert rows; JavaScript, submit/launch actions, file specifications, embedded files, and external URLs stay omitted, with no form submission or PDF page rendering.
- Add a bounded XBRL 2.1 instance preview for `.xbrl`/`.xbrl.xml`/`.xbrli` and content-sniffed XML. Facts, contexts, units, periods, precision, dimensions and structural references render as inert rows while entity identifiers, taxonomy/linkbase payloads and URLs remain omitted; formula evaluation, validation, schema fetches and network operations never run.
- Add a bounded OASIS Universal Business Language (UBL) 2.x preview for `.ubl`/`.ubl.xml` and content-sniffed XML. Invoice, Order, CreditNote, DebitNote, Catalogue, transport and related roots expose version/date/currency and structural line/party/payment/tax/total/reference counts while party payloads, identifiers, amounts, attachments and URLs remain inert; no schema fetch or business operation runs.
- Add bounded DICOM Structured Report previews for SR SOP Classes (Basic Text, Enhanced, Comprehensive, Comprehensive 3D, Extensible, CAD, dose, agent and related reports). Content Sequence TEXT/NUM/CODE/CONTAINER items, coded concepts, units and relationships render as inert tables; referenced objects, UIDs and patient/study attributes stay omitted, and the warning states that SR content may contain PHI and is not de-identification.

- Add a bounded CloudEvents JSON 1.0 preview for single event objects and JSON Batch arrays. The converter validates required envelope attributes, renders type/id/source-host/context and data type/size metadata, masks source query values, and omits payloads, dataschema and extension values without resolving URIs or invoking brokers, handlers or network resources. CloudEvents JSON is recognized by dedicated `.cloudevent*`/`.ce.json` aliases and content sniffing; limits cover 64 MiB input, depth 100, 300,000 JSON values, 100,000 events and 2 MiB strings.
- Add a bounded HL7 FHIR R4 JSON preview for individual resources and Bundle entries. The converter validates the `resourceType` envelope, summarizes resource IDs, status/type, profile counts and structure, and omits clinical values, Narrative XHTML, identifiers, names, coded displays, extension values and references without terminology lookup, validation, URL access or clinical operations. Dedicated `.fhir*` aliases and content sniffing use 64 MiB input, depth 100, 300,000 JSON values, 100,000 resources and 2 MiB strings limits.
- Add a bounded Apache Avro JSON schema/protocol preview for `.avsc`, `.avpr`, `.avro.json` and `.avro-schema.json` inputs. Record, field, union, enum, fixed, array, map and protocol message paths are summarized by type; defaults, docs, aliases, logical values, imports, data, code generation and RPC execution remain inert under input/depth/value/row/string limits.
- Add a bounded OpenTelemetry OTLP JSON preview for trace, metric, log and profile signal envelopes. Resource/scope counts, service names and event/link/data-point summaries are rendered while attribute values, bodies, IDs, exemplars, links, schema URLs and endpoints remain omitted; no collector/exporter/network operation runs. Dedicated `.otlp*` aliases and content sniffing use input/depth/value/row/string limits.
- Add a bounded OCEL 2.0 JSON preview for object-centric event logs. Event/object type definitions, event/object IDs and relationship counts are rendered while attribute values, qualifiers, URLs and process-mining operations remain inert. Dedicated `.jsonocel`/`.ocel.json` aliases and content sniffing use input/depth/value/node/row/string limits.
- Add a bounded WSDL 1.1/2.0 service-description preview. Service, port, binding, portType/interface, operation, message, import/include and embedded-schema metadata are rendered while endpoint addresses, external schemas, credentials, payloads and SOAP/HTTP execution remain inert.
- Add a bounded OPML 1.0/2.0 outline preview. Version/title/date metadata and hierarchical outline/type/depth/feed counts are rendered while feed URLs, owner addresses, extension values and linked-resource execution remain inert.
- Add a bounded RSS 2.0 / Atom 1.0 feed preview for `.rss`, `.atom` and `.georss` inputs without GeoRSS geometry. Channel/feed and item/entry title/date plus structural link/author/content/enclosure counts render while links, payloads, enclosures and network refresh remain inert.
- Add a bounded Apple Property List preview for XML `.plist`/`.plist.xml` and binary `bplist00` files. XML key paths/types and binary trailer/offset/object-marker metadata render while URL/secret values, data payloads, external entities and application execution remain inert.
- Add a bounded TEI P5 scholarly-text preview for `.tei`/`.tei.xml` and namespaced content-sniffed XML. `teiHeader` title/author/date and common text/body divisions, headings, paragraphs, notes, lists, figures and table counts render while targets, facsimiles, scripts and external resources remain inert.
- Add a bounded ALTO OCR/layout preview for `.alto`/`.alto.xml` and content-sniffed ALTO XML. Page, TextLine, String content and validated word-confidence metadata render while source-image paths, styles, alternatives and external resources remain inert.
- Add a bounded METS archive-structure preview for `.mets`/`.mets.xml` and content-sniffed METS XML. File sections/groups, MIME/size metadata, structMap divisions and fptr/mptr counts render while location references, payloads and linked ALTO/image files remain inert.
- Add a bounded MARCXML preview for `.marcxml`/`.marc.xml` and content-sniffed collections/records. Leader, controlfield, datafield and subfield metadata render while 856/URL values, catalog references and external resources remain inert.
- Add a bounded MODS 3.x preview for `.mods`/`.mods.xml` and content-sniffed collections/records. Titles, names, origin, genre, subject, identifier and location structure render while authority/location URLs, notes and external resources remain inert.
- Add a bounded MARC21 ISO 2709 preview for `.marc`/`.iso2709` and content-sniffed binary records. Leader, directory, control/data field and subfield metadata render while 856/URL values and catalog services remain inert; `.mrc` remains the microscopy-volume route.
- Add a bounded PREMIS 2.x/3.0 preservation-metadata preview for `.premis`/`.premis.xml` and content-sniffed XML. Object, Event, Agent and Rights entity metadata render while checksums, URIs, rights text and preservation actions remain inert.
- Add a bounded IIIF Presentation 2.1/3.0 Manifest/Collection preview for `.iiif.json`, `.iiif-manifest.json`, `.manifest.json` and content-sniffed JSON. Canvas labels/dimensions, painted-image and annotation counts, ranges and metadata counts render while IDs, image services and annotation bodies remain inert.
- Add a bounded EAD2/EAD3 finding-aid preview for `.ead`/`.ead.xml` and content-sniffed XML. Repository/title metadata and nested archival component levels/titles/dates render while digital-object URLs, scope payloads and external resources remain inert.
- Add a bounded EAC-CPF authority preview for `.eac-cpf`/`.eac-cpf.xml`/`.eac` and content-sniffed XML. Entity type, identity names, dates/descriptions and CPF/resource/function relation counts render while authority URIs, biographies and relation targets remain inert.
- Add a bounded Dublin Core XML preview for `.dc.xml`, `.dublin.xml`, `.dublin-core.xml` and content-sniffed metadata. DCMI title/creator/subject/publisher/date/type/format/language fields render while identifier/relation/rights/description payloads and URLs remain inert.
- Add a bounded S1000D Data Module preview for `.s1000d`, `.dmodule`, `.dmodule.xml` and content-sniffed XML. DMC/title/issue/security metadata and common technical text render while DM/ICN references, graphics and publication assembly remain inert.
- Add a bounded OASIS TAXII 2.1 JSON preview for envelopes, manifests, collections, discovery, status and error resources. IDs/counts and capability metadata are rendered while STIX payloads, URLs, authorization data and endpoints remain inert; no HTTP client or TAXII operation runs.
- Add a bounded OASIS STIX 2.1 JSON preview for cyber-threat bundles and objects. Type/id, timestamps, labels and relationship/reference counts are rendered while indicator patterns, descriptions, hashes, URLs, marking content and custom properties remain inert.
- Add a bounded OGC CityJSON 1.x/2.0 preview for compact 3D city models. CityObject type/geometry/LoD counts, shared vertex and boundary-index counts, and transform/metadata presence are rendered while coordinates, semantics, textures, attributes, extensions and external resources remain inert under JSON limits.
- Add a bounded ASAM OpenLABEL 1.0 JSON preview for multi-sensor annotations. Collection counts for objects, actions, events, contexts, relations, frames and streams are rendered with nested object-data summaries while sensor payloads, coordinates, values, ontology URLs and external resources remain inert under bounded JSON limits.
- Add a bounded ASAM OpenSCENARIO XML preview for `.xosc` scenarios. FileHeader, entities and Storyboard hierarchy plus parameter/catalog/RoadNetwork counts are rendered; catalog files, road files, controllers, expressions, triggers and simulator behavior remain inert under bounded XML limits.
- Add a bounded ASAM OpenCRG header preview for `.crg` road-surface files. Clear-text section names and line counts are rendered while ASCII/binary road samples and file references remain inert; no tire, vehicle or surface evaluation runs.
- Add a bounded ASAM OpenDRIVE preview for `.xodr` road networks. Line and constant-curvature arc reference-line geometry is normalized from local metres into a planar map; road/junction counts are reported while spiral/poly3/paramPoly3, lanes, profiles, signals, objects, links and simulator behavior remain inert.
- Add a bounded JSON:API 1.1 preview for primary and included resources. Type/id identifiers, status metadata and attribute/relationship counts are rendered while values, linkage payloads, meta/error details and link URLs remain inert; no API endpoint or operation runs. Dedicated `.jsonapi` aliases and content sniffing use input/depth/value/resource/row/string limits.

- Position a tiling pattern's own SVG `<pattern>` element at its `/BBox`'s real origin instead of leaving it hardcoded at `(0, 0)`. A tiling pattern's own content stream draws in absolute BBox-space coordinates (PDF32000 8.7.3.1), which need not start at the origin at all -- a producer is free to declare e.g. `/BBox [35.4 396.6 287.4 588]`, matching wherever on the page the pattern's own designer happened to lay it out. The generated `<pattern>` element's own `x`/`y` set where that content lands within the tile it repeats, so leaving it at `(0, 0)` regardless shifted every BBox with a nonzero origin clean out of its own tile: content clipped correctly to the BBox rectangle, drawn at its own real coordinates, but that rectangle no longer overlapped the pattern's assumed `[0, width] x [0, height]` viewport at all. Found by converting pdf.js's own `22060_A1_01_Plans.pdf`, a fire-safety floor plan whose evacuation-route highlight bands -- all filled with tiling patterns whose `/BBox` origins run into the thousands -- rendered as wrong-sized fragments scattered near the top of the page instead of poppler's correctly sized and positioned bands (sampled pixel difference against poppler drops from 26.2% to 19.8%; a separate, unrelated gap in this file's underlying floor-plan detail remains).
- Stop treating a CID-keyed CFF glyph that resolves to GID 0 as "not found." A CID-keyed CFF's charset conventionally names GID 0 `.notdef`, but nothing in the CFF format actually requires its charstring to be empty -- and a real-world subsetted TeX Computer Modern font (`CMR9`) stores a genuine, fully-drawn "ff" ligature there while its charset still labels it `.notdef` as a formality. The font parser's own reverse CID-to-GID map already signals "this CID has no entry at all" with a dedicated `0xFFFF` sentinel, so treating a resolved GID of exactly 0 as equally invalid discarded a real, drawable glyph outright. Found by converting pdf.js's own `issue11718_reduced.pdf`, whose caption "A different method" rendered without any "ff" ligature at all, falling back to incorrect editable placeholder text for the whole line instead of the real glyph outlines poppler draws.
- Chunk `Identity-H`/`-V` character codes by two bytes when a `CIDFontType0` descendant is backed by a plain Type1 program, instead of iterating one byte at a time regardless. A CIDFontType0 descendant is only ever supposed to carry a bare CFF (`CIDFontType0C`) or OpenType program (PDF32000 Table 126), but some producers embed a plain Type1 program through the simple-font-only `/FontFile` key instead -- and `Identity-H`/`-V` still means each character code is two bytes regardless of what program type backs it (PDF32000 9.7.5.2). This is the same class of bug already fixed for the bare-CFF case in `outline_cff`, just never applied to this sibling Type1 code path: every high zero byte of a CID under 256 showed up as its own spurious one-byte lookup, and the real low byte could then never resolve either once its position shifted by one. Found by converting pdf.js's own `issue11740_reduced.pdf`, whose embedded Cyrillic font (its own built-in Type1 `/Encoding` names each CID's glyph directly by that same numeric code) rendered its "Оглавление" heading as incorrect editable placeholder text instead of real glyph outlines.
- Strip PFB (Printer Font Binary) segment framing from an embedded Type1 font program before parsing it, when present. PDF32000 9.9's own `/FontFile` format is a plain concatenation of a Type1 font's cleartext header, its eexec-encrypted binary portion, and a zero-padding trailer -- no segment framing at all -- but some producers instead embed the raw PFB container format verbatim. Its interleaved 6-byte `0x80 <type> <length>` segment headers land squarely inside the encrypted portion, and since eexec decryption is a running cipher whose state carries across the whole ciphertext, one such header corrupts every glyph's `CharStrings` entry from that point on into garbage -- parsing found none of them at all. Found by converting pdf.js's own `issue14462_reduced.pdf`, whose embedded DejaVuSansMono subset rendered as incorrect editable placeholder text instead of the real "Issue 14462" glyph outlines.
- Resolve a CID-keyed CFF glyph embedded as a full OpenType wrapper (`/FontFile3 /Subtype /OpenType`) through the CFF table's own `charset`, instead of treating the raw CID as a glyph index. That shortcut is correct for a CIDFontType2 (TrueType-based) CID font's raw code under Identity-H/V, but never for a CIDFontType0 (CFF-keyed) one: a CID-keyed CFF's own `charset` maps GID to CID through a font-specific, non-identity table, and an OpenType-wrapped CID-keyed CFF program parses successfully as an ordinary font, so it never reached the existing bare-CIDFontType0C code path that already resolves this correctly. Found by converting pdf.js's own `Embedded_font.pdf`, whose single glyph -- CID 0xA911 -- lives at GID 1 in its two-glyph subset; looking it up as GID 0xA911 directly failed outright, falling back to incorrect editable placeholder text instead of the real glyph outline. The fix detects the sfnt's own `CFF ` table and reuses the CFF parser's existing CID-to-GID reverse map to resolve the correct glyph before handing it to the OpenType outline renderer.
- Decode an `ASCIIHexDecode`-filtered page content stream ourselves instead of relying on lopdf's own decoder, which implements only `FlateDecode`/`LZWDecode`/`ASCII85Decode` for stream content and, by its own documented design, falls back to the RAW (still hex-encoded) bytes on any other filter rather than reporting an error. Fed straight into the content-operator tokenizer, that literal hex-digit text produces garbage tokens -- a spurious bare `A` operator among them -- and the page's real drawing commands are lost entirely. Found by converting pdf.js's own `asciihexdecode.pdf`, whose one line of "Hello world" text rendered as a totally blank page. A new wrapper enumerates a page's content streams directly and decodes a leading `ASCIIHexDecode` layer by hand before handing whatever filters remain to lopdf, preserving lopdf's own lenient raw-bytes fallback for any filter it still cannot decode at all (a real, if unusual, case some corpus files rely on for content using a filter like `JBIG2Decode` that was never meant to be parsed as text in the first place).
- Consult a CFF glyph's own deprecated "seac" composition (Adobe TN#5177 Appendix C): a Type 1/2 charstring can compose an accented letter from two other named glyphs of the same font -- by StandardEncoding code, not by this font's own charset SID or the PDF's `/Differences` encoding -- as `adx ady bchar achar endchar`, instead of drawing its own outline at all. The underlying `stet-fonts` crate's own charstring interpreter already parses this into a `seac` field on its result, but `outline_cff` never consulted it, so a glyph built this way -- its own charstring being pure composition, with no moveto or lineto operators of its own -- produced no outline whatsoever. Found by converting pdf.js's own `endchar.pdf`, named for this exact charstring operator: a single É built this way rendered as a totally blank page, 28.0% of sampled pixels differing from poppler's own rendering, the single worst result across a fresh visual-diff sweep of the whole corpus.
- Draw a Link annotation's own fallback border (from its `/Border` or `/BS` width, and its `/C` colour) when it has no `/AP` appearance stream of its own. PDF32000 12.5.4 leaves this entirely to the reader's discretion, and poppler draws one whenever a document explicitly declares both a positive border width and a colour -- which this now mirrors, narrowly: the overwhelmingly common case is a Link with neither set at all (most real documents rely on the *absence* of a visible border here), so a Link with no width or no colour still draws nothing, and a Link's own `/AP`, on the rare occasion it has one, is still never drawn either way, preserving the deliberate existing choice that a Link is conventionally just an invisible active area. Found by converting pdf.js's own `file_url_link.pdf`, whose link text is meant to sit inside a visible green border box -- poppler draws it, this converter drew nothing at all.
- Recognize an inline image's own `/IM` (`/ImageMask`) flag. Every inline `BI...ID...EI` image is fully decoded up front by `InlineImageSpec` into a plain `Stream` carrying only `Width`/`Height`/`BitsPerComponent`/`ColorSpace`/`Interpolate` -- with no field to parse `/IM` into at all, an inline stencil mask was never recognized as one, and rendered as an ordinary grayscale image in its own raw black-and-white sample values instead of being stenciled through the current fill color. Found by converting pdf.js's own `images_1bit_grayscale.pdf`, a test grid of eight different 1-bit image encodings: its "Inline Image Mask" box -- the one case, among all eight, using both `BI` syntax and `/IM true` together -- rendered in plain black instead of the magenta the page sets immediately beforehand, the only one of the eight that differed from poppler's own rendering.
- Resolve an Indexed color space's palette entries through the same conversion used for painted colors, instead of assuming they are already raw sRGB or CMYK bytes whenever they happened to have 3 or 4 components. An Indexed space's base can legally be anything -- Lab, CalGray, CalRGB, Separation, DeviceN or ICCBased, not only DeviceRGB/Gray/CMYK -- and a 3-component Lab base is common enough to collide with the old "3 components means RGB" assumption; Lab's own components additionally need denormalizing from a raw `0..255` palette byte into their own much wider native scale (L* in `[0, 100]`, a*/b* in the space's own `/Range`) before conversion, not a flat divide by 255. Found by converting pdf.js's own `issue10339_reduced.pdf`, a Lab-indexed image that rendered as a muddy brown instead of the intended blue (68.9% of sampled pixels differed from poppler's own rendering; only the color was wrong, not the shape, since the palette lookup itself -- and this file's own `/Decode`-array palette-index inversion -- were otherwise already correct).
- Dereference a page's own `/MediaBox`, `/CropBox` and `/Rotate` before checking their type, the same class of fix as the `/OCProperties` dereferencing gaps elsewhere in this changelog. Any of these can legally be an indirect reference rather than an inline value, and reading one with a non-dereferencing dictionary lookup before checking its type silently treated it as absent, falling all the way back to this converter's own default of a US Letter page (612x792pt) regardless of the PDF's real page size. Found by converting pdf.js's own `bug852992_reduced.pdf`, whose real, much smaller and negative-origin 540x190pt page -- itself sharing one indirect array object as the `/MediaBox` and as several unrelated Form XObjects' and shadings' own `/BBox`, which is what exposed the gap -- squeezed all of its actual content into a small corner of a mostly blank default-sized canvas (77.1% of sampled pixels differed from poppler's own rendering; the page is pixel-identical to poppler's own rendering with this fix).
- Resample a PDF image and its own soft mask to a common resolution instead of dropping the mask outright whenever their pixel dimensions differ. Per spec each is independently mapped onto the same unit image square, so they need not share a native resolution at all -- and in one common real-world pattern they deliberately do not: a solid, uniformly-coloured base image at a tiny resolution (as small as 1x1) paired with a full-resolution soft mask that alone carries the shape of whatever is actually being drawn. Found by converting pdf.js's own `chrome-text-selection-markedContent.pdf`, whose text-selection highlights are exported by Chrome exactly this way -- a 2x2 solid-colour base image, and a soft mask sized to the actual glyph run that carries the highlight's real, per-glyph shape entirely in its alpha channel; discarding the mask on a size mismatch, as a same-dimensions check did, left every highlight either solid or altogether missing rather than glyph-shaped. Downsampling the mask down to the base image's own tiny resolution would have been just as wrong, throwing away exactly the detail the mask exists to carry -- so the two are now nearest-neighbor resampled up to their larger common resolution before being combined into a single RGBA raster.
- Decode a Type3 glyph's own CharProc, a Form XObject, a tiling pattern and a soft mask's group content through the same inline-image-aware content-stream scanner the top-level page already used, instead of handing them straight to `lopdf::content::Content::decode`. That generic parser has no notion of `BI...ID...EI` inline-image syntax at all -- it is not equipped to skip over the image's own raw binary sample data, which routinely contains byte sequences that look like other PDF tokens -- so any inline image nested in one of these silently corrupted parsing of that entire content stream, discarding not just the image but every operator after it. Found by converting pdf.js's own `bug1245391_reduced.pdf`: a Type3 glyph's CharProc drew an inline image bitmap as part of the glyph shape, and the corrupted parse turned the file's only content into a 57-byte page that drew nothing at all. Fixing this in turn exposed a second, previously unreachable defect in the scanner itself: it looks for a literal `EI` token to end the image data, requiring the byte immediately before it to be a PDF delimiter (to avoid matching a stray "EI" inside binary noise) -- but the PDF spec recommends, and does not require, a white-space separator between an inline image's last data byte and `EI`, and real-world encoders often omit it. An *unfiltered* image's own dictionary (width, height, bits per component, colour space) determines its exact row-padded byte length regardless, so the scanner now checks that exact position for `EI` first, before falling back to the generic scan. Found by the same corpus run once the CharProc/Form/pattern/mask fix above started routing many more real-world inline images through this code path for the first time: `bug1513120_reduced.pdf` (a Type3 font whose glyph bitmaps are all built this way) and `issue10388_reduced.pdf` (a single 16x17 stencil mask) both failed outright, the latter aborting the whole page's conversion rather than merely warning.
- Draw a filled rectangle with zero width or zero height as a thin stroke instead of a literal zero-area (and so invisible) fill. Real-world PDFs -- CAD exports, ruled grids, table borders -- commonly use exactly this to draw a hairline instead of stroking it, relying on every mainstream viewer's rasterizer to give a degenerate fill a sliver of coverage; a vector SVG output has no such rasterizer convention to lean on; a truly zero-area path is simply invisible. Found by converting pdf.js's own `issue4260_reduced.pdf`, a page built entirely from zero-height and zero-width filled rectangles forming a ruled grid, which rendered as a totally blank box. The conversion is deliberately narrow: only a path that is nothing but a single `re` rectangle, filled but not stroked, with exactly one of its two dimensions exactly zero, is affected -- an ordinary rect, a zero-area point, or a path that already carries its own stroke is left alone.

- Map an annotation appearance's `/BBox` to its `/Rect` only after first applying the appearance's own `/Matrix` to `/BBox`'s corners, per PDF32000 12.5.5's algorithm. `/Matrix` commonly carries a real translation -- it is exactly what lets a PDF producer normalize an appearance's content near the origin while declaring `/BBox` and `/Rect` equal -- and that translation must be cancelled by the BBox-to-Rect mapping, not left in the combined transform. Mapping straight from `/BBox`'s own (untransformed) values instead left `/Matrix`'s translation in place on top of it, doubling the offset and drawing the whole appearance somewhere other than inside `/Rect`. Found by converting pdf.js's own `file_pdfjs_test.pdf`, whose "this is a text annotation" FreeText annotation rendered at the bottom of the page instead of just below the title, where poppler correctly draws it.

- Fix a gap in the `/OCProperties` dereferencing fix above: an OCMD's own `/OCGs` entry can legally name a single optional content group directly -- a bare indirect reference, not wrapped in an array -- rather than an array of them (PDF32000 8.11.2.3). Dereferencing `/OCGs` before checking whether the result was an array correctly unwrapped an indirectly-referenced *array*, but for this single-OCG form it resolved straight through to the OCG's own dictionary, discarding the object ID the hidden-group lookup needs to work at all -- so a Form XObject's own `/OC` entry (as opposed to a content-stream `BDC /OC` wrapper) naming an OCMD with a bare single OCG reference always rendered as visible, regardless of that OCG's real default state. Found by converting pdf.js's own `issue12007_reduced.pdf`: unrelated source-material images (a pet photo, an image editor's own UI chrome) meant to stay off by default were rendering on top of the one line of text the page was supposed to show.

- Stop refusing to outline a symbolic simple TrueType glyph just because its character code is missing from the font's `/ToUnicode` CMap. A symbolic font (no `/Encoding`, symbolic by the PDF spec's own default) resolves glyphs through its own embedded cmap by raw character code, never through Unicode, so a missing `/ToUnicode` entry says nothing about whether the glyph exists -- but a missing entry there was still treated as "this code cannot be resolved at all," aborting before the font's own cmap, tried by raw code first for exactly this reason, ever got to run. Found by converting pdf.js's own `issue2017r.pdf`, a font specimen sheet whose symbolic embedded TrueType font fell back to incorrect placeholder text. This mirrors the CFF/Type1 fix elsewhere in this changelog, applied to the remaining code path that still had the same unconditional bailout.

- Dereference `/OCProperties /D /OFF`, `/ON`, the top-level `/OCGs` array, and an OCMD's own `/OCGs` member list before checking whether each is an array. Any of these can just as legally be an indirect reference to an array as an inline one, and reading one with a non-dereferencing dictionary lookup before checking its type silently treated the reference as absent (via a swallowed `.ok()`) rather than following it -- hiding nothing at all, since an empty `/OFF` set means every optional content group renders. Found not by a warning -- there wasn't one -- but by the same systematic visual diff against poppler used to find the `CalGray` defect above: pdf.js's own `issue269_2.pdf`, a 49-layer optional-content test file whose default configuration is meant to show only one layer combination (a photograph tiled into half of a checkerboard), showed 28.4% of sampled pixels differing from poppler's reference. Every one of the file's other 48 layers -- solid-color variants, inverted variants, alternate photos -- was rendering on top of the correct one, because its own `/OFF` array happens to be stored as its own indirect object rather than inline. `issue269_2.pdf`'s diff against poppler drops from 28.4% to 6.2%.
- Gamma-encode `CalGray` into sRGB instead of returning its raw luminance directly. `CalGray`'s `A^Gamma` is a linear luminance the color space's CIE `WhitePoint` scales, not a value already fit to use as an sRGB pixel; returning it as `[A^Gamma, A^Gamma, A^Gamma]` skipped the sRGB gamma-encoding curve that `CalRGB` and `Lab` already apply via this converter's own `xyz_to_srgb` helper, rendering every midtone far too dark. Found not by a warning -- there wasn't one -- but by a systematic visual diff against poppler's own rendering across the entire pdf.js test corpus: pdf.js's own `calgray.pdf` stood out with 73% of sampled pixels differing from poppler's reference, far more than any other file, while its layout, text and structure matched exactly. The direct fix -- routing `CalGray` through the same `xyz_to_srgb` matrix `CalRGB`/`Lab` use -- corrected the lightness but introduced a visible color tint, because that matrix assumes a D65 white point and this file declares an unusual equal-energy `[1 1 1]` one; `CalGray` is inherently achromatic by construction (X, Y and Z are always the same white-point-scaled luminance), so the correct fix gamma-encodes the luminance directly into a neutral `R=G=B` instead, sidestepping any white-point mismatch entirely. `calgray.pdf`'s diff against poppler drops from 73% to under 2%.
- Resolve a Type0 font's CID-keyed CFF glyphs by two-byte CID under Identity-H/V, instead of one byte at a time. A bare CIDFontType0C program has two-byte character codes under Identity-H/V, but `outline_cff` iterated the raw bytes one at a time regardless of font kind -- so every high byte of a two-byte CID under 256 produced its own spurious, always-failing "code 0" lookup, and even the low byte could never resolve through the name-/Unicode-based lookup meant for simple fonts, since a CID-keyed CFF's own charset maps GID to CID rather than to a name. Found by converting six different pdf.js corpus files that all shared this exact recurring warning (`bug1937438_mml_from_latex.pdf`, `bug1947248_text.pdf`, `cid_cff.pdf`, `doc_3_3_pages.pdf`, `highlight.pdf`, `issue18408_reduced.pdf`), traced to their common shape: `/Subtype /CIDFontType0C` under `/Encoding /Identity-H`. `outline_cff` now chunks its input by two bytes and resolves the glyph directly through the CFF parser's own CID-to-GID reverse map when the font is Identity-keyed, the same pattern the TrueType/CIDFontType2 fix above already uses. All six files convert cleanly with this fix; no other file in the corpus changed.
- Fall back to a TrueType font's own `post` table when it has no `cmap` table at all to search. A simple, non-symbolic font can legally ship with no `cmap` table -- unremarkable for one subsetted to be looked up only through the PDF's own `/Differences` (or base) encoding, since nothing about that requires a cmap. `outline_path` only ever tried Unicode-character-based cmap/charmap lookups, though, which had nothing to search in that case and failed outright for every glyph, falling back to incorrect placeholder text for the whole font. Found by converting pdf.js's own `TrueType_without_cmap.pdf`, whose embedded "Masis" font has no `cmap` table but does carry a version-2.0 `post` table with real glyph names. Glyph selection now falls back to looking the PDF encoding's glyph name up in the font's own `post` table, the same way CFF and Type1 fonts already resolve a glyph through their own name tables regardless of cmap.
- Resolve a Type0 font's Identity-H/V glyphs directly by CID instead of through the embedded font's own cmap. Under Identity-H/V the raw character code already *is* the CID (PDF32000 9.7.5.2), and with no `/CIDToGIDMap` the CID *is* the GID directly -- no cmap lookup involved at all. This converter instead routed every CID font through the same Unicode-character-based cmap lookup used for simple fonts, which fails whenever a subsetted CID font's embedded cmap lacks full Unicode coverage: a common case, since a subsetter is free to ship a minimal or absent cmap once glyph selection no longer depends on it. Found by converting pdf.js's own `basicapi.pdf`, whose subsetted embedded DejaVuSans and DejaVuSans-Bold fonts failed on perfectly ordinary ASCII letters ('C', 'P') and fell back to incorrect placeholder text; visually comparing the rendered page against poppler's own output, before the fix, showed the difference directly. `FontDecoder` now resolves an Identity-H/V font's glyph via its own `/CIDToGIDMap` (or the `/Identity` default) directly, bypassing cmap -- and, incidentally, making this path immune to `/ToUnicode` gaps the same way the CFF/Type1 fix below already is.
- Decode a PDF image stream's leading compression filters before handing it to its own image codec. Found by converting pdf.js's own `comments.pdf` test file, whose `Im0` image sets `/Filter [/FlateDecode /DCTDecode]` -- Flate wrapped around a JPEG purely for a little extra compression, which is legal and not unusual. The DCTDecode (and CCITTFaxDecode, JPXDecode) code paths read the stream's raw bytes directly on the assumption that they already were that codec's own data, true only when DCTDecode is the sole filter; with an outer FlateDecode present, those bytes were still zlib-compressed, and handing them to the JPEG decoder failed immediately with "first two bytes are not an SOI marker," skipping the image (and, for the JPEG-passthrough path, would have silently embedded corrupt image data instead of erroring at all). A new `image_codec_content` helper now decodes every filter preceding a stream's own final image-codec filter first, leaving only that codec's bytes for its decoder.
- Stop refusing to outline a CFF or Type1 glyph just because its character code is missing from the font's `/ToUnicode` CMap. Found by converting pdf.js's own `cid_cff.pdf`, `font_ascent_descent.pdf` and `comments.pdf` test files: a math or symbol font (TeX's CMSY6/7/8/9, CMMI9, or a Ghostscript-generated NimbusRomNo9L carrying ligatures) routinely has codes with a real, drawable glyph but no sensible Unicode equivalent, so a `/ToUnicode` CMap simply omits them -- and a missing entry there was treated as "this code cannot be resolved at all," aborting before the font's own `/Differences` encoding or built-in encoding table (which need no Unicode) ever got a chance to name the glyph. That turned a real character into incorrect placeholder text everywhere the gap occurred, which for `comments.pdf` was dozens of times per page. Glyph selection is now attempted through the font's own encoding regardless, and only reported as unresolvable if that also fails.
- Strip `%` comments from a PDF content stream before decoding it, instead of handing it to `lopdf::content::Content::decode` as-is. Found by converting pdf.js's own `calgray.pdf`/`calrgb.pdf` test files, whose content stream lines each end in a `%` comment used purely for column alignment -- a legal use of the PDF grammar's comment syntax, since a comment runs to the next end of line and an empty one is allowed. `Content::decode` has a real parsing limitation where a `%` comment trailing an operator on the same line, rather than sitting alone on its own line, makes it drop every remaining operation in the stream silently: no error, no warning, just a page that renders blank. A smaller, hand-written reproduction of "a comment trails an operator" did not reproduce the bug; only the real file's own exact formatting does, so the regression test uses those bytes verbatim rather than risk exercising a different, merely similar-looking case.
- Fix three compounding defects found by converting real-world PDFs from pdf.js's own test corpus (`function_based_shading.pdf`), all in `ShadingType 1` (function-based) shading:
  - A function shading dictionary's own `/BBox` -- which one real producer's page-layout PDF sets alongside a non-standard `/Matrix` placed directly on the shading dictionary rather than on a pattern wrapping it -- was transformed by that `/Matrix` a second time on top of the transform its own coordinates already assumed, pushing the clip rectangle far off the page and hiding an entire, correctly-tessellated shading behind it.
  - The adaptive tessellator's axis-to-split heuristic starved one axis forever on a symmetric function (computing distance from the domain's center, say): sampled at a cell's frozen y=0/y=1 endpoints, both always equidistant from the center, the y-direction genuinely never shows any change no matter how far x is subdivided, not by floating-point coincidence -- so the heuristic kept "correctly" picking x, and y was never resampled at new points to discover that it does vary elsewhere. A capped streak now forces an occasional split of the neglected axis regardless of the heuristic, so both axes are guaranteed to eventually be resampled.
  - Exhausting the tessellator's cell budget -- expected on a genuinely discontinuous or high-frequency function, not just a pathological input -- was a hard error that failed the whole page; it now degrades to a warning and a lower-resolution rendering of just that one shading.
- Fill a path with a `ShadingType 4-7` (mesh: free-form, lattice-form, Coons-patch or tensor-patch) shading pattern, the same way as `ShadingType 1` below, clipped to the mesh's own vertex bounds so the SVG `<pattern>`'s necessary tiling does not repeat visibly beyond the shape the mesh actually covers. The clipped pattern approach also fixes that same visible repetition for `ShadingType 1`, clipping it to the function's own `/Domain`.
- Fill a path with a `ShadingType 1` (function-based) shading pattern. A shading pattern has no SVG gradient equivalent once it is not axial or radial, and the fill silently disappeared; tessellate it into an SVG `<pattern>` instead, the same adaptive tessellation the `sh` operator already uses, now shared between both.
- Respect PDF Optional Content Groups (layers): content wrapped in a `BDC /OC ... EMC` marked-content span, or an image or Form XObject with its own `/OC` entry, is now skipped when the document's default configuration (`/OCProperties /D`) turns that layer off, the same way every viewer already treats it. CAD- and GIS-exported PDFs commonly ship several such layers, and drawing all of them regardless of default visibility put content on the page that no viewer would ever show.
- Keep PDF text rendering mode 3 (invisible) as selectable, searchable SVG text with no paint, instead of dropping it. That mode is how a searchable scanned PDF hides its OCR text layer behind the scanned image, and text is the entire point of that layer; converting it to nothing turned a searchable document into one that was not. A Type3 font's glyph program always paints, so mode 3 is the one mode it still cannot approximate and continues to draw nothing there.
- Draw a PDF annotation's own `/AP` appearance stream: a filled-in form field's value and a sticky note's icon live only there, never in the page content stream, so a converter that reads only page content silently dropped them. Map the appearance's `BBox` onto the annotation's `Rect` the way the spec's own algorithm does, and skip Link and Popup annotations along with anything flagged Hidden or NoView, matching how viewers already treat them.
- Warn when a PDF Type0 font uses a CMap encoding other than Identity-H/V, instead of silently mispositioning its text. Character code equals CID only under Identity; a predefined CMap such as `UniJIS-UCS2-H` — the encoding non-embedded standard CJK fonts use — maps code to CID through a table this converter does not resolve, and reusing the code as the CID key against the font's own `/W` widths made Latin runs mixed into CJK text drift apart mid-word.
- Stop trusting an embedded font merely named "Symbol" or "ZapfDingbats" to match a system font of the same name. A word processor's own subsetted dingbat font commonly encodes its bullets at Private Use Area code points that mean nothing outside that specific embedded font, and treating the name as a green light left such bullets as a missing-glyph box everywhere the literal PUA text wasn't backed by that exact font — draw them as vector outlines instead, as already happens for every other embedded font.
- Select embedded TrueType/OpenType glyphs by the PDF's own character code before trying the ToUnicode-decoded Unicode value, whenever the font carries no `/Encoding` (a symbolic simple font, by the spec's own default). A subsetter commonly keys its cmap by sequential code (1, 2, 3, …) rather than true Unicode, so the previous order let a character whose Unicode value happened to fall in that range land on an unrelated glyph — punctuation and spaces most often, since their low codepoints collide with a subset's small code range. A DOCX round-tripped through a common PDF exporter rendered "document-svg / sample document" as "document2vgfVfsampleddocument".

- Let a stencil defer to the colours of the cell it is drawn for. mxStencil's `fill`, `stroke` and `inherit` name the cell's own colours rather than colours of their own, and reading them as literal colours left every stencil that uses them painted solid black — ten of draw.io's own stencil libraries, the network and rack sets among them.
- Draw every remaining shape draw.io implements in code that the example diagrams reach for. The painter grew what they needed: a gradient fill, a stroke colour and a stroke width per part. The shapes are the mock-up window, scroll bar, spinner, checkbox group, column chart, video player, map pin, ratings in stars and hearts, portrait and callout; the integration channels and the network bus; the iOS app tile, action sheet, location bar, striped and map backgrounds and pin; the Android status bar; the Bootstrap image and striped button; the infographic circular callout; the logic gates; the process column and valve; SysML's parameter node and item flow; the lean mapping lead time bar; the smiley faces; and the network icon, which draws the tile and then the stencil the style names on it.
- Convert the shapes draw.io draws as long runs of coordinates from the editor's own code rather than transcribing them, and keep them in `src/drawio/artwork.rs`.
- Across the 613 diagrams in the draw.io project's own example repository, 547 now convert without a single warning, up from 476 when this work started, and nothing is left undrawn except `mxgraph.world`, which ships only with the hosted editor, and the AWS 3D service glyphs, which live in the editor's own code and are named as missing in the warning.

- Draw the last of the shapes the example diagrams reach for: the arrows2 two-way, stylised and jump-in arrows, a data-flow store with its identifier band, SysML's accept-event and call-behaviour actions, a UML state, and BPMN's data object with the marks that say which way the data travels and whether it stands for a collection. 514 of the 613 diagrams in the draw.io project's own example repository now convert without a single warning, up from 476 when this work started; what is left undrawn, setting aside `mxgraph.world` and the AWS 3D service glyphs, is 43 occurrences of shapes used at most twice each.

- Write a draw.io page that has nothing on it at the size the model declares, and say so in the report, rather than leaving a page a few points across. draw.io stands its own "click here to edit" placeholder on such a page; that placeholder is not in the model, so drawing it here would put a shape in the output that the diagram does not contain.
- Draw the ArchiMate 3 elements: a frame from `archiType` with the badge in its corner that says which kind of element it is — goal, requirement, assessment, node, function, collaboration, event, process, actor, service and system software — plus the service and actor elements that are a badge and nothing else. A badge this does not know leaves the frame drawn and the corner empty rather than losing the element.
- Draw the rack units: a cabinet frame that snaps to a whole number of rack units and carries its rails and screws, a blanking plate shaded at each mounting ear, a cable duct with a bay every thirty three pixels, a shelf bracket and a patch panel in its own body colour.
- Draw the entity-relationship entity and relationship, including the second frame that marks a weak one, the C4 person, and the mock-up browser window with its tab, address bar and navigation icons. Across the 613 diagrams in the draw.io project's own example repository the diagrams that convert without a single warning go from 501 to 509.
- Say which side of a comparison drew nothing in `scripts/compare-drawio-export.py`. "One side is blank" hid whether the conversion had missed geometry draw.io drew, or whether the diagram simply had none; the first of those is a defect and the second is not.

- Draw the iOS 7 controls, and the shapes that carry a second colour of their own alongside the fill and stroke: the phone case with its screen, earpiece and home button; the status bar with its signal dots, wifi fan and battery; the page dots, download bar, slider, switch and home screen. A slider's track, a switch's off state and the status bar's ink are all named separately in the style, so the shaded painter now takes a stroke colour per part rather than using the shape's own throughout.
- Draw a polygon a style spells out. `shape=mxgraph.basic.polygon` carries its corners as fractions of its own box in `polyCoords`, and `polyCurves` bends a side by naming its control point, with one entry per side so a straight side keeps its place in the list. `polyline=1` leaves the shape open.
- Draw the rest of the lean mapping set — the lead time ladder, the FIFO lane and the lorry, whose wheels take the stroke colour — and the odds and ends a real diagram reaches for: the mock-up rule, button (rounded or chevron) and checkbox, the Bootstrap close cross, and the basic set's drop and obtuse triangle. Across the 613 diagrams in the draw.io project's own example repository the diagrams that convert without a single warning go from 495 to 501, and what is left undrawn, setting aside `mxgraph.world` and the AWS 3D service glyphs, is 69 occurrences of shapes used at most three times each.

- Draw the shapes a floor plan, a SysML activity diagram and a mock-up are made of, which draw.io implements in code rather than as stencils: a room's four walls, a flight of stairs with its landing, and a sliding door; the SysML activity and flow ends, control operator, object and item flows, parametric frame and port; and the mock-up controls several libraries each keep their own copy of — buttons rounded along one edge, rounded and inset rectangles, checkboxes and radio buttons. An anchor, which is there only to attach a connector to, now correctly draws nothing rather than a placeholder box. Also the callouts and the shaded infographic shapes (banner, single-fold banner, shaded triangle, pyramid and pyramid step, each drawn as a face with a light side and a dark one), and the plain names `isoRectangle`, `isoCube2`, `curlyBracket` and `mxgraph.basic.pie`. Across the 613 diagrams in the draw.io project's own example repository this takes the diagrams that convert without a single warning from 476 to 495.
- Draw the lean mapping shapes a value stream map is built from: the manufacturing process box with a band for its name, the data box ruled underneath it, the striped push arrow, the hooked physical pull and the schedule box. The three value-stream maps in the draw.io project's example repository were drawing sixteen placeholder boxes between them.
- Apply the named styles draw.io ships in its own stylesheet. A style string may name one instead of spelling its settings out, and ignoring them left every shape styled `plain-yellow`, `plain-blue` and the rest white with a black border rather than filled, bordered and shaded as the editor draws them.
- Draw the sheen `glass=1` asks for.
- Add `scripts/compare-drawio-export.py`, which measures a conversion against draw.io's own SVG export of the same diagram. Against the exports in the draw.io project's example repository, four of the six comparable diagrams now differ from the editor's own rendering on 0.14% to 0.60% of their pixels.
- Route a `segmentEdgeStyle` connector with square corners. draw.io turns these the same way it turns an orthogonal edge, and drawing them straight put diagonal lines through nine of the example diagrams.
- Meet a connector to the outline it points at rather than to the box around it. `perimeter=` names the rule — triangle, hexagon, step, parallelogram, trapezoid, lifeline and the rest — and 110 of the 613 example diagrams set one.
- Keep a label with `overflow=hidden` inside its shape, and stop such a label from stretching the page.
- Draw the plain style names draw.io registers without a library prefix: `umlDestroy`, `lollipop`, `requiredInterface`, `corner`, `switch`, `module`, `crossbar` and `dimension`.
- Split the draw.io reader into the parts that do each job — the model and page here, geometry, shapes, edges, labels, BPMN and shape libraries beside it — with byte-identical output across all 613 example diagrams.
- Draw a shape a library defines as empty as the nothing it is, instead of standing a placeholder in its place and asking for a library that is already loaded.
- Stop reading shape libraries once every shape a page asks for has been found. A diagram drawing from one library no longer reads the other two hundred: converting an AWS diagram against draw.io's whole 42 MB stencil set went from 0.55 s to 0.09 s.
- Draw the multi-coloured shapes: a mock-up pie chart takes a colour per slice from its style, and an infographic shaded cube takes its two face shades. Add the mock-up curly brace, the U-turn arrow and the remaining AWS 3D dashed connectors.
- Draw the shapes draw.io implements in code rather than as stencils, across the libraries that use them most: the AWS 3D isometric body and its ground connectors, the mock-up search box, combo box, icon grid and simple icon, the infographic ribbon and cylinder, lean mapping's outside sources and inventory box, the ring segment and arc from the basic set, floor-plan stairs, the iOS list band, the rack container and the Bootstrap rounded rectangle. An AWS 3D service says in its warning that only its body was drawn, because the glyph it carries lives in the editor's own code.
- Draw the entity-relationship connector ends. A tick for one, a crow's foot for many and a ring for zero are the notation an ER diagram is read by, and all six were being dropped with a warning, which left every relationship in a database diagram unreadable.
- Draw BPMN events, gateways and activities. draw.io builds these from three layers the style names separately — a gateway diamond, the event ring, and the symbol that says which event it is — so a message, timer, error, signal or terminate event now looks like one instead of like a box. A throwing or end event inverts its symbol's colours the way the editor does.
- Draw a table as the swimlane it is, so an entity's name sits in its header band instead of on top of its first row.
- Draw the UML component and its two sockets, and the folder that UML uses for a package, with the package's name in its tab when the style asks for it.
- Draw the remaining arrowheads draw.io defines: `box`, `dash`, `cross`, `circle`, `circlePlus`, `halfCircle` and `openAsync`.
- Draw draw.io shape libraries instead of standing a labelled box where the icon should be. A library is a drawing program per shape in mxStencil form, and `--stencils <file-or-directory>` points at draw.io's own stencil files so an AWS, Azure, GCP, Cisco or floor-plan diagram comes out with its real icons. A shape the diagram carries inline, as `shape=stencil(...)`, needs nothing at all. Across the 613 diagrams in the draw.io project's own example repository this takes the shapes left undrawn from 1,901 to 827, and the diagrams that convert without a single warning from 119 to 404.
- Draw the glyph a cloud tile names in its style. An AWS service tile keeps its colour from the style and its picture from `resIcon`, and drawing only the first left every tile in an architecture diagram a plain coloured square.
- Place a vertex that carries relative geometry where draw.io places it. `mxGeometry` on a vertex can hold fractions of the parent's size plus an offset, and ignoring that stacked every entry of a template's legend on top of the first one.
- Draw the floor-plan walls, corners, windows and doors, the UML start and end states, `mxgraph.gcp2.doubleRect` and the AWS group and tile frames that draw.io implements in code rather than as stencils.
- Restore a diagram from the URI-encoded copy older draw.io releases wrote. Three of the seven SVG exports in the draw.io project's own example repository store `content` as `encodeURIComponent` output rather than as the diagram itself, and every one of them was refused as "not an mxfile".
- Look a style token without `=` up as a named style instead of treating it as a shape. mxGraph ignores the ones it does not know, so the stray `9E9E9E` left in draw.io's own Google Cloud templates was being reported as an unknown shape on 54 of the project's example diagrams.
- Check a `<style>` rule as one string, resolving the entity references inside it, rather than refusing any rule that contains one. The old rule dropped 55 embedded pictures across the example corpus, and a reference was only ever refused because the text around it was checked one chunk at a time — which is also what let `u&#114;l(https://…)` through.
- Hold every coordinate and length a model declares inside a million pixels, and crop the page to the same range. A `width="1e308"` produced an SVG whose own width was a 300-digit number, which no renderer can open; the page now says in a warning that it was cropped.
- Draw nothing for `shape=waypoint`, fill and stroke only the requested sides of `shape=partialRectangle`, and treat `shape=table` and `shape=tableRow` as the rectangles they are. All three were drawing a placeholder box with a warning in real diagrams.
- Say what a file is when it has no diagrams: a draw.io shape library and a template index are both XML a user has on hand, and "declares no diagrams" named neither.
- Write draw.io files back out of SVG pages. `docsvg reverse pages/ --output diagram.drawio` packages each page as a picture in its own diagram, and an SVG that still carries the diagram source — what draw.io writes with "Include a copy of my diagram", and what the new `--embed-drawio-source` writes — is restored as the editable diagram it came from instead. A page restored that way never contributes its own bytes to the output, which is what lets a real draw.io export, whose labels are HTML inside `foreignObject`, be turned back into a diagram at all. `OpenXmlFormat` and `svg_to_openxml` are now `ReverseFormat` and `svg_to_document`; both old names still work. Node.js and Python take the same option as `embedDrawioSource` / `embed_drawio_source`.
- Accept the document type a real draw.io SVG export carries. Every one of them opens with the standard SVG 1.1 doctype, and refusing all doctypes refused exactly the files that most need reading; an entity declaration, which needs an internal subset, is still refused.
- Place an edge label where draw.io places it. `mxGeometry`'s `y` on an edge is the label's offset perpendicular to the line, and ignoring it left every "yes"/"no" sitting on top of its connector instead of beside it. Half the labelled edges in the draw.io project's own example diagrams set it.
- Draw nothing for `shape=group`. draw.io gives a plain grouping container that style, and treating it as an unknown shape put a stroked rectangle around every group in a real diagram. Add `umlLifeline`, `umlFrame`, `message` and `callout`, which the same diagrams use.
- Convert draw.io (diagrams.net) files. `.drawio`, `.dio` and `.xml` inputs are read as mxGraphModel, one SVG per `<diagram>` page, including the URI-encoded, raw-deflated, base64 body the editor writes by default. Basic and flowchart shapes, groups, styles, HTML labels, and straight, curved and orthogonal connectors with mxGraph's arrowheads are drawn; shape-library icons such as `shape=mxgraph.aws4.*` become labelled placeholder rectangles and are named in the warnings, because their outlines are defined by the editor's own stencils rather than by the file.
- Draw `curvedConnector2` through `curvedConnector5` as curves. They fell through to the bounding-box fallback, which put a stroked rectangle on the slide where a line should curve between two shapes.
- Read `<a:buChar>`, `<a:buNone>`, `marL` and `indent` from a PPTX paragraph's own properties. Bullets were only picked up from a master's text styles, so the usual way a deck writes a bulleted list produced no bullets at all, and the text wrapped against the master's margin rather than the paragraph's.
- Label line, area and scatter chart categories too, under the points rather than at slot centres, and leave the labels off once a chart has more categories than can be read.
- Read `<c:barDir>` and `<c:grouping>` on a bar chart. A horizontal bar chart was drawn as a column chart, and a stacked chart was drawn clustered, which turns a single column of 146 into two columns of 64 and 82.
- Draw the category names on a bar chart. They were already parsed out of the chart part but never reached the page, leaving bars with nothing to identify them.
- Ask for `pixelated` image rendering only where an image is actually drawn larger than its own pixel grid. `/Interpolate false` is about enlargement, but CSS `pixelated` also disables the area averaging every PDF viewer applies when reducing, which speckled scans placed at a fraction of their pixel size.
- Resolve XML entities in Office attribute values. The raw, still-escaped bytes were taken verbatim and escaped again, so an alt text of `R&D` reached the reader as `R&amp;D`. 58 of the 364 Office files in the review corpus carry an entity in a `descr`, `name` or `title`.
- Grow a PPTX table row to fit its wrapped cell text. `<a:tr h="...">` is a minimum height, and treating it as final clipped the second line off every wrapped cell.
- Render a PPTX gradient slide background as a gradient. `<p:bg>` was tracked as one colour, so a two-stop background collapsed to whichever stop was read last and a title slide meant to fade came out flat. 6% of the decks in the review corpus use one.
- Honour `showMasterSp="0"`. A layout that hides the master's shapes was ignored, so anything a template repeats on both — a footer, a logo — was drawn twice. 27 of 259 decks in the corpus set it.
- Undo PNG predictors on Flate images here instead of relying on the PDF library. `/DecodeParms` given as an indirect reference or as an array parallel to `/Filter` was not read at all, and the Average row filter was reconstructed as `left + above / 2` rather than `(left + above) / 2`. Either one turns a predicted image into noise with no warning anywhere; a 15-page deck rendered as static on every page.
- Parse an embedded Type 1 font program once per page instead of once per text-showing operator. `parse_type1` decrypts the eexec section and scans the whole program, and re-running it per operator dominated Type 1-heavy PDFs: a 252-page document went from 168 s to 11 s with byte-identical output.
- Ignore `a14:hiddenFill` / `a14:hiddenLine` compatibility paint on DOCX text boxes. Their black line colour was being read as the shape fill, covering the text with a solid black rectangle.
- Keep DOCX text box paragraphs that overflow the declared frame. Word's default `noAutofit` lets text spill out, so cutting the layout off at the frame height silently dropped every paragraph after the first in a short box.
- Resolve XML entity references in PPTX shape text, PPTX table text, DOCX text and chart labels. quick-xml reports these separately from text, so "R&D" reached the SVG as "RD"; 12.7% of the documents in the review corpus were losing characters this way.
- Emit each image's data URI once, as SVG 2 `href`, instead of repeating it in `xlink:href` for pre-2019 renderers. Image-heavy output shrinks by 40-48%. Renderers older than librsvg 2.46 will no longer show these images.
- Read a PPTX shape's extent as a magnitude, so a shape written with a negative `cx`/`cy` keeps its text instead of being dropped, and say "zero-sized transform" rather than "no explicit transform" when a shape really has one.
- Keep converting a PDF when one image cannot be decoded. An unusable image is now a page warning instead of an error that discards every other page, and the JBIG2 filter is named in that warning rather than relaying the decoder's "missing feature" text.
- Budget a PDF image against the samples it actually expands to instead of assuming RGBA. Ordinary 600 DPI bilevel scans no longer fail the whole document against the "RGBA limit".
- Warn when a PDF page consumes content operators but draws nothing, and say so explicitly when the document was encrypted — a stream left encrypted by a failed per-object decryption previously produced a silently blank page.
- Label an embedded Office image from its byte signature instead of its file name. A JPEG stored as `media/image1.png` was declared `image/png` in the data URI and dropped entirely by strict SVG renderers.
- Materialize a DOCX `PAGE` field that has no `fldCharType="separate"` marker, so footers that Word has never calculated still show a page number.
- Resolve PPTX slide-number fields to the page number instead of emitting PowerPoint's cached `<#>` placeholder text.
- Name the empty slide list or worksheet list when a PPTX or XLSX declares none, instead of reporting "input contains no renderable pages".
- Describe the actual encrypted-PDF behaviour in the README, `SUPPORT.md` and `ARCHITECTURE.md`: a user password is refused, while the empty-user-password form that only carries permission flags is opened, as any viewer opens it.
- Add the `setup-docsvg` and `document-preview` composite actions, plus a reusable `document-preview` workflow that converts the documents a pull request changes and reports page and warning counts.
- Add `.github/copilot-instructions.md` and `copilot-setup-steps.yml` so GitHub Copilot gets the build commands, the conversion accuracy rules and a prepared toolchain.
- Add Claude Code commands `/document-svg:convert`, `/document-svg:reverse`, `/document-svg:preview` and `/document-svg:setup`.
- Resolve the CLI through one shared `ensure-docsvg` script used by the skill wrappers and the GitHub CLI extension, including a release cache and an opt-in checksum-verified release download.
- Drop the Rust toolchain requirement from the plugin and extension installers.
- Add a crates.io publishing workflow using the configured trusted publisher.
- Document the GitHub, Copilot and agent integrations in `docs/GITHUB_INTEGRATION.md`.

## 0.1.1

- Add multi-platform release builds for Node.js bindings, Python ABI3 wheels and standalone CLI archives.
- Add checksum-verified publishing workflows for npm, PyPI and GitHub Packages, with separate build and publish permissions.
- Make the main and package READMEs English-first, with pip/npm/Cargo installation examples and an operational release guide.

- Integrate standard PDF font advances, bounded damaged-xref recovery, paper-aware XLSX pagination, PPTX fill handling and clearer encrypted/legacy Office errors.
- Add reproducible PDF/PPTX/XLSX/DOCX samples with checked source hashes.
- Bundle full third-party license notices, audit the locked dependencies and AFM provenance, and check notice freshness in CI.
- Upgrade the pinned checkout action and avoid duplicate branch/PR workflow runs.

- Replace the unmaintained font parser with `skrifa`, preserving TrueType/OpenType outlines and raw Type1/CFF fallbacks.
- Count serialized page size without retaining a second page-sized JSON buffer.
- Borrow SVG attribute/text strings when no escaping is needed, avoiding large image-data copies.
- Reuse the system font database across all pages of one reverse conversion.
- Ignore Python/native shared-library build artifacts in publication candidates.

## 0.1.1

- Add multi-platform release builds for Node.js bindings, Python ABI3 wheels and standalone CLI archives.
- Add checksum-verified publishing workflows for npm, PyPI and GitHub Packages, with separate build and publish permissions.
- Make the main and package READMEs English-first, with pip/npm/Cargo installation examples and an operational release guide.
- Integrate standard PDF font advances, bounded damaged-xref recovery, paper-aware XLSX pagination, PPTX fill handling and clearer encrypted/legacy Office errors.
- Add reproducible PDF/PPTX/XLSX/DOCX samples with checked source hashes.
- Bundle full third-party license notices, audit the locked dependencies and AFM provenance, and check notice freshness in CI.
- Replace the unmaintained font parser with `skrifa`, preserving TrueType/OpenType outlines and raw Type1/CFF fallbacks.
- Count serialized page size without retaining a second page-sized JSON buffer, borrow unescaped SVG strings, and reuse the system font database during reverse conversion.

## 0.1.0 — initial source release

- PDF, PPTX, XLSX and DOCX conversion to per-page SVG.
- Node.js in-memory previews, browser display helpers and Python bindings.
- SVG packaging into PPTX, DOCX and XLSX, without reconstructing Office semantics.
- Codex and Claude Code plugins, plus Japanese, English and Simplified Chinese preview guides.
- Bounded preview rendering, external-reference checks and non-overwriting atomic output publication.
- Dual licensing under MIT OR Apache-2.0, with required notice retention under the chosen license.

This is an alpha source release. Prebuilt npm/PyPI distributions and a separate GitHub CLI extension release are not yet published. Visual fidelity and supported format limitations are documented in `docs/SUPPORT.md`.
- Add bounded legacy Visio Compound File Binary previews for `.vsd`, `.vss`, `.vst`, and `.vsw`. The converter validates the CFB container and `VisioDocument` stream, renders stream/storage metadata, and keeps ShapeSheet geometry, macros, OLE payloads, and external links inert.

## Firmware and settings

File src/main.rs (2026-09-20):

use std::io::Read;
use std::path::PathBuf;

use anyhow::Context;
use clap::Parser;
use document_svg::{ConvertOptions, ReverseOptions, convert_path, svg_to_document};

const MAX_TRANSFORM_INPUT_BYTES: u64 = 512 * 1024 * 1024;

#[derive(Debug, Parser)]
#[command(
    name = "docsvg",
    version,
    about = "Convert documents, comic archives, diagrams, CAD/CAM/3D, simulation, raster, chart, and math inputs to SVG pages; use 'reverse' to export SVG pages",
    after_help = "Inputs include PDF/FDF/XFDF form data (.fdf/.xfdf), legacy Word Binary (.doc; CFB .dot templates), legacy PowerPoint Binary text previews (.ppt), legacy Excel (.xls/.xlsb), SYLK/DIF spreadsheets (.slk/.dif), FASTA/FASTQ sequences (.fa/.fasta/.fq/.fastq), Newick phylogenetic trees (.nwk/.newick/.tree), Stockholm alignments (.sto/.stockholm), CLUSTAL alignments (.aln/.clustal/.clustalw), NEXUS trees (.nex/.nexus), GenBank flat files (.gb/.gbk/.genbank), EMBL-Bank flat files (.embl/.emb), UniProtKB/Swiss-Prot protein flat files (.dat/.uniprot/.swissprot), RIS bibliography (.ris), SPICE/ngspice netlists (.cir/.sp/.spice/.ckt/.net), KiCad legacy Eeschema schematics (.sch), KiCad 6+ S-expression schematics (.kicad_sch), LTspice schematics (.asc Version signature), Autodesk EAGLE XML schematics (.sch eagle signature), Microsoft Project XML (.xml/.mspdi), OOXML Transitional/Strict and OpenDocument Office files (including Visio .vsdx/.vsdm/.vstx/.vstm/.vdx), iCalendar (.ics), legacy vCalendar (.vcs), vCard contacts (.vcf), MIME e-mail (.eml), Apple Mail EMLX (.emlx), Outlook messages (.msg), MBOX archives (.mbox), MHTML archives (.mht/.mhtml), DocBook 4/5 (.dbk/.docbook), TEI P5 scholarly XML (.tei/.tei.xml), ALTO OCR/layout XML (.alto/.alto.xml), METS archive XML (.mets/.mets.xml), MARCXML (.marcxml/.marc.xml), MODS XML (.mods/.mods.xml), MARC21 ISO 2709 (.marc/.iso2709), PREMIS XML (.premis/.premis.xml), IIIF Presentation JSON (.iiif.json/.manifest.json), EAD finding-aid XML (.ead/.ead.xml), EAC-CPF authority XML (.eac-cpf/.eac), Dublin Core XML (.dc.xml/.dublin.xml), ISO 19115/19139 metadata XML (.iso19115/.iso19139/.gmd.xml), UBL business documents (.ubl/.ubl.xml), XBRL 2.1 instances (.xbrl/.xbrl.xml), LandXML civil models (.landxml/.landxml.xml), MathML 3 formulas (.mathml/.mml), XMP metadata (.xmp/.xmp.xml), XDP/XFA packages (.xdp/.xdp.xml), Excel SpreadsheetML 2003 (.spreadsheetml/.xmlss), S1000D Data Module XML (.s1000d/.dmodule), DITA topics/maps (.dita/.ditamap), PDB coordinate models (.pdb/.ent), HWPX (.hwpx), COLLADA (.dae), X3D (.x3d), XMind (.xmind), NIfTI (.nii/.nii.gz), FITS (.fits/.fit/.fts/.fits.gz), MRC (.mrc/.map/.mrc.gz), NetCDF classic (.nc/.nc3/.cdf), SQLite (.sqlite/.sqlite3/.db), mmCIF/PDBx (.cif/.mmcif), MOL2 (.mol2), RDF Turtle (.ttl/.nt/.nq), EPS/PostScript (.eps/.ps), FictionBook 2 e-books (.fb2/.fb2.zip), PalmDOC/MOBI (.mobi/.prc/.azw), XPS/OpenXPS, CBZ comic archives, multi-page TIFF/BigTIFF, DICOM images (.dcm/.dicom), DICOM Structured Reports (SR), Encapsulated PDF Storage, DICOMDIR file sets, and V2000 and core V3000 MOL/SDF chemical structures (.mol/.sdf/.sd) and RXN reaction diagrams (.rxn), raster PNG/JPEG/BMP/GIF/WebP/Netpbm, SubRip/WebVTT subtitles (.srt/.vtt), TTML/DFXP subtitles (.ttml/.dfxp), XLIFF localization files (.xlf/.xliff), Jupyter notebooks (.ipynb), Quarto/R Markdown (.qmd/.Rmd), HTML/EPUB/FictionBook 2 (.fb2/.fb2.zip)/PalmDOC MOBI (.mobi/.prc/.azw), Markdown/plain text/AsciiDoc/reStructuredText (.rst/.rest), Org-mode (.org), GNU gettext catalogs (.po/.pot), BibTeX bibliographies (.bib/.bibtex), draw.io, GraphML graphs (.graphml), BPMN 2.0 diagrams (.bpmn/.bpmn2), CMMN 1.1 case plans (.cmmn), DMN 1.1–1.5 decision tables (.dmn), ReqIF 1.0.1/1.2 requirements (.reqif), XMI 2.1–2.5 models (.xmi), DOT/Mermaid/PlantUML/D2/Excalidraw, CAD/CAM/3D, glTF/GLB (.gltf/.glb), ASCII XYZ (.xyz), PCD (.pcd), ASTM E57 (.e57), Leica PTS/PTX (.pts/.ptx), and ASPRS LAS/LAZ (.las/.laz) point clouds, ANSYS CDB (.cdb), Abaqus (.inp), LS-DYNA Keyword (.k/.key), MEDIT ASCII/binary (.mesh/.meshb), OFF (.off), IFC SPF (.ifc), IFCXML (.ifcxml), and IFCZIP (.ifczip), Nastran Bulk Data (.bdf/.nas), KiCad PCB (.kicad_pcb), UNV/UFF (.unv), SU2 CFD meshes (.su2), OpenFOAM polyMesh cases (.foam), Tecplot ASCII CAE meshes (.dat/.tec/.tecplot/.tp), EnSight Gold ASCII cases (.case/.geo), PLOT3D ASCII grids (.p3d/.plot3d/.p3), VRML97 meshes (.wrl/.vrml), Gmsh/VTK, NetCDF classic (.nc/.nc3/.cdf), CSV/TSV, ARFF datasets (.arff), JSON-LD (.jsonld), OpenAPI/Swagger (.openapi.json/.swagger.json/.openapi.yaml/.swagger.yaml), AsyncAPI (.asyncapi.json/.asyncapi.yaml/.asyncapi.yml), JSON Schema (.schema.json/.jsonschema/.schema.yaml/.schema.yml), HAR (.har), WARC (.warc/.warc.gz), WACZ (.wacz), Postman Collection v2.1 (.postman_collection.json), GraphQL SDL (.graphql/.graphqls/.gql), Protocol Buffers (.proto), Kubernetes manifests (.k8s.yaml/.k8s.yml/.kubernetes.yaml/.kube.yaml), Docker Compose (compose.yaml/compose.yml/docker-compose.yaml/docker-compose.yml), GitHub Actions workflows (.github/workflows/*.yaml|*.yml), JUnit XML reports (junit.xml/test-results.xml/TEST-*.xml), SARIF 2.1.0 (.sarif/.sarif.json), Terraform JSON plans (tfplan.json/.tfplan.json), CycloneDX BOMs (bom.json/bom.xml/*.cdx.json/*.cdx.xml), SPDX JSON/tag:value (spdx.json/*.spdx.json/.spdx), JaCoCo/Cobertura coverage (jacoco.xml/coverage.xml), LCOV tracefiles (.info/lcov.info), JSON Patch (.jsonpatch/.json-patch), JSON Merge Patch (.mergepatch/.json-merge-patch), CSL-JSON (.csl.json/.csl-json), JSON Feed (.jsonfeed/.json-feed), CloudEvents JSON (.cloudevent.json/.cloud-event.json/.cloudevents.json/.ce.json/.cloudevent/.cloudevents), FHIR JSON (.fhir.json/.fhirjson/.fhir/.bundle.fhir.json/.fhir-bundle.json), Avro JSON (.avsc/.avpr/.avro.json/.avro-schema.json), ASAM OpenDRIVE (.xodr/.opendrive), ASAM OpenCRG (.crg), ASAM OpenSCENARIO (.xosc/.openscenario), ASAM OpenLABEL (.openlabel.json/.openlabel), OGC CityJSON (.cityjson/.city.json), OASIS STIX JSON (.stix.json/.stix), OASIS TAXII JSON (.taxii.json/.taxii), WSDL (.wsdl), OPML (.opml/.opml.xml), Apple Property List (.plist/.plist.xml), JSON, TOML configuration (.toml), YAML 1.2 configuration (.yaml/.yml), Java Properties (.properties), generic XML fallback (.xml), and JSON Text Sequences (.jsons/.jsonseq/.jsonl), ESRI ASCII Grid (.asc), dBASE III/III+ tables (.dbf), GeoPackage (.gpkg), RFC 8142 GeoJSON Text Sequences (.geojsons/.geojsonseq/.geojsonl), TopoJSON (.topojson), GeoJSON/GeoRSS/RSS/Atom/GML/GPX/KML/KMZ/Shapefile (.shp) maps, WKT/EWKT geometry, charts, LaTeX, QR, SVG, and EMF/WMF.\nReverse: docsvg reverse INPUT.svg --output OUTPUT.ext\nINPUT may also be a directory containing SVG pages; outputs include Office, draw.io, CAD/CAM/3D, simulation, diagram, table, math, PNG, WebP, HTML, UI code, and Data URI formats."
)]
struct Cli {
    /// Source PDF/FDF/XFDF form data (.fdf/.xfdf), legacy Word binary (.doc/.dot), text-only legacy PowerPoint binary (.ppt), Microsoft Project XML (.xml/.mspdi), legacy Excel, OOXML Transitional/Strict, OpenDocument, and Visio XML, iCalendar/vCalendar/vCard, EML/EMLX/Outlook MSG/MBOX/MHTML, gettext PO/POT catalogs, BibTeX bibliographies, JSON Text Sequences, NetCDF classic datasets, ARFF datasets, FASTA/FASTQ sequences, SYLK/DIF spreadsheets, JSON-LD, OpenAPI/Swagger, AsyncAPI, JSON Schema, HAR, WARC, WACZ, Postman, GraphQL, Protocol Buffers, Kubernetes, Docker Compose and GitHub Actions workflow and JUnit report, SARIF, Terraform plan, CycloneDX BOM, SPDX, coverage, LCOV, JSON Patch, JSON Merge Patch, CSL-JSON, JSON Feed, CloudEvents JSON, FHIR JSON, Avro schema/protocol, ASAM OpenDRIVE, ASAM OpenCRG, ASAM OpenSCENARIO, ASAM OpenLABEL, OGC CityJSON and OASIS STIX, TAXII, WSDL, OPML, Apple Property List, TEI, ALTO, METS, MARCXML, MODS, MARC21, PREMIS, IIIF Presentation, EAD, EAC-CPF, Dublin Core, ISO 19115/19139, UBL, XBRL, LandXML, MathML, XMP, XDP/XFA, SpreadsheetML, CML, RDF/XML and S1000D documents, and GraphML graphs, SubRip/WebVTT/TTML subtitles and XLIFF localization files, ESRI ASCII Grid/dBASE III/III+ tables/GeoPackage/GeoJSON Text Sequence/TopoJSON/RSS/Atom/GeoRSS/GML/GPX/KML/KMZ/Shapefile/WKT maps, DICOM medical images, Structured Reports and DICOMDIR file sets, CBZ, TIFF, Jupyter/Quarto, reStructuredText/Org-mode, ASCII XYZ, PCD, ASTM E57, Leica PTS/PTX, or LAS/LAZ point clouds, Abaqus/LS-DYNA/MEDIT/OFF/IFC/IFCZIP/Nastran/SU2/OpenFOAM/Tecplot/EnSight/PLOT3D/VRML/KiCad PCB/glTF/GLB, web/text, diagram, CAD/CAM/3D, simulation, raster, chart, math, QR, or SVG file.
    input: PathBuf,

    /// Directory that receives page-NNNN.svg and conversion.json.
    #[arg(short, long)]
    output: PathBuf,

    /// PDF page worker count. Office XML stays page-streamed.
    #[arg(short = 'j', long, default_value_t = 1)]
    jobs: usize,

    /// Maximum input size in MiB.
    #[arg(long, default_value_t = 512)]
    max_input_mib: u64,

    /// Maximum expanded PDF stream or ZIP part/image (Office, EPUB, 3MF, CBZ) in MiB.
    #[arg(long, default_value_t = 128)]
    max_entry_mib: u64,

    /// Maximum number of output pages/slides/sheets.
    #[arg(long, default_value_t = 10_000)]
    max_pages: usize,

    /// Maximum XML-like parser events per input part.
    #[arg(long, default_value_t = 5_000_000)]
    max_xml_events: usize,

    /// Omit provenance metadata from SVG output.
    #[arg(long)]
    no_metadata: bool,

    /// Floating-point precision for SVG coordinates.
    #[arg(long, default_value_t = 5)]
    precision: usize,

    /// Outline embedded PDF fonts for maximum fidelity instead of editable text.
    #[arg(long)]
    outline_embedded_pdf_text: bool,

    /// Keep a copy of the draw.io source in each SVG so it can be opened as an
    /// editable diagram again, in draw.io or with `docsvg reverse`.
    #[arg(long)]
    embed_drawio_source: bool,

    /// draw.io stencil XML file or directory to draw shape libraries with.
    /// Repeat for more than one.
    #[arg(long = "stencils", value_name = "PATH")]
    stencil_paths: Vec<PathBuf>,
}

#[derive(Debug, Parser)]
#[command(
    name = "docsvg reverse",
    about = "Package SVG pages into Office, draw.io, CAD/CAM/3D, simulation, diagram, table, math, image, or UI-code formats"
)]
struct ReverseCli {
    /// Source SVG file or directory containing SVG pages.
    input: PathBuf,

    /// Destination Office, draw.io, CAD/CAM/3D, simulation, diagram, table, math, PNG, WebP, HTML, UI-code, or Data URI file.
    #[arg(short, long)]
    output: PathBuf,

    /// Maximum combined SVG input size in MiB.
    #[arg(long, default_value_t = 512)]
    max_input_mib: u64,

    /// Maximum number of SVG pages.
    #[arg(long, default_value_t = 10_000)]
    max_pages: usize,
}

#[derive(Debug, Parser)]
#[command(
    name = "docsvg transform",
    about = "Transform and optimize SVG files (minify, monochrome, responsive, clean paths, strip empty groups)"
)]
struct TransformCli {
    /// Source SVG file (maximum 512 MiB), or '-' for standard input.
    input: PathBuf,

    /// Destination transformed SVG file, or '-' for standard output.
    #[arg(short, long)]
    output: PathBuf,

    /// Remove comments, empty spaces, and minify SVG output.
    #[arg(long)]
    minify: bool,

    /// Unify all fill and stroke colors to a single monochrome color (e.g. "#000000").
    #[arg(long)]
    monochrome: Option<String>,

    /// Remove fixed width/height and ensure viewBox is present for responsive scaling.
    #[arg(long)]
    responsive: bool,

    /// Round coordinates and path numbers to N decimal digits.
    #[arg(long)]
    precision: Option<usize>,

    /// Remove <metadata>, <desc>, and data-* attributes.
    #[arg(long)]
    remove_metadata: bool,

    /// Clean and optimize SVG path data (remove redundant zero-length segments and duplicate closes).
    #[arg(long)]
    clean_paths: bool,

    /// Strip empty <g> groups that contain no child rendering elements.
    #[arg(long)]
    strip_empty_groups: bool,
}

fn main() -> anyhow::Result<()> {
    let mut arguments = std::env::args_os().collect::<Vec<_>>();
    if arguments.get(1).is_some_and(|arg| arg == "convert") {
        arguments.remove(1);
    } else if arguments.get(1).is_some_and(|arg| arg == "reverse") {
        arguments.remove(1);
        arguments[0] = "docsvg reverse".into();
        return reverse(ReverseCli::parse_from(arguments));
    } else if arguments.get(1).is_some_and(|arg| arg == "transform") {
        arguments.remove(1);
        arguments[0] = "docsvg transform".into();
        return transform(TransformCli::parse_from(arguments));
    }
    convert(Cli::parse_from(arguments))
}

fn convert(cli: Cli) -> anyhow::Result<()> {
    let options = ConvertOptions {
        max_input_bytes: cli.max_input_mib.saturating_mul(1024 * 1024),
        max_zip_entry_bytes: cli.max_entry_mib.saturating_mul(1024 * 1024),
        max_pages: cli.max_pages,
        max_xml_events: cli.max_xml_events,
        include_metadata: !cli.no_metadata,
        precision: cli.precision.min(12),
        jobs: cli.jobs,
        outline_embedded_pdf_text: cli.outline_embedded_pdf_text,
        embed_drawio_source: cli.embed_drawio_source,
        stencil_paths: cli.stencil_paths,
    };
    let report = convert_path(&cli.input, &cli.output, &options).with_context(|| {
        format!(
            "failed to convert {} into {}",
            cli.input.display(),
            cli.output.display()
        )
    })?;
    println!(
        "converted {} {} page(s) to {} in {} ms",
        report.source_format, report.page_count, report.output_directory, report.elapsed_ms
    );
    if !report.warnings.is_empty() {
        eprintln!(
            "completed with {} distinct warning(s); see conversion.json",
            report.warnings.len()
        );
    }
    Ok(())
}

fn reverse(cli: ReverseCli) -> anyhow::Result<()> {
    let options = ReverseOptions {
        max_input_bytes: cli.max_input_mib.saturating_mul(1024 * 1024),
        max_pages: cli.max_pages,
    };
    let report = svg_to_document(&cli.input, &cli.output, &options).with_context(|| {
        format!(
            "failed to package {} into {}",
            cli.input.display(),
            cli.output.display()
        )
    })?;
    println!(
        "packaged {} SVG page(s) into {} ({})",
        report.page_count, report.output, report.output_format
    );
    for warning in &report.warnings {
        eprintln!("warning: {warning}");
    }
    Ok(())
}

fn transform(cli: TransformCli) -> anyhow::Result<()> {
    let mut bytes = Vec::new();
    let is_stdin = cli.input.as_os_str() == "-";
    let is_stdout = cli.output.as_os_str() == "-";

    if is_stdin {
        Read::take(
            &mut std::io::stdin(),
            MAX_TRANSFORM_INPUT_BYTES.saturating_add(1),
        )
        .read_to_end(&mut bytes)
        .context("failed to read from standard input")?;
    } else {
        let mut file = std::fs::File::open(&cli.input)
            .with_context(|| format!("failed to open {}", cli.input.display()))?;
        Read::take(&mut file, MAX_TRANSFORM_INPUT_BYTES.saturating_add(1))
            .read_to_end(&mut bytes)
            .with_context(|| format!("failed to read {}", cli.input.display()))?;
    }

    if bytes.len() as u64 > MAX_TRANSFORM_INPUT_BYTES {
        anyhow::bail!("SVG transform input exceeds maximum bytes ({MAX_TRANSFORM_INPUT_BYTES})");
    }

    let options = document_svg::TransformOptions {
        minify: cli.minify,
        monochrome: cli.monochrome,
        responsive: cli.responsive,
        precision: cli.precision,
        remove_metadata: cli.remove_metadata,
        clean_paths: cli.clean_paths,
        strip_empty_groups: cli.strip_empty_groups,
    };
    let transformed = document_svg::transform_svg(&bytes, &options).with_context(|| {
        format!(
            "failed to transform {}",
            if is_stdin {
                "stdin".to_string()
            } else {
                cli.input.display().to_string()
            }
        )
    })?;

    if is_stdout {
        use std::io::Write;
        std::io::stdout().write_all(&transformed)?;
    } else {
        if let Some(parent) = cli.output.parent().filter(|p| !p.as_os_str().is_empty()) {
            std::fs::create_dir_all(parent)?;
        }
        std::fs::write(&cli.output, &transformed)
            .with_context(|| format!("failed to write {}", cli.output.display()))?;
        println!(
            "transformed {} ({} bytes) -> {} ({} bytes)",
            cli.input.display(),
            bytes.len(),
            cli.output.display(),
            transformed.len()
        );
    }
    Ok(())
}

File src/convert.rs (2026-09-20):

use std::fs;
use std::io::{BufWriter, Cursor, Read, Write};
use std::path::Path;
#[cfg(not(target_arch = "wasm32"))]
use std::time::Instant;
#[cfg(target_arch = "wasm32")]
use web_time::Instant;

use serde::Serialize;

use crate::error::{Error, Result};
use crate::ir::{IDENTITY, Matrix, Node, Page, TextAnchor, compose};
use crate::svg::{SvgOptions, write_page};

const FORMAT_SNIFF_BYTES: u64 = 4096;

pub(crate) fn read_limited_file(path: &Path, max_bytes: u64, context: &str) -> Result<Vec<u8>> {
    let mut file = fs::File::open(path)?;
    let mut bytes = Vec::new();
    Read::take(&mut file, max_bytes.saturating_add(1)).read_to_end(&mut bytes)?;
    if bytes.len() as u64 > max_bytes {
        return Err(Error::LimitExceeded(format!(
            "{context} exceeds maximum bytes ({max_bytes})"
        )));
    }
    Ok(bytes)
}

#[derive(Clone, Copy, Debug, Eq, PartialEq, Serialize)]
#[serde(rename_all = "lowercase")]
pub enum SourceFormat {
    Pdf,
    #[serde(rename = "fdf")]
    Fdf,
    #[serde(rename = "xfdf")]
    Xfdf,
    #[serde(rename = "landxml")]
    LandXml,
    #[serde(rename = "mathml")]
    Mathml,
    #[serde(rename = "xmp")]
    Xmp,
    #[serde(rename = "xdp")]
    Xdp,
    #[serde(rename = "spreadsheetml")]
    Spreadsheetml,
    ProjectXml,
    Xml,
    Bpmn,
    Dmn,
    Cmmn,
    Reqif,
    Xmi,
    Ppt,
    Pptx,
    Xls,
    Xlsb,
    Xlsx,
    Doc,
    GeoJson,
    GeoJsonSeq,
    TopoJson,
    Geopackage,
    GeoRss,
    Feed,
    Gml,
    CityGml,
    CityJson,
    GraphGml,
    Gpx,
    Wkt,
    Kml,
    Kmz,
    Shapefile,
    Dbf,
    #[serde(rename = "esri_ascii_grid")]
    EsriAsciiGrid,
    #[serde(rename = "properties")]
    Properties,
    #[serde(rename = "plist")]
    Plist,
    #[serde(rename = "premis")]
    Premis,
    Docx,
    Drawio,
    Dxf,
    Gerber,
    #[serde(rename = "kicad_pcb")]
    KicadPcb,
    #[serde(rename = "kicad_sch_legacy")]
    KicadSchLegacy,
    #[serde(rename = "kicad_sch")]
    KicadSch,
    #[serde(rename = "ltspice_asc")]
    LtspiceAsc,
    #[serde(rename = "eagle_sch")]
    EagleSch,
    Hpgl,
    Dot,
    Mermaid,
    Markdown,
    Chart,
    Json,
    JsonLd,
    #[serde(rename = "iiif")]
    Iiif,
    JsonSeq,
    Graphml,
    Gexf,
    Xgmml,
    Toml,
    Yaml,
    Bib,
    Tex,
    Qr,
    Raster,
    Jpeg2000,
    Gcode,
    Excellon,
    Stl,
    Simulation,
    Gltf,
    Collada,
    X3d,
    Vrml,
    Step,
    Obj,
    Ply,
    Pcd,
    Pts,
    Ptx,
    Xyz,
    E57,
    Las,
    Unv,
    Csv,
    Emf,
    Excalidraw,
    PlantUml,
    D2,
    ThreeMf,
    Iges,
    Ifc,
    IfcXml,
    IfcZip,
    Html,
    Docbook,
    #[serde(rename = "dublin-core")]
    DublinCore,
    #[serde(rename = "iso19115")]
    Iso19115,
    #[serde(rename = "ubl")]
    Ubl,
    #[serde(rename = "xbrl")]
    Xbrl,
    Dif,
    Dita,
    #[serde(rename = "ead")]
    Ead,
    #[serde(rename = "eac-cpf")]
    EacCpf,
    Fasta,
    Fastq,
    Pdb,
    Hwpx,
    Xmind,
    Nifti,
    Fits,
    Gff3,
    Gtf,
    Mrc,
    Netcdf,
    Sqlite,
    Sylk,
    Cif,
    #[serde(rename = "cml")]
    Cml,
    #[serde(rename = "rdf-xml")]
    RdfXml,
    #[serde(rename = "bcfzip")]
    Bcfzip,
    #[serde(rename = "flat-opc")]
    FlatOpc,
    #[serde(rename = "aasx")]
    Aasx,
    #[serde(rename = "openscad")]
    OpenScad,
    #[serde(rename = "amf")]
    Amf,
    #[serde(rename = "plmxml")]
    PlmXml,
    #[serde(rename = "stepxml")]
    StepXml,
    #[serde(rename = "qif")]
    Qif,
    #[serde(rename = "b2mml")]
    B2mml,
    #[serde(rename = "jdf")]
    Jdf,
    #[serde(rename = "xjdf")]
    Xjdf,
    #[serde(rename = "tmx")]
    Tmx,
    #[serde(rename = "tbx")]
    Tbx,
    #[serde(rename = "gbxml")]
    GbXml,
    #[serde(rename = "idml")]
    Idml,
    #[serde(rename = "oaipmh")]
    OaiPmh,
    #[serde(rename = "onix")]
    Onix,
    #[serde(rename = "xpdl")]
    Xpdl,
    Mol2,
    Turtle,
    Eps,
    Epub,
    Fb2,
    Mobi,
    Eml,
    Emlx,
    Mbox,
    Mhtml,
    #[serde(rename = "mets")]
    Mets,
    #[serde(rename = "mods")]
    Mods,
    Msg,
    Ical,
    Vcalendar,
    Vcard,
    Vcf,
    Wig,
    Odt,
    Ods,
    Odp,
    Odg,
    Visio,
    Rtf,
    Xps,
    Tiff,
    Dicom,
    #[serde(rename = "dicom-sr")]
    DicomSr,
    DicomDir,
    Rxn,
    Mol,
    Sdf,
    Cbz,
    Abaqus,
    Nastran,
    #[serde(rename = "op2")]
    Op2,
    LsDyna,
    Jupyter,
    Jats,
    #[serde(rename = "tei")]
    Tei,
    Quarto,
    Medit,
    Off,
    Asciidoc,
    Arff,
    Bed,
    BedGraph,
    Rst,
    Org,
    Sam,
    #[serde(rename = "s1000d")]
    S1000d,
    Maf,
    #[serde(rename = "marcxml")]
    Marcxml,
    #[serde(rename = "marc21")]
    Marc,
    Po,
    Srt,
    Ttml,
    Vtt,
    Xliff,
    Svg,
    Su2,
    OpenFoam,
    OpenDrive,
    OpenCrg,
    OpenScenario,
    #[serde(rename = "openlabel")]
    OpenLabel,
    #[serde(rename = "openfoam-field")]
    OpenFoamField,
    Tecplot,
    Ensight,
    Plot3d,
    Newick,
    Stockholm,
    Clustal,
    Nexus,
    Genbank,
    Embl,
    Uniprot,
    Ris,
    Spice,
    #[serde(rename = "openapi")]
    Openapi,
    #[serde(rename = "asyncapi")]
    Asyncapi,
    #[serde(rename = "alto")]
    Alto,
    Wsdl,
    #[serde(rename = "opml")]
    Opml,
    #[serde(rename = "jsonschema")]
    JsonSchema,
    Cdb,
    Har,
    Warc,
    Wacz,
    Postman,
    Graphql,
    Protobuf,
    Kubernetes,
    Compose,
    #[serde(rename = "github-actions")]
    GithubActions,
    Junit,
    Sarif,
    #[serde(rename = "terraform-plan")]
    TerraformPlan,
    CycloneDx,
    Spdx,
    #[serde(rename = "stix-json")]
    StixJson,
    #[serde(rename = "taxii-json")]
    TaxiiJson,
    Coverage,
    #[serde(rename = "csl-json")]
    CslJson,
    Lcov,
    JsonPatch,
    JsonMergePatch,
    JsonFeed,
    #[serde(rename = "cloudevents")]
    CloudEvents,
    #[serde(rename = "fhir-json")]
    FhirJson,
    #[serde(rename = "fhir-xml")]
    FhirXml,
    #[serde(rename = "cda")]
    Cda,
    #[serde(rename = "iso20022")]
    Iso20022,
    #[serde(rename = "sbml")]
    Sbml,
    #[serde(rename = "cellml")]
    Cellml,
    #[serde(rename = "ocel-xml")]
    OcelXml,
    #[serde(rename = "energyplus-idf")]
    EnergyPlusIdf,
    #[serde(rename = "energyplus-epw")]
    EnergyPlusEpw,
    #[serde(rename = "rinex")]
    Rinex,
    #[serde(rename = "sat")]
    Sat,
    #[serde(rename = "sedml")]
    Sedml,
    #[serde(rename = "sbgnml")]
    Sbgnml,
    #[serde(rename = "omex")]
    Omex,
    #[serde(rename = "xdmf")]
    Xdmf,
    #[serde(rename = "pvd")]
    Pvd,
    #[serde(rename = "fds")]
    Fds,
    #[serde(rename = "abiword")]
    Abiword,
    #[serde(rename = "neuroml")]
    Neuroml,
    #[serde(rename = "biopax")]
    Biopax,
    #[serde(rename = "xsd")]
    Xsd,
    #[serde(rename = "xslt")]
    Xslt,
    #[serde(rename = "xsl-fo")]
    XslFo,
    #[serde(rename = "hdf5")]
    Hdf5,
    #[serde(rename = "cgns")]
    Cgns,
    #[serde(rename = "exodus")]
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

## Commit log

2026-09-08 Fix document rendering, performance and dependency notices (#1)
    * Replace unmaintained font parser and reduce conversion overhead
    * Integrate rendering fixes, reproducible samples and audited license notices
    * Keep generated license paths portable across platforms
    [sample.xlsx]
2026-09-08 Prepare 0.1.1 releases and trusted package publishing
    * Prepare verified multi-platform releases and package publishing
    * Retry release validation with approved pinned actions
    * Fix Python source licenses and Linux release build environments
    * Validate release metadata and use the native Alpine ARM linker
    * Reuse the shared Cargo release profile for native builds
    * Make npm README CommonJS examples directly runnable
    * Keep unaudited musllinux Python runtime out of the first release
2026-09-20 Expand document conversion coverage and update dependencies (#4)
    * Recover document content that conversion was dropping in silence
    Reviewing 413 real PDF, PPTX, XLSX and DOCX files turned up several ways a
    document could lose content with no error and often no warning.
    Text the parsers discarded:
    - quick-xml reports `&amp;` as `Event::GeneralRef`, not as text. PPTX shape
    text, PPTX table text, DOCX text and chart labels only handled
    `Event::Text`, so every ampersand vanished and "R&D" reached the SVG as
    "RD". 12.7% of the corpus was losing characters this way. XLSX already got
    this right; its decoder now lives in `ooxml` and everyone shares it.
    - `a14:hiddenFill` / `a14:hiddenLin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
    [binary_line.dxf, legacy_sample.xls, ods_image.ods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]
2026-09-21 Rewrite the project site copy and deploy Pages on push (#9)
    * Rewrite the project site copy and deploy Pages on push
    Rewrite the English, Japanese and Chinese site copy for people deciding
    whether to use document-svg: a new "Why use it" section explains the
    benefits (local-only conversion, output anyone can open, an honest report
    of what was missed, inert handling of macros and scripts, one tool for
    many formats, and the way back to Office/CAD). Use cases, the AI-agent
    notes and the fidelity tiers now use plain language instead of API names.
    The headline numbers were stale (60+/20+); they are now counted from
    formats.json at load time. Add the missing legacy Visio gallery sample,
    which ret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
2026-09-21 Split the project site into pages by reader question (#10)
    The single page mixed the pitch, a 270-row format table, 50 samples and
    install instructions. Split it into pages that each answer one question:
    home (is this useful to me?), use cases (what changes, and how do I
    begin?), formats (will my file work?), samples (what does it look like?),
    get started, safety & limits (can I use it on work files?) and AI agents.
    Pages with several sections get a sidebar that collapses into an "On
    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
2026-09-21 Rewrite the READMEs and package pages for people (#13)
    The English and Japanese READMEs opened with a single paragraph listing
    hundreds of extensions and a 300-row matrix, so what the project does and
    how to try it were hard to find. Rewrite them, and add a Chinese README,
    in the order a newcomer reads: what it is, why use it, what people use it
    for, install, try it, show it in an app, turn SVG back into files, a
    format overview, AI and GitHub integration, safety and limits, and
    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
2026-09-21 Put search terms in page titles and add a social preview card (#16)
    * Put search terms in page titles and add a social preview card
    Page titles described the benefit but left out the words people search
    for ("PDF to SVG", "PDFをSVGに変換"), so they now name the formats while
    still reading naturally, in English, Japanese and Chinese.
    Shared links showed text only. Add a 1200x630 card (assets/og.png,
    rendered from assets/og.svg with real sample conversions) as og:image
    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
2026-09-21 Prepare v2.0.1 release (#17)
    * Prepare v2.0.1 release
    Bump the crate, Node, Python and WebAssembly packages, the plugins and
    the publish workflow defaults to 2.0.1, and date the changelog entry
    covering the README and package page rewrite, the site, and the
    document preview fixes.
    * Say where packages come from and where they install
    The READMEs gain a table of package pages (npm, PyPI, crates.io, GitHub
    Releases) with where each one installs and how to check it, and the npm
    and PyPI READMEs say the same briefly. The site's getting-started page
    links the package pages and docs.rs.
    The sample guides now open with what the samples are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
2026-09-21 Rewrite the Node.js preview guides as a step-by-step walkthrough (#19)
    The guides opened with a paragraph listing more than a hundred formats,
    still said "after publishing", and mixed English terms into the
    Japanese and Chinese text. They now walk through what a developer does:
    convert on the Node.js side (including saving an upload to a temporary
    file and Electron's main process), show pages as images, tell people
    when something was approximated, add a copy button, and set limits for
    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
2026-09-29 Merge outstanding branches into main (#23)
    * Preserve completed Claude Code fixes and sample documents
    * Keep unaudited mus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
    [sample_r12.dwg, sample_r12_attr_dim.dwg, sample_r12_insert.dwg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]
2026-10-18 Fail the publication check when an action pin is not allowed (#31)
    GitHub refuses runs whose actions are outside the repository's selected
    actions list before any job starts, and that startup failure is not
    reported as a pull request check. The github-actions bump in #28 moved
    setup-node and upload-artifact to unlisted SHAs, so Browser WebAssembly,
    Copilot setup steps and Build release artifacts stopped starting on main
    while the PR looked green.
    Mirror the allowlist in .github/allowed-actions.txt and check every
    workflow and composite action against it; --remote also compares the
    mirror with the live repository setting.
2026-10-30 Fail the pin check on allowlist entries no workflow uses
    Seven stale pins had built up because the check only caught missing
    entries. Treat unused ones as findings too, so each bump swaps the old
    pin out instead of widening the allowlist.
